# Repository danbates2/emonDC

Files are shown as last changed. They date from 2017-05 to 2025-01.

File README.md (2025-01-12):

# **emonDC**

emonDC is a project aiming to develop DC current and voltage measuring tools compatible with openenergymonitor.org project.<br>
The main board in development is emonDCduo, a dual-channel generator/battery monitor, WiFi enabled, aimed at solar/battery systems.

### Project status: Reviewing Project. Develoment Units not available.

#### https://shop.openenergymonitor.com/

<br/>

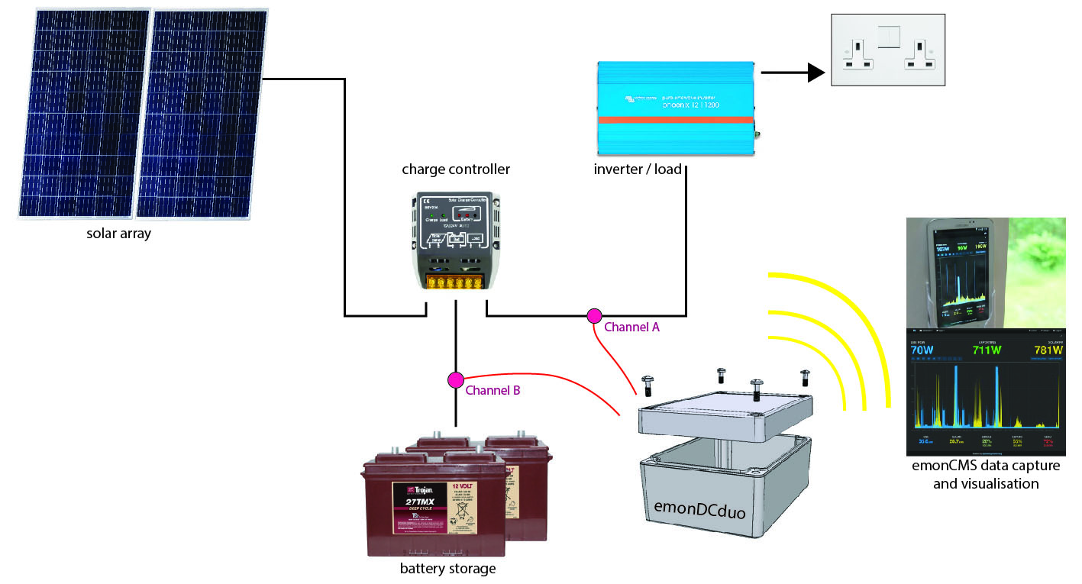
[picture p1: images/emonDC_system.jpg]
Example System Schematic


## Target Uses

- 12V, 24V and 48V Solar PV systems, up to 65V
- Battery monitoring.
- Remote DC datalogging.

**Be safe. Extra-low voltages can still mean high currents.**

[Find Documentation on some fundamental DC monitoring concepts in the 'doco' folder, which contains a reference pdf.](/doco/)

## Contents
<!-- toc -->
- [Target Uses](#Target-Uses)
- [Features](#Features)
- [Hardware Options](#Hardware-Options)
  * [The Shunt](#The-Shunt)
  * [Internal Shunt Cable Terminations](#terminations-for-onboard-shunts-up-to-50amps)
  * [External Shunt](#terminations-for-external-shunts)
  * [Power Supply](#power-supply-options)
  * [Enclosures](#Enclosures)
  * [Extra Modules](#module-options)
- [Firmware](#Firmware)
- [Customisations](#other-customisation)
- [Setup Guides](#setup-guides)
- [Support](#online-support)
- [Safety](#Safety)
- [DC Monitoring Approaches](#approach)
- [Project Aims](#project-aims)
- [License](#license)

<!-- tocstop -->

## Features

Latest spec:

- Two-channel high **only** DC current and voltage sensing, up to 64.4V or 75V, suitable for a wide range of low-voltage generator/battery systems.
- 50Amps onboard shunt rating or 1000A external shunt rating.
- Hall-effect current sensor footprint alternative for isolated current only measurement.
- Waterproof, clear-top plastic case.
- 128 x 32 OLED display option.
- WiFi Connectivity.
- Low-power mode (10mA draw).
- Accurate 12-bit ADC.
- Over-voltage and reverse voltage protected (fuses).

Also:
- It can function as independent unit self-powered using an onboard buck regulator module, powered from either measurement channel. Data can be stored locally to a MicroSD card, keeping time with on-board RTC and coin-cell.
- Radio transmission of data possible through RFM69Pi module.
- Voltage divisions for reference voltages easily modified by soldering for maximum resolution for given system.
- The I2C port can connect control boards for power management, in development.
- Skipping wireless transmission, a physical cable UART connection is possible, compatible with RS485 pending testing.
<br>

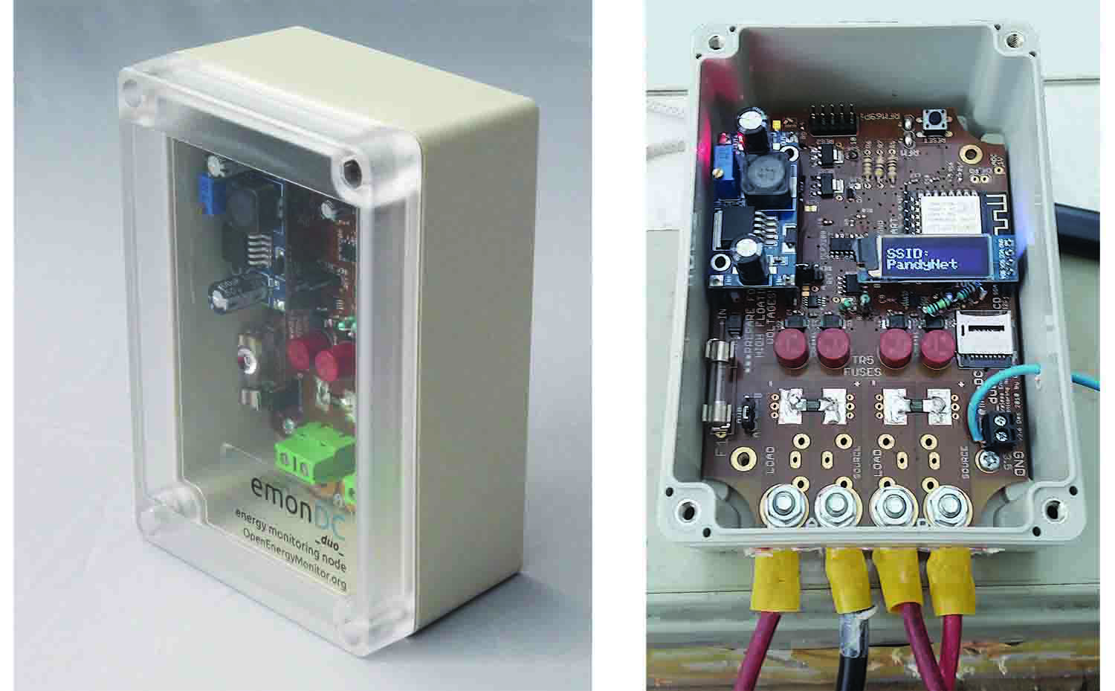
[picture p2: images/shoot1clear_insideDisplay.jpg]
 

<br>
<br>

## Hardware Options

emonDCduo as designed here has shunt, termination, power-supply and other module options.<br>
[See this demo video of the options](https://vimeo.com/319164161), listed below in detail.

#### The Shunt
Onboard @ 50Amps max  ||  External @ 1000Amps max.<br>
Onboard shunts should be selected to not dissipate more than 50% of their rated value continuously [shunt power calculator](https://github.com/danbates2/emonDC/tree/master/calculators).

#### Terminations for Onboard Shunts (up to 50Amps)
- For 10mm2 cable (50Amps approx). [10.16mm pitch Terminal Block](https://raw.githubusercontent.com/danbates2/emonDC/master/images/v3.6_terms_10.16mm.jpg), such as [this](https://uk.farnell.com/2668653).
- For 4mm2 cable  (25Amps approx). [7.62mm pitch Terminal Block](https://raw.githubusercontent.com/danbates2/emonDC/master/images/v3.6_terms_7.62mm.jpg), such as [this](https://uk.farnell.com/2579818).
- For 6mm2 cable (35Amps approx). [5mm Ring Terminals bolted on](https://raw.githubusercontent.com/danbates2/emonDC/master/images/v3.6_terms_ring.jpg). Ring terminal outer-diameter not exceeding 11.0mm.  
- [Directly soldered cable](https://raw.githubusercontent.com/danbates2/emonDC/master/images/v3.6_terms_bare.jpg), using the bolt mounts.

#### Terminations for External Shunts
- Any of the above, 7.62mm pitch Terminal Block recommended.
- [Example of external shunt (external link)](https://uk.farnell.com/1339341).

#### Power Supply Options
Using a buck regulator the board can be self-powered from either current sense channel.

-  [My own DC-DC buck regulator](https://raw.githubusercontent.com/danbates2/emonDC/master/images/buck_reg_green.jpg) featuring under-voltage lockout for battery protection, adjustable output voltage, rated at 3A for 10s or 1A continuous.
_note: using an onboard buck regulator is preceded by fuse F1._

- The [LM2596 buck modules on ebay](https://raw.githubusercontent.com/danbates2/emonDC/master/images/LM2596_dc-dc_buck_module.jpg), shown [here](/images/buck_reg_blue.jpg) fitted.
_note: using an onboard buck regulator is preceded by fuse F1._

- [5V input with 5.08mm pitch Terminal Block](https://raw.githubusercontent.com/danbates2/emonDC/master/images/v3.6_terms_v5input_block.jpg) for 5V direct input. I could not enable a USB connection for the safety reasons in floating-ground systems.

<br>

#### Enclosures

emonDCduo has been designed for waterproof plastic enclosures from Lincoln Binns.
<br>
Holes can be drilled easily, or prepared units can be bought from the OpenEnergyMonitor shop.
<br>
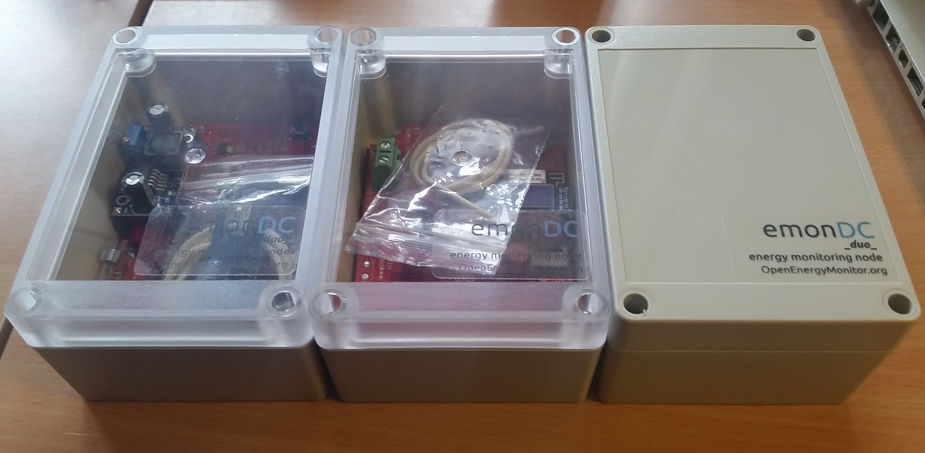
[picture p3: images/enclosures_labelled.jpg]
See image.


<br>

#### Module Options
**I2C modules:**
- **128x32 I2C OLED Display module** cycles through real-time and daily data, including network information if connected.
- **RTC based on PCF8523**, with coin cell backup, parts sold as kit.
- Any I2C control module can be fitted in parallel. Search for 'i2c io expander module board' for some options, PCF8574 and PCF8575 based modules have been tested and work fine.
<br>

**Other modules:**
- **RFM69Pi radio module** from OpenEnergyMonitor, typically 433MHz.
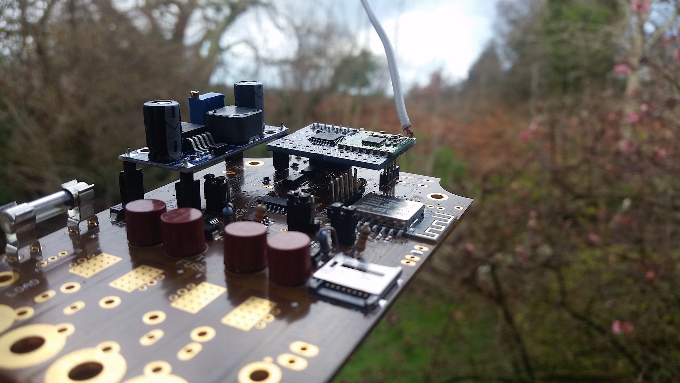
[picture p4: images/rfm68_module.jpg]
The board sets sail with a RFM69Pi module

The board sets sail with a RFM69Pi module
<br>

<br>

## Firmware

Find firmware here:<br>
https://github.com/danbates2/emonDC/tree/master/firmware<br>
It is based on emonESP, and detailed instructions on compiling and uploading the firmware can be found in it's documentation. <br>
https://github.com/openenergymonitor/EmonESP
<br>
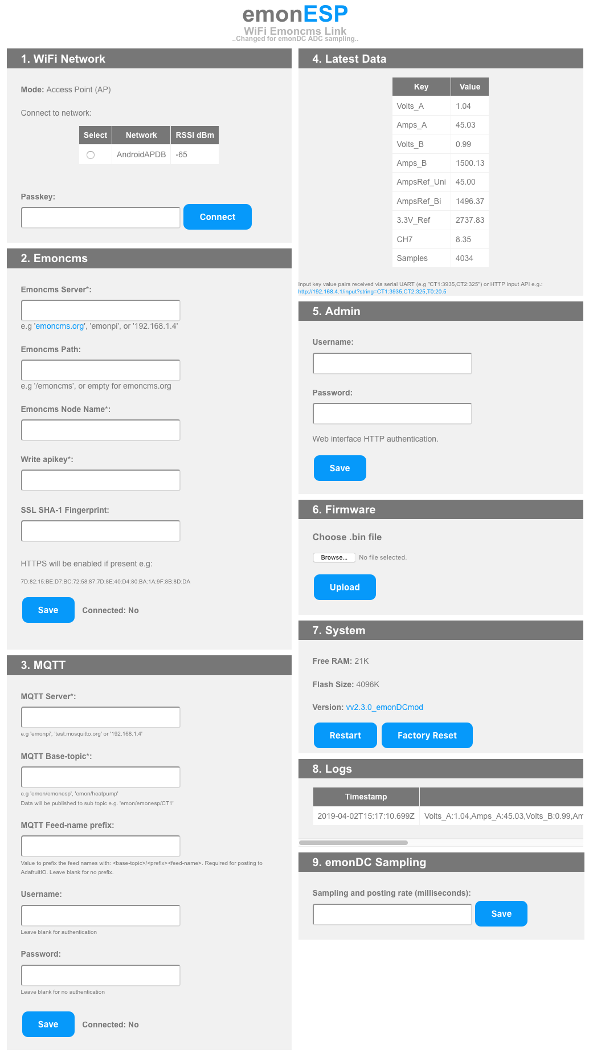
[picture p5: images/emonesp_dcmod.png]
Firmware web-interface screengrab


<br>

## Other Customisation

Below are a set of images outlining some other customisations.
<br>

- [GND connections, for the power-supply earth with a 4mm ring terminal on a mount. The terminal block for a gnd connection or shunt-lead shielding, if used.](https://raw.githubusercontent.com/danbates2/emonDC/master/images/v3.6_overlay_gnd.jpg)
- [5V input location.](https://raw.githubusercontent.com/danbates2/emonDC/master/images/v3.6_overlay_5v.jpg)
- [Power Select header, for bringing power into an on-board buck regulator, if used.](https://raw.githubusercontent.com/danbates2/emonDC/master/images/v3.6_overlay_pwr.jpg)
- [Reference voltage and line voltage divider resistors.](https://raw.githubusercontent.com/danbates2/emonDC/master/images/v3.6_overlay_resistors.jpg)
- [Shunt amplifier 'reference select' headers, for uni or bi-directional measurement.. Typically generator (uni-directional and battery (bi-directional).](https://raw.githubusercontent.com/danbates2/emonDC/master/images/v3.6_overlay_refsel.jpg)
- [RFM69Pi headers.](https://raw.githubusercontent.com/danbates2/emonDC/master/images/v3.6_overlay_rfm.jpg)
- [3D Printed Case.](https://raw.githubusercontent.com/danbates2/emonDC/master/images/3dprinted_case_1.jpg)
- [Lightning protection using Gas Discharge Tube (GDT) (external link).](https://uk.farnell.com/1843306)

## Setup Guides

*Plan your cabling and equipment to allow installation of this energy monitor.*<br>
*Have an understanding of [shunts](https://en.wikipedia.org/wiki/Current_sensing#Shunt_resistors), [high-side vs low-side shunt monitoring](http://www.worldofindie.co.uk/?p=216), and whether or not your electrical Ground needs earthing or can float.*

#### Example 1; 'standard' emonDCduo with enclosure, ring terminals and on-board power supply.

Tools needed: screw driver / drill, crimper / pliers, 8mm spanner or ring socket (ring socket easier). And of course, something to cut cable and strip the plastic insulation from the ends.

When looking at the PCB board top-side, the inputs are labelled 'source' and 'load'. The source is connected to the current origin (+ive side of shunt) and the load is connected to the destination (-ive side of shunt).

- Mount enclosure, then mount PCB with bolts ready.
- Connect current-carriers, cut cables and crimp on the ring terminals.
- Power up and log in via WiFi to enter credentials and other emonESP settings.

<details><summary>Detailed instructions (spoiler alert!) :</summary>
<p>

1. Purchase 'standard' board through Megni shop, select hardware options to complete purchase.
2. Take the enclosure and drill out access according to [this diagram]() (pre-drilled available from shop).
3. Select a location near the current carrying cables and mount the empty enclosure, screwing or bolting it to a surface.
4. You need two M5 bolts for each current channel. Put a serrated washer on each bolt, insert the bolts from the underside of the PCB, and then mount the PCB with the bolt threads showing, perhaps applying sideways pressure to the bolt to keep them from falling out.
5. Use the M3 screws provided to mount the PCB to the enclosure.
6. **Disconnect power from cables to be cut.** Make the cuts and strip 15mm from the ends.
7. With a crimping tool or pliers, crunch the ring terminals onto the copper cable ends, you should not be able to pull the cable out of the crimped end..
8. Note the 'source' and 'load' labelling on the board, bring the ring terminals onto the bolts and place the flat washer, then fit the nut.
9. Tighten all bolts holding onto the crimp to keep it from spinning, the serrated washer will eventually grip and greatly help to make it tight.
10. Connect the earth via the terminal or a by using a small ring under a mounting screw.

11. Install buck-regulator, power up and log in to to the device by WiFi, here you can enter emoncms credentials, and other settings as found in emonESP.

</p>
</details>

#### Example 2; 'minimal' PCB, with enclosure, 5V input block, and external shunts.
Soldering required for minimal functioning shown below.<br>
Then solder in two 5.08mm terminal blocks for the 5V and GND inputs.<br>
Then [7.62mm terminal blocks](https://raw.githubusercontent.com/danbates2/emonDC/master/images/v3.6_terms_7.62mm.jpg) (recommended) for connecting external shunts.
<br>
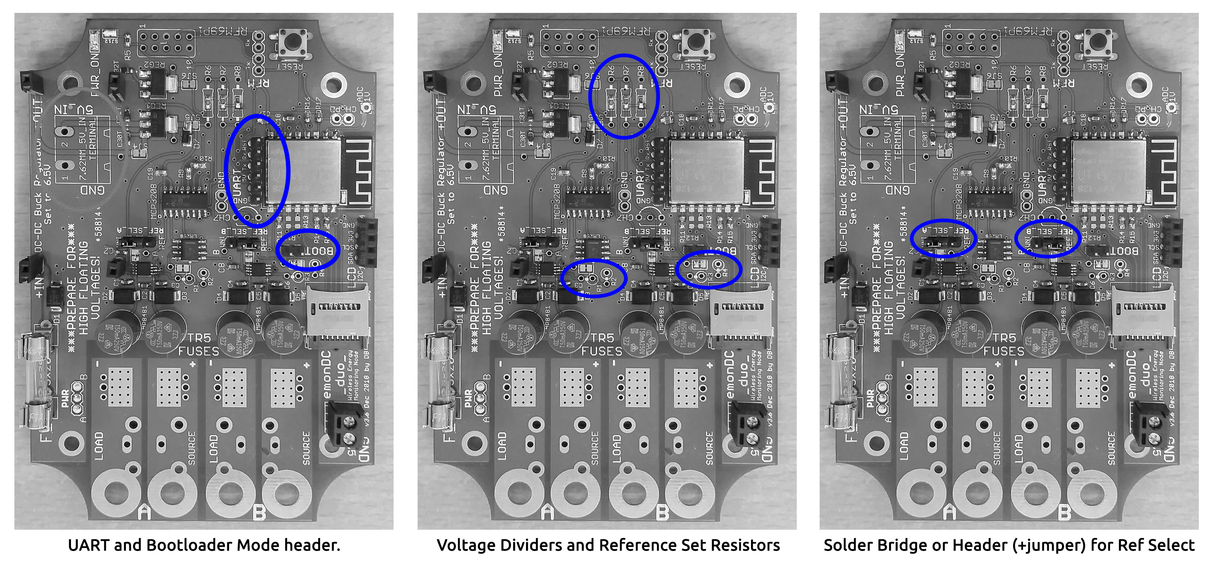
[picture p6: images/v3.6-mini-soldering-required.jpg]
Soldering Required


## Online Support

. Find answers, post questions, or msg me directly at https://community.openenergymonitor.org/  .  My username is @danbates

. Raise issues through this repo at the Issues tab.

<br>

## Measurement of direct current (DC).

This is a project description but also a collection of ideas and findings.
The diversity of approaches could be illustrated by these two websites:
- https://www.coolcomponents.co.uk/attopilot-voltage-and-current-sense-breakout-180a.html
- http://www.victronenergy.com/upload/documents/Datasheet-Battery-monitoring-EN.pdf

## Safety

**It's often good practice to disconnect the power before working on cables even in extra-low voltage systems**

**Be aware of working voltages!**

**Be aware of available Amperage, and the possibility of strong currents even in extra-low voltage systems.**

**Isolation.** The protection of users and connected devices from floating ground voltages in certain applications is very important. The approach at present is to make use of suitable physical isolation and warning labels. Bright warning labels stating ‘disconnect DC system before connecting UART’ or ‘ensure common ground between DC system and other devices to be connected’ or something similar, pending advice.
<br/>

Secondly, short circuit protection needs to exist at different levels of the hardware design to avoid inadvertent damage to the unit, by assembly faults on part of the manufacturer (PCB and assembly) or assembler, or the user upon installation. This has been achieved by adding fuses and buffering certain inputs with resistors. The layout of the components factors into the safety significantly!
<br/>

Thirdly, transient and reverse voltage protection. The TVS diodes specified seem to do a good job. I've taken a sparker from a cigarette lighter and shoved a few kV into the inputs while it was running. It worked just fine, after a reset.
<br/>

The unit is defined as a Protected Extra-Low Voltage (PELV) device, and should be, if all goes well, CE certified for safety.

## Approaches
Hall-effect DC monitoring ICs are simple and provide a degree of electrical isolation, however, they are inflexible and costly. This will certainly change in time as the technology develops.
<br/>

Shunt monitoring potentially provides greater flexibility, high accuracy and cost-effectiveness, and is the route selected for emonDCduo.

1. The range of requirements in DC monitoring applications require a flexible approach because of:<br/>
a. Unidirectional vs bidirectional measurement needs.<br/>
b. Amperage ranges and associated cable cross sectional area. Current carriers in DC systems can range from 4mm<sup>2</sup> to over 25mm<sup>2</sup>. The target measurement range has significant physical design implications.<br/>
c. Different cable dimensions require terminations suitable to their size and application (screw terminals, bolt ring terminals, soldered connections, etc.) there is no single solution.<br/>
d. Whole battery systems can be monitored with one shunt or individual cells of the system can require a multi-cell monitoring unit.<br/>
e. I also consider high humidity, marine and automotive applications, and have designed DCduo for a waterproof case.<br/>
f. A wide range of working voltages.

2. When I consider cable sizes and suitable cable terminations, the design challenge of making a suitable unit for a wide current range makes it difficult to see any one PCB realistically and cost-effectively meeting ALL requirements. Unlike in many AC requirements where a different CT and burden resistor can be selected, DC demands a more targeted approach due to the different physical dimensions of suitable terminations.
This possibly leads to the solution of designing several different boards according to the different requirements.
I'm designed emonDCduo to be an allrounder as much as possible, with the option of external shunts for amperages up to 1000A.

  The approach selected for first production has been dubbed emonDCduo, onboard shunts and pheonix connectors for external shunts ensure flexibility.

3. Given the nature of solar, wind and various DC applications there a requirement for a buck regulating supply, probably isolated. There needs to be a regulated and smooth output for powering the shunt monitor and other ICs.

5. Failsafe monitoring... Fuses between the shunt and monitor to protect from short circuit conditions. Do the fuses need monitoring?

6. High-side vs. low-side sensing… It'd be useful if this shunt monitor was capable of handling both applications, which means using a shunt monitor IC capable of high-side and low-side measurement. The device should ideally handle a wide common-mode voltage range, say up to 80V, and protection be in place for voltage over the common-mode voltage limit of the chip.

## Wider Project Aims

- Education on working with installing hardware, cabling, the use of tools and various practical aspects.
- Create as flexible as possible unit. Aiming primarily at domestic solar, wind and battery applications.
- Compare hall-effect type to shunt monitor type DC measuring approaches, particularly in relation to safety, accuracy and flexibility, as the tech develops.
- Integrate wireless Tx function using RFM69Pi.
- Integrate LAN cable connectivity.
- Investigate a calibration routine.
- Review case design periodically.
- Look at the energy efficiency of different manufacturing approaches.
- Make units!

**Questions…**
- What’s the relationship to different amperages, cables sizes and suitable cable terminations at the device?
- How high a current can the PCB copper layer handle?
- How does heat dissipate through the PCB and how does this effect the value being monitored? Is a temperature sensor required for factoring in temperature drift?

Several spinoff boards have derived of this project, in various stages of completion, the latest being the ACS770 or 772 series hall-effect current sensor breakout board. Also, an isolated FTDI adaptor, emonDCmini targeted at single channel DC monitoring with WiFi capabilities, and an emonDC shield for Arduino pattern.
<br><br>
What I'm calling emonBuck is also available, as a switching buck regulator with low-voltage lockout and adjustable output. 1Amp rated, 3A for 10 seconds.

## License
- Hardware licensed according to the TAPR Open Hardware Licence v1.0. Documentation free to use and change with accreditation to Daniel Bates @danbates2.
https://www.tapr.org/TAPR_Open_Hardware_License_v1.0.txt
- Software licensed licensed to GNU General Public License v3. Free to use and change with accreditation to OpenEnergyMonitor.org.
https://www.gnu.org/licenses/gpl.html

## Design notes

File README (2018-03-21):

emonDC
Project status: in production. expected release May 2018.

Measurement of direct current (DC).
This is a project description but also a collection of ideas and findings. All thoughts welcome.
The diversity of approaches could be illustrated by these two websites:
https://www.coolcomponents.co.uk/attopilot-voltage-and-current-sense-breakout-180a.html
http://www.victronenergy.com/upload/documents/Datasheet-Battery-monitoring-EN.pdf
My approach won’t be the only way but you’ll get an idea as you read on. Hopefully it makes sense. I welcome any and all feedback and hope for this to be as complete a project in theory before I begin schematic and PCB designs. Hey, I might even be close to making a decision by now… Also, this isn’t intended to claim ownership of the idea, if anyone wants to pick up the pieces and go for it they’re welcome.

emonDC Project
This unit will be a dual  shunt-monitoring device with wireless Tx capabilities. The device will be powered from the DC voltage source it is measuring, or from batteries. Because of potential outdoor applications the form will make possible the use of Waterproof I.P. rated boxes. A metal case matching emonTX style needs looking at also. The unit design will aim primarily at domestic DC applications, for example, solar photovoltaic and wind generation systems with either grid-tie inverters or battery systems.
Safety needs consideration in different ways. Firstly, short circuit protection needs to exist at different levels of the hardware design to avoid inadvertent damage to the unit, by mal-assembly on part of the manufacturer (PCB) or user (installation). This can be achieved with adding particular components, such as fuses and backup series resistors, in the event of a short. The layout of the components will factor in safety also.
Secondly, protection of connected devices and users from floating ground voltages in certain applications. This can be achieved with a bright yellow warning label stating ‘disconnect DC system before attaching USB/FTDI’ or ‘check for common ground between this unit and devices to be connected before making connection’ or something similar, pending advice.
Hall-effect DC monitoring ICs are simple and provide a degree of electrical isolation, however, they are inflexible and costly. Shunt monitoring provides much greater flexibility, accuracy and cost-effectiveness.

1. The range of requirements in DC monitoring applications require a flexible approach because of…
a. Unidirectional and bidirectional requirements.
b. Amperage Ranges and associated cable cross sectional areas (CSA). For example, household 100A cables are 25mm2 or 16mm2, whereas wire for headers and breadboard carrying up to about 5A are about 0.9mm2. The target measurement range has significant physical design implications. 
c. Different cable/wire CSAs require terminations suitable to their size and application (screw terminals, bolted bus bars, soldered connections, etc.) there is no single solution.
d. Whole battery systems can be monitored with one shunt or individual cells of the system can require a multi-cell monitoring unit.
e. There are also high humidity, marine and automotive applications.

2. If we consider cable sizes and the range of amperages in terms of a suitable termination, the issues make it difficult to see any one PCB realistically and cost-effectively meeting all requirements.
This possibly leads to the solution of designing several different systems according to the requirements. First suggestions might look like:
emonDC50 – Bidirectional DC monitor with integrated yet replaceable / bypassable shunt, accepting up to 6mm2 cable up to 50A, but with customizable sensitivity down for micro amps.
emonDC500 – Unidirectional shunt monitor with external shunt rated up to 500A.
emonDC500duo – Two unidirectional shunt monitors in parallel for measuring two external shunts rated up to 500A, for battery/generator applications.

3. Another option might be to have a two-part system where Tx functions are separated from shunt monitoring functions in two separate PCBs, connected via RJ11 or ribbon cable. This could lend itself to multi-source monitoring effectively. Several different model of the DC monitoring PCB could be developed for a range of applications. Also, the standalone Tx PCB may lend itself to other emon projects in the future.

4. Given the nature of solar, wind and various DC applications there a requirement for a protected, regulated supply. Protected from over voltage. Regulated, smoothed output for powering the shunt monitor, Arduino and RF chip.

5. Failsafe monitoring... Fuses between the shunt and monitor to protect from short circuit conditions.

6. High-side vs. low-side sensing… This shunt monitor needs to be capable of handling both applications, which means using a shunt monitor IC capable of high-side measurement. The device should ideally handle a large common-mode voltage, say up to 80V, and protection be in place for voltage over the common-mode voltage limit of the chip.

Project Aims
Follow on from previous research.
Create as flexible as possible unit. Aiming primarily at domestic solar and wind applications.
Compare hall-effect type to shunt monitor type DC measuring approaches, particularly in relation to safety, accuracy and flexibility.
Integrate wireless Tx function using RFM69CW.
Explore potential for AC monitoring applications.
To ascertain for certain the viability or necessity of a two part system. Such as Part A: Tx PCB and Part B: DC monitoring shield.
Investigate a calibration routine storing data in EEPROM.
Look at case design.
Look at the energy efficiency of different manufacturing approaches.
Make a unit!

Unit Features
Focusing on the proposed emonDC50…
Single PCB approach.
emonTx functions including RF and Arduino.
DC monitoring chip capable of bidirectional monitoring for 24V wind and solar systems.. common mode voltage capability of 40V ish..
Screw terminal or soldered connections accepting 6mm2.
Replaceable shunt or perhaps a jumper to disconnect the onboard shunt, then through holes for connecting a specified resistor.

Questions…
What’s the relationship to different amperages, cables sizes and suitable cable terminations at the device?
Would a particular amperage range require soldered connection? Do specific applications require soldered connections?
Could the PCB safely handle the required amps? What’s the current carrying capacity of header pins and PCB track?
Can PCB track be used as the shunt?
How does heat dissipate through the PCB and how does this effect the value being monitored? Is a temp sensor required for factoring in temperature drift?

Notes:
In wind and solar applications cable is often sized according to the length of the run from the generator to the batteries, in this instance the installer will have to adapt for the relevant termination.

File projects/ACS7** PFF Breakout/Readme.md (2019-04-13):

[https://community.openenergymonitor.org/t/acs770-hall-effect-sensors/8675](https://community.openenergymonitor.org/t/acs770-hall-effect-sensors/8675)

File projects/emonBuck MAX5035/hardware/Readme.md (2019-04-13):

[https://community.openenergymonitor.org/t/dcduo-board-update/9189/13](https://community.openenergymonitor.org/t/dcduo-board-update/9189/13)

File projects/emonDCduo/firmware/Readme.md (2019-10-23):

See emondc.cpp for user-defined variables.
<br>
Based on emonESP, modified for emonDC with: <br>
- Uses the MCP3208 12-bit adc.
- OLED Display support.
- RTC support.
- MicroSD Card support.
- <br>
[https://github.com/openenergymonitor/EmonESP](https://github.com/openenergymonitor/EmonESP)

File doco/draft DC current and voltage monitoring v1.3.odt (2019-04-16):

- - - DC Monitoring - - -

Direct Current (DC) is a current flow that is usually going in one direction. Batteries are the original, the most common and easiest to understand example of DC supply: mobile phones, laptops and automobile batteries produce DC. Batteries can accept charge or be discharged. For charging, current will flow in a particular direction, and for discharging, the current will flow in the opposite direction. 'Forward current' might be used to describe the current flow during typical operation of a device, and 'reverse current' might be used to describe the atypical state.

To compare, Alternating Current (AC), alternates between positive and negative voltage, or forwards and reverse current, a number of times per second. Just like how 'AC' can be used to means alternating voltage, DC can also be used to mean continuous positive or negative voltage, although it's usually prefixed with a V, as in +1.5VDC.

Direct Current (DC) measurement is also called DC sensing.

What’s covered here is measurement of direct current and voltage towards digital information. Analogue measurement methods exist and have been around since the beginnings of discovering electricity, but won’t be covered in detail here.

Contents

- - - DC Monitoring - - -

Current Sensing

Shunt Monitoring

Hall Effect Current Sensors

Current Sensing Summary

Voltage Sensing

Safety in Voltage Sensing

The Voltage Divider

Buffered Voltage Signals

Safety

Working Voltages

Available Current

Floating Ground

Galvanic Isolation and DC Voltage Sensing

Appendices

Current Sensing

To monitor DC, there are two main technology categories - shunt monitors and hall effect current sensors.

Shunt Monitoring

This method uses the current sense resistor, or shunt. These are typically low resistance, specially designed metal-alloy resistors, which maintain a fairly constant resistance value over a wide temperature range.

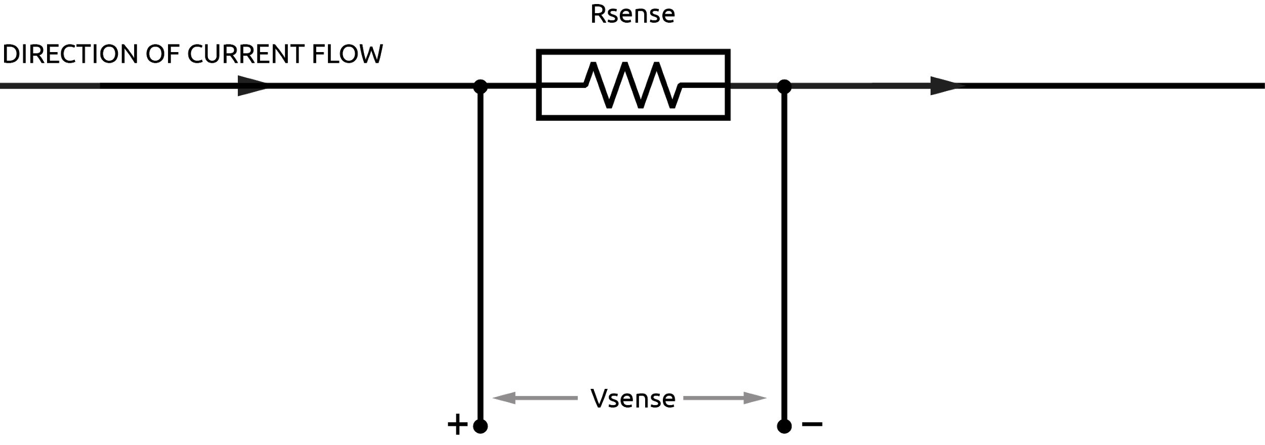
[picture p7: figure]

In this simple model, current flows through the shunt resistor and a small voltage is produced across it. The voltage drop is proportional to the current flow. Vsense is typically in the millivolt range. Many shunts are specified at a particular current range for a 50 or 100 mV maximum sense output.

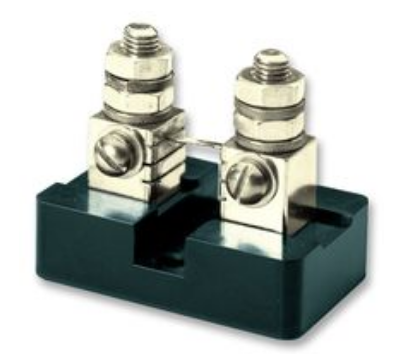
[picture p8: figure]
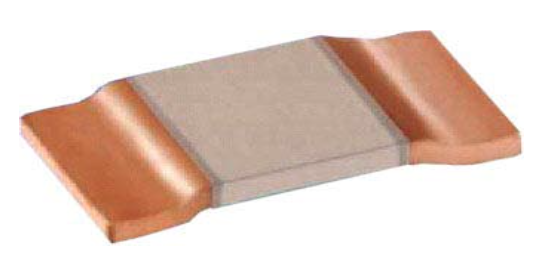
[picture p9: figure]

Image 1A Image 1B

Soldered PCB Mounted Shunt. Credit: Ohmite Panel Mounted Shunt. Credit: Murata Manufacturing

(around 50A max., around 20mm wide) (around 500A max., around 100mm wide)

The next step is to amplify the millivolt signal coming from the shunt resistor. To select an amplifier we must understand high-side and low-side current sensing.

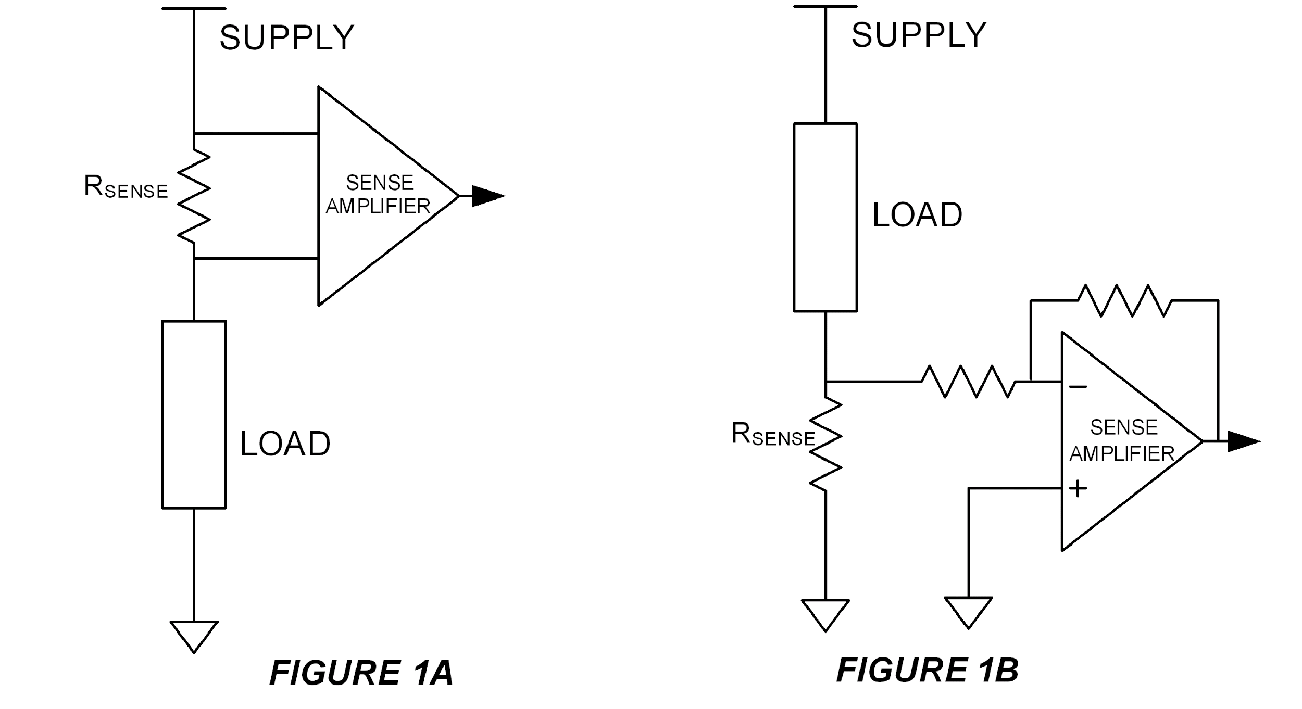
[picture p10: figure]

Credit : User ElectronS at https://electronics.stackexchange.com/

In figure 1A we have high-side sensing, and in 1B low-side sensing. Low-side has the advantage of cheap circuitry and simple implementation with standard op-amps. However the load circuit may be sensitive to the offset ground voltage cause by the small resistance of the sense resistor which has been located between the main circuit and ground, i.e. the load is not connected directly to ground.

High-side sensing allows the load circuit to be directly connected to ground, but requires a differential amplifier. This is an amplifier accepting signals at or above the amplifier's supply voltage. It rejects common-mode voltages, that is, voltages common to both +ive and -ive inputs of the amplifier, meaning all it reads is the difference between the inputs. When the common-mode input voltages are above the amp's supply voltage, this is called over-the-top sensing. High-side sensing has the important advantage of short-circuit detection. Look again at the diagram, and you can see that if a short-circuit fault appeared in a low-side configuration, it would not be detected, whereas in the high-side configuration it would.

The main advantages of shunt based sensing are versatility, easily selected current range, accuracy, and a long history of use.

Hall Effect Sensing

Hall effect sensing takes advantage of the magnetic field produced by the current flow in a conductor. A small magnetically sensitive sensor is used to divert a tiny proportion of electromagnetic energy “sideways” from the main current conductor, or transversely to the magnetic field. The Hall effect itself is the voltage being produced in the sensor, it was discovered by Edwin Hall in 1879, and is still as mysterious as magnetism itself.

There are two main categories of hall effect sensors, open-loop and closed-loop.

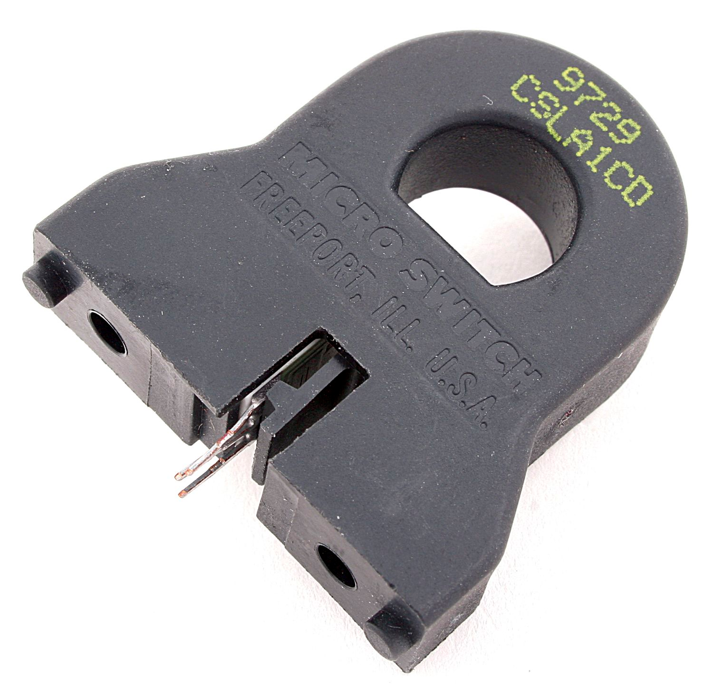
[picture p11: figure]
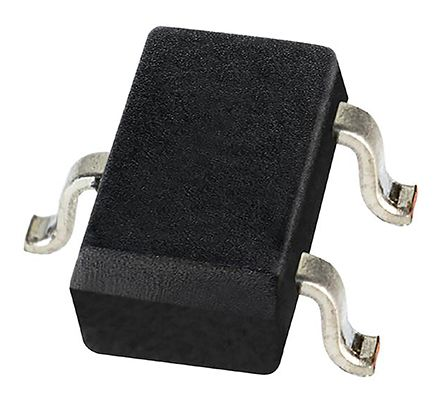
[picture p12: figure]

Image 2A: Open-loop sensor Image 2B: Closed-loop sensor

Hall effect sensors have the distinct advantage of in-built isolation from the current carrying conductor. In their open-loop form in particular, no break in the carrier cable is necessary for current measurement. This can be very useful for not having to create or change any cable terminations.

The closed-loop forms are almost always integrated circuits (ICs) as shown above, ensuring the main current path comes in close proximity to the Hall magnet, these ICs are mounted onto PBC, which has the cable termination. Heat dissipation is designed into most of these ICs, and some are rated as high as 200Amps. They are available as uni-directional and bi-directional devices.

The main disadvantage is the fixed current range of the device.

Other potential issues are accuracy, drift with temperature, sensitivity to magnetism and cost.

The isolation benefits can override the issues in many cases.

A trick with the open-loop form is to wind the cable through the aperture more than once, for example the reading from a 10A max cable can be doubled with an extra winding for a 25A max sensor, this simple trick makes larger open-loop devices more versatile, able to be used for lower-current cables.

The resistances of hall-effect sensors are typically very low, and are referred to as 'Rsense' just like shunts.

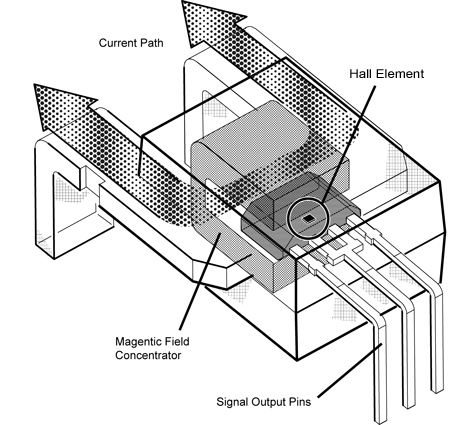
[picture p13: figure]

Figure 3 - High current Hall Effect current sensor Source: “https://www.allegromicro.com/en/Design-Center/Technical-Documents/Hall-Effect-Sensor-IC-Publications/Integrating-Hall-Effect-Magnetic-Sensing-Technology-Into-Modern-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”

Hall effect sensing has the general advantage of isolation, that is, isolation from the high-side positive voltages or floating voltage level of the conductor. In the safety section to follow this will be described in more detail.

Hall effect current sensing can have the advantage of simplicity, as the ICs can handle transients, isolation, amplification and error correction in one. The limitations are being overcome, so it’s worth keeping an eye out on this field if you’re interested in DC monitoring.

Current Sensing Summary

There are a wide range of sensors that are capable of both shunt resistor and hall-effect based sensing.

Shunt based sensing is versatile, is fairly simple to implement and has a long history of applications. A wide range of methods are shown in Linear Technology's Application Note AN105 (http://www.analog.com/media/en/technical-documentation/application-notes/an105fa.pdf).

Hall-effect type, especially open-loop, have potential for simple implementation of current only measurement and the associated cost-benefit. The high +ive and floating voltage isolation is also a great advantage.

Voltage Sensing

Safety in Voltage Sensing

With DC, the cables must be physically altered to gain access to the voltage level. The cable must be cut, tapped, crimped, bolted onto, soldered onto or screw-terminated to get the voltage reading. Safety is an important part of this process.

The guidance in Europe is that anything above a working voltage of 75VDC is potentially harmful. This means that all work practice around voltages above 75VDC done so as to never have bodily contact with these voltages in any way.

Note that for generators (solar panels, wind turbines etc.) the floating voltage may be above the working voltage. Proceed with great caution with floating (non-earthed) generators.

Voltages below 75VDC are very dangerous if great amounts of current are available. Even 12V systems can provide huge bursts of current, creating arcing, fusing, and tremendous heat. Current can be dangerous in a different way to voltage, but is still dangerous.

Voltage Divider

A simple voltage-level manipulation technique is the voltage divider, or potential divider.

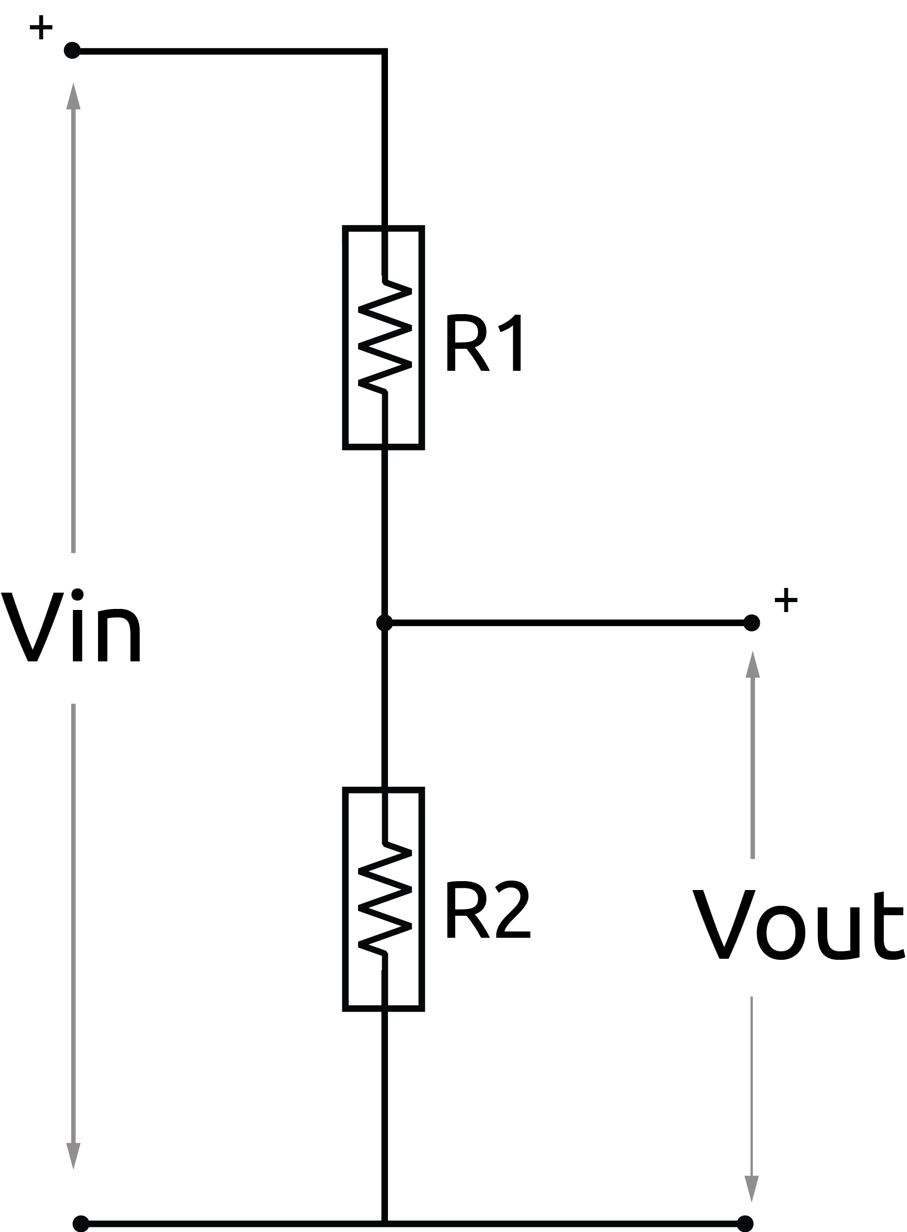
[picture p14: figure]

Here, the output is proportional to the input, and the ratio of (R1+R2) / R1. Fully expressed below as:

First, the resistors need be selected for the target input and output voltage range, in other words the target ratio.

Next, the resistance values must be high enough to minimise current and the associated heating effects, which could create either a temperature based inaccuracy or cause a failure of one or both resistors. The failure of a resistor can result in an open-circuit or short-circuit, in particular a short could be a significant issue.

Resistance values too high can introduce noise and high impedance to the next stage of the circuit and make accuracy difficult.

Learn more about a simple divider (external link). (http://www.learningaboutelectronics.com/Articles/How-to-divide-voltage-in-half-with-resistors.php)

The resulting situation from a high-resistance selection, for example a 10MOhm resistor at R1 and 100kOhm at R2, is the low source current available at Vout. If the resistor values have been selected such as to minimise power losses, then it’s likely that a high impedance output will be seen at Vout. This is important for analogue-to-digital converter (ADC) inputs.

The source impedance seen by a load across Vout the simple voltage divider is equal to the parallel resistor calculation:

Source: https://www.electronics-tutorials.ws/resistor/res_4.html

The 10Mohm || 100kOhm combination works out at as an impedance of 99kOhm seen by the load across Vout.

ADCs normally require low-impedance inputs, this is because of the sample-and-hold architecture (SHA) of many ADCs. SHA requires that: 1. a small capacitor is charged in a defined time period, hence needing current available, and 2, the charge held long enough for analog-to-digital conversion to take place.

Generally, a voltage sensor has high impedance in the kilo or mega Ohms, and may use a buffer and an analog-to-digital converter (ADC) before sending the information to an MCU.

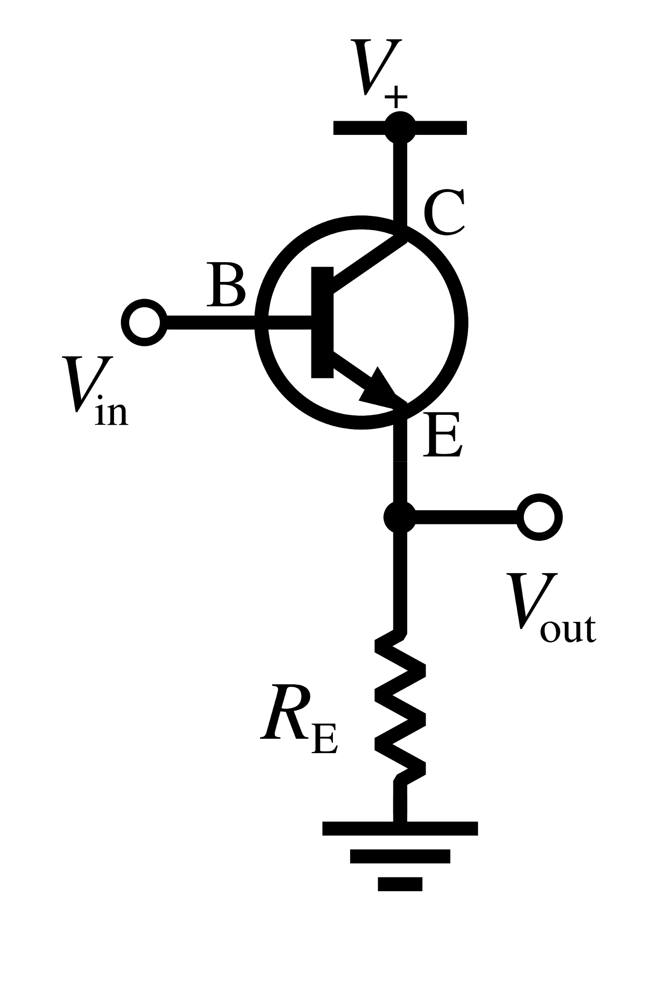
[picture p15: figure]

Buffered output/input:

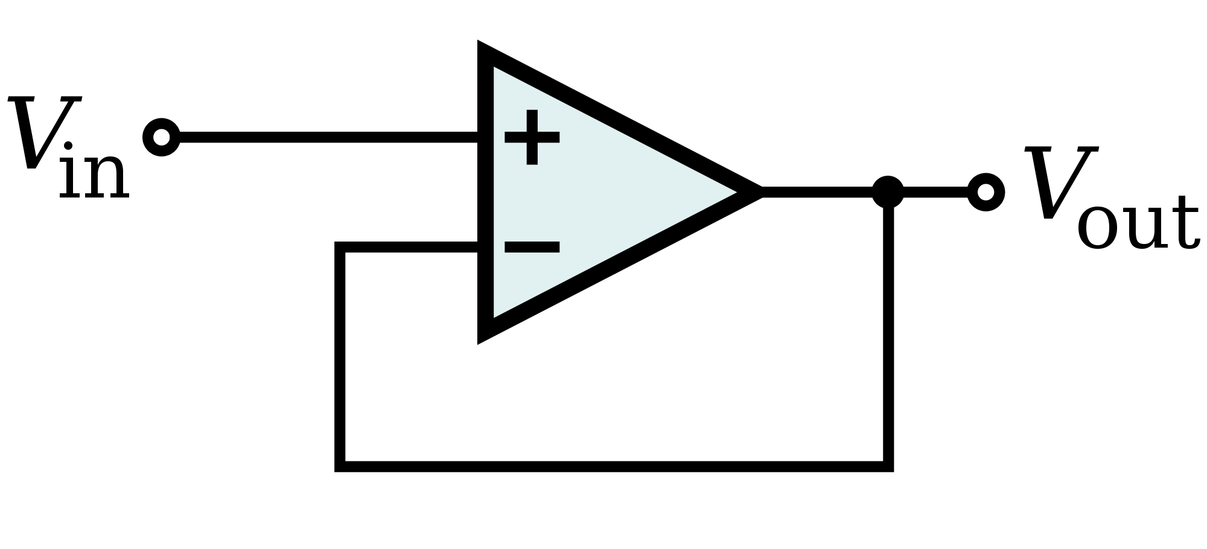
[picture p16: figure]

Figure 4A - Voltage follower using an op-amp.

Figure 4B - Transistor based buffer.

To make more current available a buffer, also known as a voltage follower, is used. A buffer will take a voltage signal and can output it at a particular ratio, say 1:1 (no voltage amplification) while making available on the output side greater current. This provides the current necessary for the ADC input.

To repeat, a buffer in this case is usually a 1:1 amplifier, which takes an input voltage and outputs the same output voltage, with the added power of the amplifier’s transistors, giving the output voltage greater available current / lower output impedance. Greater current available enables the ADC to sample more accurately and faster.

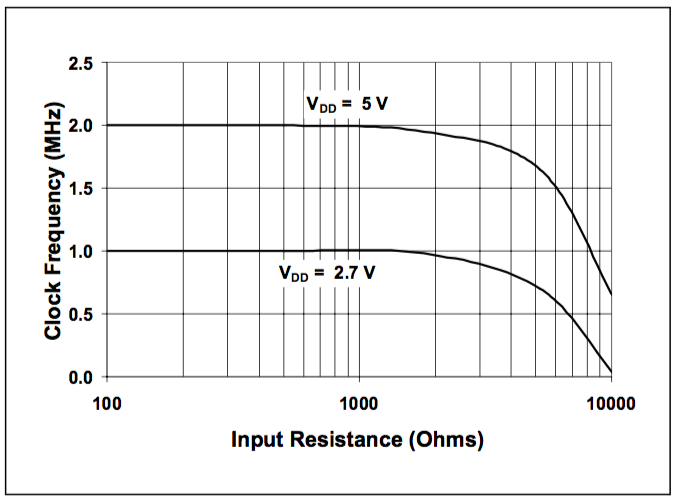
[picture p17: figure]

Figure 5 - Maximum Clock Frequency vs. Input Resistance of the MCP3208 (to maintain less than a 0.1 LSB deviation in Integral Nonlinearity from nominal conditions).

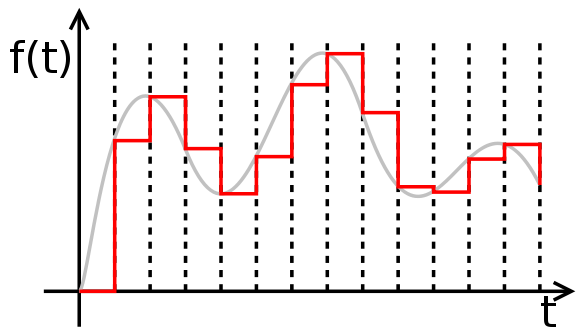
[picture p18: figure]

Figure 6 - Sample and hold for varying input: From en:User:Petr.adamek and previously saved as PD in PNG format. touched up a little and converted to SVG by en:User:Rbj - en:Zeroorderhold.signal.svg, Public Domain, https://commons.wikimedia.org/w/index.php?curid=870310

Direct Current and Safety

Safety with DC is more important to get right than with AC, this is because cables need physical changes to make DC monitoring possible, whereas with AC current and voltage transformers provide isolation.

Each of these safety points are important to understand when working with DC.

Working Voltage

Globally, the International Electrotechnical Commission (IEC) defines Extra-low voltage (ELV) for DC as <120VDC. In the EU the Low Voltage Directive defines it as <75VDC.

Extra-low voltage is low risk to the human body, it’s extremely unlikely to create an unstoppable electrocution, it can still be shocking and painful to come across a 75VDC potential.

The next level above, ‘Low voltage’, the IEC defines as 120VDC to 1500VDC. These voltages in the hundreds of VDC are very dangerous.

Most domestic solar operates in this range and all it’s hardware and associated working practices are meticulously designed to avoid danger.

DC Working Voltages are not normally measured by using a multimeter, but instead are inferred from the paperwork!

Available Current

Extra-low voltage can still mean high current.

High current could mean heat, sparks, arcs, welded contacts and even explosive events.

Batteries at low voltage can deliver huge current, and properly rated breakers are best used to make or break contact with such a battery bank.

What’s different about DC arcing in particular is it’s propensity to weld contacts together. A circuit breaker with an AC rating of 100Amps can have a DC rating much lower.

Tip: Manufacturers often supply the DC rating of AC breakers upon request.

Floating Ground

Sometimes referred to as floating supply or floating ground, these are another danger of any DC generation system and must be properly understood to protect people and equipment from injury and damage!

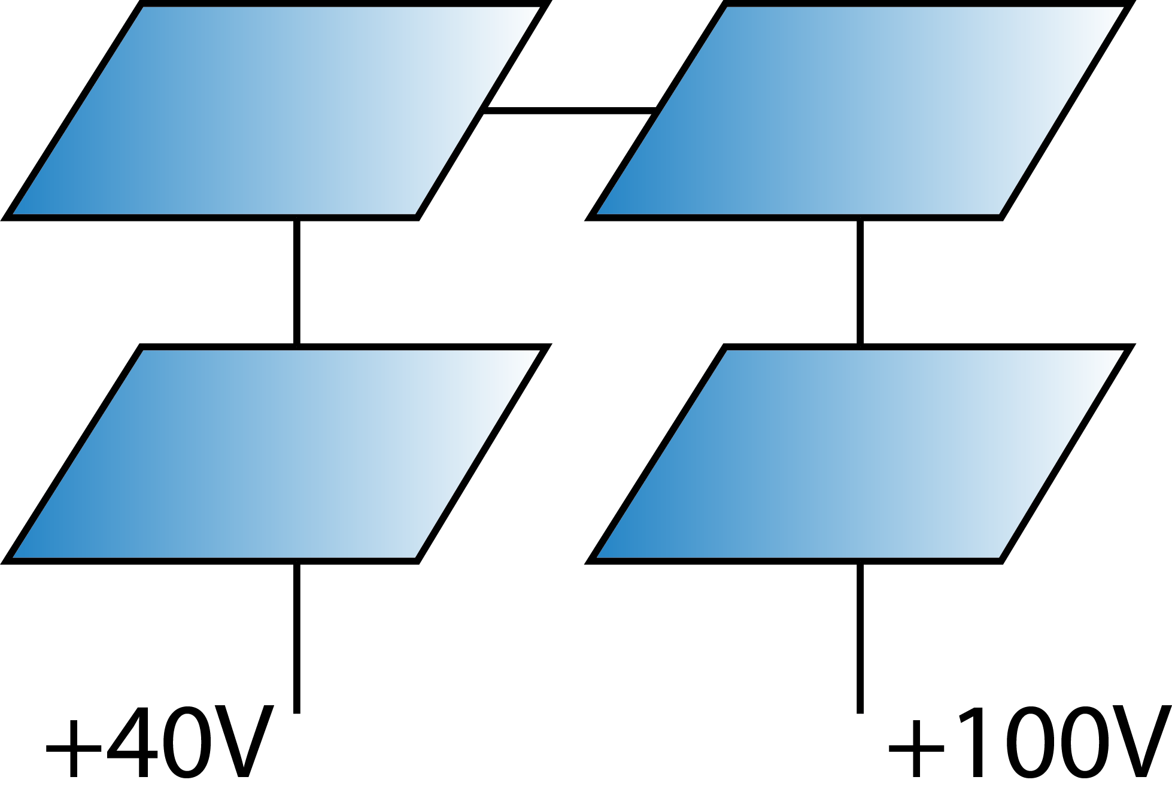
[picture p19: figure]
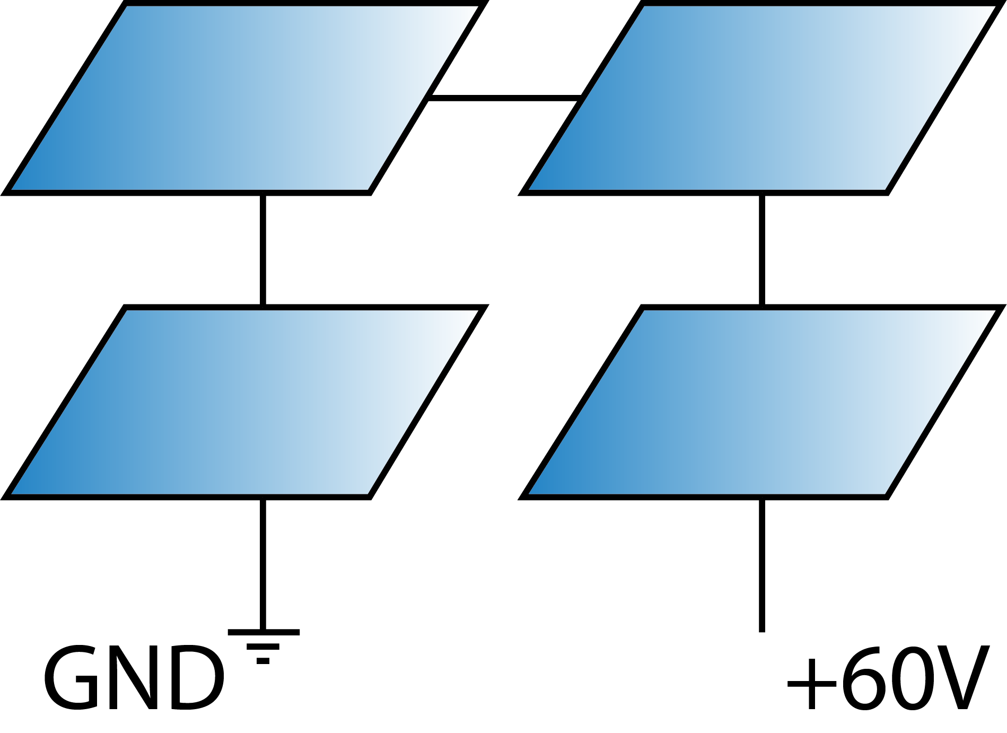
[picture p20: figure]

Figure 8.1 Figure 8.2

In figure 8.1 we have a system grounded to earth, the positive rail is up because the sun is shining.

In figure 8.2 the system is floating, perhaps by design, or perhaps an earthing fault, ground has floated to +40VDC above actual earth. Consequently, the high-side rail is now +100VDC, increasingly dangerous!

What's particularly dangerous about this situation is the charge buildup in the generator (PV panels) and metal chassis’ surrounding the PV and equipment, meaning the available current is potentially the generator charge + batteries (if any) + chassis charge buildup (possibly). So although +40VDC isn't a great deal, the available current is. If an earthed device was connected to a floating system like this, a burst of current would probably destroy the device(s) instantly and potentially start fires.

Definition: ISOLATION is the electrical (and often physical) separation of one part of a circuit from another.

Typically, solar PV systems operating in the hundreds or thousands of volts range are isolated from the rest of the system at the point of the inverter or charge controller. It is acceptable in extra-low voltage situations for them to be not isolated. For a DC generation system not isolated from the rest of the system, where the negative rail of the PV system is connected to the battery negative for example, a copper stake should ideally be driven into the ground and connected to a single point of the system, typically near the battery negative if there is one. It has also become common to semi-float solar PV and battery systems, where the earth rod is connected via a bi-directional transient voltage suppressor diode.

Galvanic Isolation and DC Voltage Sensing

Following on from floating ground:

Definition: GALVANIC ISOLATION is isolation of the Ground of one system from the Ground of another.

An easy-to-understand application of galvanic isolation is the transformer.

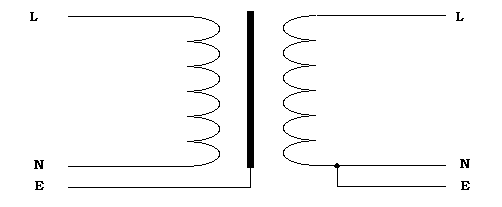
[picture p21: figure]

http://www.smartgauge.co.uk/galv_tran.html

The neutral and live wires of the left side are coupled electromagnetically to the right side, the Neutral lines of each side can be independently earthed. This is of course typical of AC systems.

If we’re connecting physically to the left side for a voltage reading, but want to send data to the right side, to maintain galvanic isolation the neutral lines or earths of each side must not connect.

In DC systems, it’s very similar. Using solar PV as an example, lets say we have a floating, non-earthed PV system. To get a reading of the voltage between the positive and negative current carriers, we need a physical connection to both positive and negative cables. We want to send this information to our earthed energy monitoring system, without connecting the Ground lines of each side: This introduces the problem of isolation between the two ground potentials, or galvanic isolation.

For even more clarity, let’s create an instance where the negative cables of our solar PV system could be at a higher voltage than the ground of the earthed data-logging system, if we imagine taking a cable from each side, and touching them together, we might get a nasty surprise, despite them both being called ‘ground’ or ‘negative’. This applies to safety of devices in particular, if we had an earthed laptop being connected via serial to a floating ground solar PV monitor, the result would probably be a broken laptop, as a burst of current would flow through the laptop between the PV ‘floating ground’ and true earth of the other side.

It is dangerous to the user to not have proper consideration of galvanic isolation in floating solar systems (or any floating generation system). Precautions such as double isolation or deliberate earthing of a metal enclosures containing whatever devices being installed needs consideration. Solar PV inverters often have an earthed metal casing.

In terms of system design, what this means is the creation of two systems with two separate grounds (possibly in one enclosure), on one side is the isolated floating monitor taking our voltage measurements, and on the other side is the earthed data logging or internet connected system including any raspberry Pis, laptops etc. being earth protected.

A simple example of isolated data transfer is in radio frequency. Information can be sent from one side to the other using 433MHz radio or WiFi for example. The air between the transmitter and receiver gives many GigaOhms of isolation.

Wire-wire isolated data transfer can also be optical analog isolation ICs, optical digital isolation ICs (opto-isolators or optocouplers), or transformer (coil-coil) type devices, to name a few.

The final problem to consider, is power supply. For example, a voltage monitor on the floating side needs power, the power needs to come from the floating system itself, via a regulating power-supply, batteries or separate isolated power-supply powered from the earthed side.

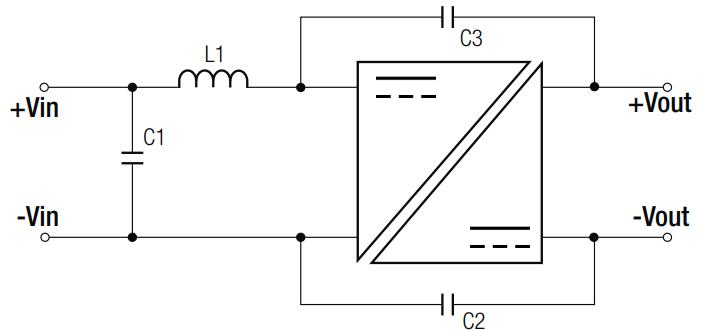
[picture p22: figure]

https://recom-power.com/en/products/dc-dc-converters/rec-c-dc-dc-converters.html

Appendices

The Common-Ground of Voltage Sensors

Ground is also called Common.

It’s a useful term, and here’s a situation where it’s relevant in regards to voltage sensing.

As we’ve seen above, voltage sensing in DC systems comes with a requirement that the sensor and system to be measured must share a common ground. This is going to be the case, as we need the physical connection, but it’s worth being aware of for another reason:

Consider that a typical multimeter’s volt-meter may have an input impedance of 10 Mega Ohm. A floating system may have a varying resistance to ground in the order of Giga Ohms, according to air / humidity conditions.

This means that an earthed voltage sensing device cannot accurately measure the voltage of a floating system because:

A. The resistance to earth of the floating system is varying; and
B. The relative resistance-to-ground would create a tiny voltage drop across the voltage sensor, unfeasibly small to amplify accurately.

The diagram below shows why measuring the voltage of either the positive or negative rail of a floating DC system would result in a reading of near zero. Effectively this means we cannot truly know the voltage of the floating side, without actually being connected directly to it.

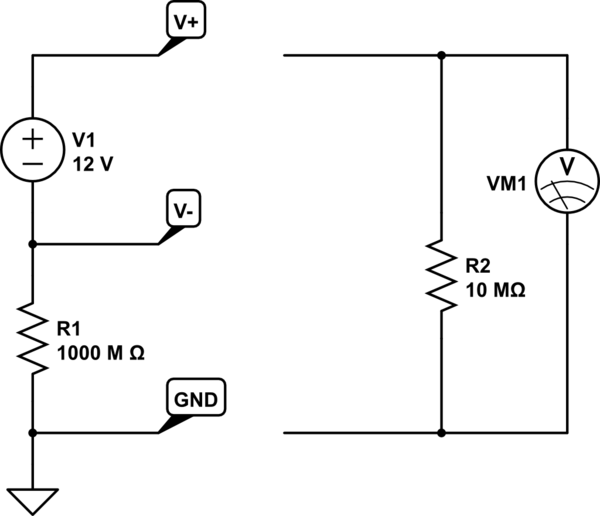
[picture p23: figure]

Figure 7 - Credit: Brian Drummond @ https://electronics.stackexchange.com/

Cathodic Protection. Galvanic Corrosion. Electrochemical Corrosion.

These are related terms, each a separate topic in itself. To summarise, an anode (positive charge) is more likely to corrode than a cathode (negative charge). Meaning, in the context of a -48VDC telecommunications systems and their +ive grounding, that the negatively charged cabling is protected from corrosion while a copper rod, active as the anode, corrodes instead. The process in particular requires a transport medium (e.g. moisture) and enough power to drive what’s called the impressed current.

It’s also possible to galvanically protect a copper DC system by attaching a zinc or magnesium bar to the positive rail, which would then be preferentially electrochemically corroded.

Earthing of DC systems can be either at the negative or positive pole. Telecommunication systems DC systems are at -48VDC (negative!) are always positive grounded. This is because of the corrosion potential of copper at these voltages. The corrosion potential is a function of the square of the voltage. Copper will corrode to a black oxide if charged positively for long enough, and will be difficult to clean up and reuse.

Cables, breakers:

Unlike AC measurement, DC voltage measurement often requires that cables are physically installed/cut/altered to accommodate the sensor. If we come back to our first diagram:

Rsense must exist in the main current path. The cable must be mounted either side of the shunt:

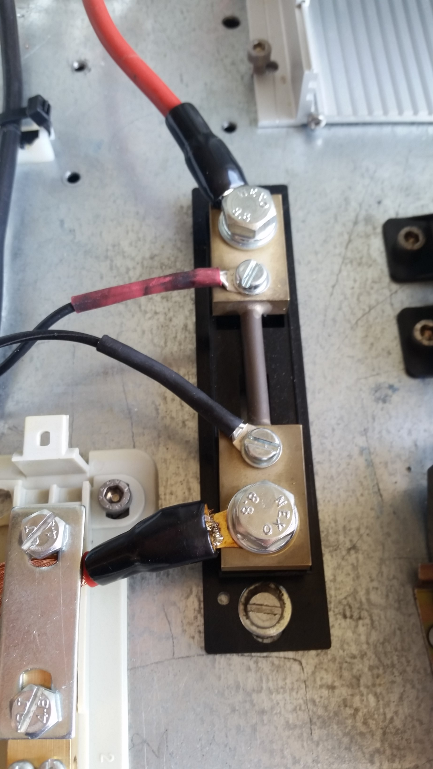
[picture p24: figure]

Photograph of a 100 Amp manganin shunt showing the larger diameter current carrier and the small sense leads bolted on. The shunt is bolted onto the metal backing and is isolated from the backing due to the black plastic mounting.

Circuits breakers for DC have to be rated for DC, not AC. Arcing in DC has a stronger binding effect, and breakers require stronger action to engage and disengage cleanly.

Manufacturers of AC circuit breakers will often give the DC rating equivalent for their product upon request.

Heat

The shunt resistance (Ohms) and heat dissipation rating (Watts) must be selected according to the expected current during normal operation (Amps). The shunts value can't be selected solely on it's Peak Current rating. P=I²R calculation are very useful! The peak power rating of the shunt is chosen carefully, keeping within 66% of it’s rating at normal operating current, as good practice.

A ready made calculator can be found at this spreadsheet. (https://docs.google.com/spreadsheets/d/1AWvydOCWHVhTkWPqWinTKVM8Qdhd0ycmwWtvUQ2X24o/edit?usp=sharing)

Optoisolation

Here’s an example extracted from a MorningStar solar charge controller manual, the RS-232 9-pin port requires power to operate the opto-isolators inside. It’s an example of optically-isolated digital information transfer.

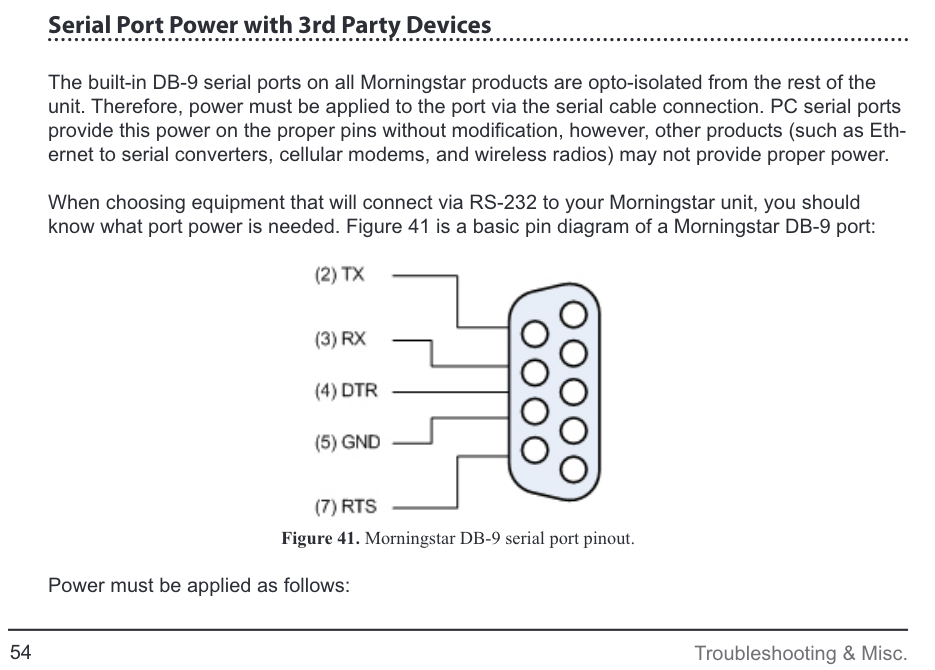
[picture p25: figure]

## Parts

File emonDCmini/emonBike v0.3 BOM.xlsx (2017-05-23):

Part | list exported from /Users/admin | /Dropbox/PROJECT FILES/emon/Emo | nDC/emonDCbike/emonBik | e v0.3.sch at 05/04/201 | 7 14:41
Qty | Value | Device | Package | Parts | Description
1 | 100K >70V | R-EU_R0603 | R0603 | R2
2 | 100nF | C-EUC0603 | C0603 | C21, C22
4 | 10k | R-EU_R0603 | R0603 | R6, R7, R18, R19
2 | 10uF 16V | C-EUC0603 | C0603 | C1, C5
1 | 10uF >70V | C-EUC0603 | C0603 | C2
2 | 1uF 16V | C-EUC0603 | C0603 | C3, C4
1 | 5.6k | R-EU_R0603 | R0603 | R17
1 | 5.9K | R-EU_R0603 | R0603 | R3
1 | EBW_SERIES_10.5MM | EBW_SERIES_10.5MM | EBW_SERIES_10.5MM | EBW_SERIES_10.5
1 | ESP8266_ESP-12 | ESP8266_ESP-12 | ESP8266-ESP12 | ESP-12
1 | FTDI-ESP | MA06-1 | MA06-1 | FTDI1
1 | LMP8481-H | LMP8481-H | S-PDSO-G08 | LMP8481
1 | LP3990MF-3.3/NOPBMF05AL | LP3990MF-3.3/NOPBMF05AL | MF05AL | LP3990 | 3.3V
1 | MAX5023TASA-T21-0111D_SBE-14-L | MAX5023TASA-T21-0111D_SBE-14-L | 21-0111D_SBE-14-L | MAX5053 | 5V
1 | MCP3202-BI/SN | MCP3202-BI/SN | SOIC127P600X175-8N | MCP3202
1 | MOLEX_MICRO_SD_1040310811 | MOLEX_MICRO_SD_1040310811 | MOLEX_MICROSD_EXPOSED | U$2

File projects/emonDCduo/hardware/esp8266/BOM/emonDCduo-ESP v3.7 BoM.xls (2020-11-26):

Handling |  |  |  | 4.2
 |  |  |  | per unit | inc. VAT | +markup | markup:
Enclosure, opaque | inc delivery from Lincoln Binns | 5 units | £35.00 | £7.00 | £7.00 | £10.50 | 1.5
Enclosure, clear top. | inc delivery from Lincoln Binns | 5 units | £42.40 | £8.48 | £8.48 | £12.72
Part | Value | Device | Package | Unit Price ex VAT
SMC |  |  |  | x50
PCB | PCB | PCB | PCB | 3.5
C1 | 0.1uF 100V | C-EUC0603 | C0805 | 0.05
C2 | 0.1uF 100V | C-EUC0603 | C0805 | 0.05
C3 | 0.1uF 100V | C-EUC0603 | C0805 | 0.05
C4 | 0.1uF 100V | C-EUC0603 | C0805 | 0.05
C5 | 0.1uF 100V | C-EUC0603 | C0805 | 0.05
C6 | 0.1uF 100V | C-EUC0603 | C0805 | 0.05
C7 | 0.1uF 100V | C-EUC0603 | C0805 | 0.05
C8 | 0.1uF 100V | C-EUC0603 | C0805 | 0.05
C17 | 0.1uF 100V | C-EUC0603 | C0805 | 0.05
C18 | 0.1uF 100V | C-EUC0603 | C0805 | 0.05
C19 | 0.1uF 100V | C-EUC0603 | C0805 | 0.05
C30T | 10uF 16V TANTALUM | CPOL-EUC0603POL | C0603POL | 0.2
C31T | 10uF 16V TANTALUM | CPOL-EUC0603POL | C0603POL | 0.2
C32T | 10uF 16V TANTALUM | CPOL-EUC0603POL | C0603POL | 0.2
C22 | 47uF 16V Can | MCVVT016M470DA1L (https://uk.farnell.com/multicomp/mcvvt016m470da1l/cap-47-f-16v-smd/dp/2611363%00) |  | 0.09
C23 | 47uF 16V Can | MCVVT016M470DA1L (https://uk.farnell.com/multicomp/mcvvt016m470da1l/cap-47-f-16v-smd/dp/2611363%00) |  | 0.09
C24 | 47uF 16V Can | MCVVT016M470DA1L (https://uk.farnell.com/multicomp/mcvvt016m470da1l/cap-47-f-16v-smd/dp/2611363%00) |  | 0.09
D1 | P6SMB75A | DIODE-DO214AA | DO214AA | 0.137
D2 | P6SMB75A | DIODE-DO214AA | DO214AA | 0.137
D3 | P6SMB75A | DIODE-DO214AA | DO214AA | 0.137
D4 | P6SMB75A | DIODE-DO214AA | DO214AA | 0.137
D5 | P6SMB75A | DIODE-DO214AA | DO214AA | 0.137
D7 | SMF5.0A | SMF5.0A | SOD123F | 0.23
LED1. PWR_ON | YELLOW 20mA | MCL-S250YC | CHIP_1206 | 0.1
LM258 | LM258 | LM258 | SOIC8_150MIL | 0.226
MCP3208 | MCP3208-BI/SL | MCP3208-BI/SL | SOIC16 | 2.26
MICRO_SD | 47219-2001_MICROSD | 47219-2001_MICROSD | MICROSD | 0.698
R5 | 174R | R-EU_R0603 | R0603 | 0.05
R6 | 10k | R-EU_R0603 | R0603 | 0.05
R7 | 3.3K | R-EU_R0603 | R0603 | 0.05
R8 | 174R | R-EU_R0603 | R0603 | 0.05
R9 | 1K | R-EU_R0603 | R0603 | 0.05
R10 | 2K | R-EU_R0603 | R0603 | 0.05
R11 | 10K | R-EU_R0603 | R0603 | 0.05
R14 | 1k | R-EU_R0603 | R0603 | 0.05
R15 | 2k | R-EU_R0603 | R0603 | 0.05
R16 | 10K | R-EU_R0603 | R0603 | 0.05
R17 | 10K | R-EU_R0603 | R0603 | 0.05
REG1 | REG1117-5.0V 800ma | REG1117 | SOT223 | 1.17
REG2 | REG1117-3.3V 800ma | REG1117 | SOT223 | 1.16
SHUNTMON-A | LMP8481 | LMP8481-H | VSSOP8 3x3mm P0.5mm | 1.62
SHUNTMON-B | LMP8481 | LMP8481-H | VSSOP8 3x3mm P0.5mm | 1.62
ESP-12F |  |  |  | 2.74 | For 6
ESP-12S |  |  |  | 1.88 | For 50 |  | markup:
 |  |  | full | £17.38 | £20.85 | £41.71 | 2
 |  |  | mini | £13.02 | £15.62 | £31.24 | 2
 |  |  |  |  | inc. VAT | +markup
Through Hole:
Part | Package | Description | Number of Contacts / MPN | Unit Cost @ x50
 |  | 2.54mm header cost / pin | £0.03
BOOT | 2.54mm HEADER | Male Header 2 Pin | 2 | 0.07
GPIO_1 | 2.54mm HEADER | Male Header 5x2 | 10 | 0.33
REF_SEL_A | 2.54mm HEADER | Male Header 3 Pin | 3 | 0.10
REF_SEL_B | 2.54mm HEADER | Male Header 3 Pin | 3 | 0.10
UART | 2.54mm HEADER | Male Header 6 Pin | 6 | 0.20
I2C Header | 2.54mm HEADER | Female Header 4 Pin |  | 0.0752
F1 | 445/030_SERIES_LITTELFUSE | 04450001N |  | 0.086
F1 | 445/030_SERIES_LITTELFUSE | 04450001N |  | 0.086
GND TERM | 5.08mm Wire-to-Board Term Block | KRM 02 |  | 0.191
5V Term | 5.08mm Wire-to-Board Term Block | KRM 02 |  | 0.191
R1 | 1Mohm Resistor | 1% 100Vmin |  | 0.1
R2 | 50kOhm Resistor | 1% 100Vmin |  | 0.05
R1 | 1Mohm Resistor | 1% 100Vmin |  | 0.1
R4 | 50kOhm Resistor | 1% 100Vmin |  | 0.05
RESET_BUTTON | FSM4JH | SWITCH 6x6 |  | 0.059
F2 | TR5 | FUSE |  | 0.577
F3 | TR5 | FUSE |  | 0.577
F4 | TR5 | FUSE |  | 0.577
F5 | TR5 | FUSE |  | 0.577 | inc. VAT | +markup | markup:
 |  |  |  | £4.10 | £4.91 | £12.29 | 2.5
Cable Terminations |  | Price Per Unit | Quantity | Sub-total | inc. VAT | +markup
10mm2 Cable Term. 81A | 10.16mm CTBP77VP/2 | 2.19 | 2 | £4.38 | £5.26 | £13.14 | 2.5
4mm2 Cable Term. 46A. | 7.62mm MC000052 | 0.748 | 2 | £1.50 | £1.80 | £4.49 | 2.5
6mm2 Cable Term. 59A | 5mm Bolted Rings |  | edit below | £0.40 | £0.40 | £1.00 | 2.5
 | - Ring Term (43108 Screwfix) | 0.0549 | 4 | £0.220
 | - Bolt | 0.0209 | 4 | £0.084
 | - Nut | 0.00659 | 4 | £0.026
 | - Washers | 0.0129 | 4 | £0.052
 | - Serrated Washers | 0.0049 | 4 | £0.020
Shunts | Value | Value | Quantity | Unit Cost ex VAT | inc. VAT | +markup | markup:
Welwyn ULR2-R001FT2 (https://uk.farnell.com/tt-electronics-welwyn/ulr2-r001ft2/current-sense-res-0r001-1-2-w/dp/1292489%00) | 1mOhm | 2W | 2 | £0.42 | £1.00 | £1.99 | 2
Welwyn ULR1-R002FT2 (https://uk.farnell.com/welwyn/ulr1-r002ft2/current-sense-res-0r002-1-1-w/dp/1292476%00) | 2mOhm | 1W | 2 | £0.40 | £0.96 | £1.91
Ohmite EBWB-NR0010FE (https://uk.farnell.com/ohmite/ebwb-nr0010fe/current-sense-res-1000-ohm-1-6/dp/2420528?st=ohmite%20ebw%00) | 1mOhm | 6W | 2 | £1.16 | £2.78 | £5.57
Ohmite EBWA-NR0020FE (https://uk.farnell.com/ohmite/ebwa-nr0020fe/current-sense-res-2000-ohm-1-4/dp/2420517?st=ohmite%20ebw%00) | 2mOhm | 4W | 2 | £1.79 | £4.30 | £8.59
Ohmite EBWB-MR0002FE (https://uk.farnell.com/ohmite/ebwb-mr0002fe/current-sense-res-200-ohm-1-7/dp/2420524?st=ohmite%20ebw%00) | 0.2mOhm | 7W | 2 | £2.44 | £5.86 | £11.71
Welwyn LRMAP5930B-R0005FT (https://uk.farnell.com/tt-electronics-welwyn/lrmap5930b-r0005ft/current-sense-res-0r0005-1-8-w/dp/2848246) | 0.5mOhm | 8W | 2 | £0.93 | £2.23 | £4.46
RTC Parts
Device | Value | Description | MPN
RTC |  | SOIC-8 | PCF8523 | 0.953
Crystal | 32.768kHz | 8x3.5mm | ABS25-32.768KHZ-T | 0.244
Coin-cell Holder |  | CR1220 | S8411-45R | 0.658
C33 | 4.7uF | C0805 |  | 0.1
R22 | 1k | R0603 |  | 0.1
C20 | 0.1uF 100V | C0805 |  | 0.1
C21 | 0.1uF 100V | C0805 |  | 0.1
Q1 Mosfet | P-channel | SOT23 | BSS84-7-F (https://uk.farnell.com/diodes-inc/bss84-7-f/mosfet-p-ch-50v-0-13a-sot23-3/dp/1843716%00) | 0.17 | inc. VAT | +markup | markup:
 |  |  |  | £2.43 | £2.91 | £7.28 | 2.5
ACS770 Breakout Parts
Device | Value | Description | MPN | single pieces
PCB Only | PCB Only | PCB Only | PCB Only | 1
ACS770 |  |  | ACS770LCB-050B-PFF-T | 4.54
R1 | 1MOhm 3.5kV 1% | HVR37 10x4mm | HVR3700001004FR500 | 0.25
Screw Terminal | 3.5mm x 3 | 3.5mm Pitch | CTBP3051/3 | 0.439
Header | 2.54mm HEADER | 3 contacts |  | 0.1
Header | 2.54mm HEADER | 3 contacts |  | 0.1
Header | 2.54mm HEADER | 3 contacts |  | 0.1
C1 | 0.1uF |  |  | 0.214
C2 | 0.1uF |  |  | 0.214 | inc. VAT | +markup | markup:
 |  |  |  | £6.96 | £8.35 | £20.87 | 2.5
Buck Reg Parts
Device | Value | Description | MPN | x50
PCB Only | PCB Only | PCB Only | PCB Only | 1
C1 | 100uF 80V |  | EEV-FK1K101Q-CASE-H13 | 0.497
C2 | 470uF 16V |  | EEE-FK1C471P-CASE-F | 0.252
C3 | 0.1uF 100V |  |  | 0.1
C4 | 0.1uF 100V |  |  | 0.1
C5 | 0.1uF 100V |  |  | 0.1
C6 | 0.1uF 100V |  |  | 0.1
C7 | 0.1uF 100V |  |  | 0.1
D1 | MBRS1100T3G | Schottkey Diode | MBRS1100T3G | 0.137
L1 | 150uH | Inductor | SRR1208-151YL | 0.48
MAX5035 | MAX5035 | Switching Regulator IC SOIC-8 | MAX5035DASA/MAX5035EASA | 2.07
R1 | 700K | R0603 |  | 0.1
R2 | 200k | Potentiometer | T93YB204KT20 (https://uk.farnell.com/vishay/t93yb204kt20/trimmer-pot-200k-23turn-thd/dp/1141423%00) | 0.969
R3 | 200k | Potentiometer | T93YB204KT20 (https://uk.farnell.com/vishay/t93yb204kt20/trimmer-pot-200k-23turn-thd/dp/1141423%00) | 0.969
R4 | 10k | R0603 |  | 0.1 | inc. VAT | +markup | markup:
 |  |  |  | £7.07 | £8.49 | £12.73 | 1.5
 |  |  |  |  |  | £21.22 | 2.5
SHIPPING
Format | Class | Cost inc. VAT | Handling | Total
Large Letter | 1st | 1.01 | 3 | £4.01
Small Package | 1st | 3.45 | 3 | £6.45
Small Package to USA | Standard | 6 | 3 | £9.00
 |  |  |  |  |  | £82.29
 |  |  | Standard, Fully Assembled | £41.71
 |  |  | PCB Only Minimal | £31.24
 |  |  | 0.5 mOhm, 60 Amps, 100 Amps Max. | £4.46
 |  |  | 1.0 mOhm, 35 Amps, 50 Amps Max | £1.99
 |  |  | 2.0 mOhm, 20 Amps, 25 Amps Max. | £1.91
 |  |  | Ring Terms | £1.00
 |  |  | 10.16mm Mount | £13.14
 |  |  | Buck reg kit | £12.73
 |  |  | Buck reg assembled | £21.22
 |  |  | 5.08mm term blocks, each | £0.48
 |  |  | Enclosure opaque | £10.50
 |  |  | Enclosure clear | £12.72
 |  |  | RTC Parts | £8.00

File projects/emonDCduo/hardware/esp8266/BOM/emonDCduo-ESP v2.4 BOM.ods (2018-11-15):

Symbol | Value / MPN | Case | MPN | Unit Price
C1 | 0.1uF 100V | C0603
C10 | 100uF 80V | CAPAE1350X1400N | EEVFK1K101Q
C11T | 10uF TANT 10V | C0603
C16 | 0.1uF 100V | C0603
C18T | 10uF TANT 10V | C0603
C19 | 0.1uF 100V | C0603
C1T | 10uF TANT 10V | C0603
C2 | 0.1uF 100V | C0603
C21 | 0.1uF 100V | C0603
C22 | 0.1uF 100V | C0603
C23 | 0.1uF 100V | C0603
C24 | 0.1uF 100V | C0603
C25 | 0.1uF 100V | C0603
C3 | 470uF 16V | CAPAE830X1050N | EEE-FK1C471P
C4 | 0.1uF 100V | C0603
C48 | 0.1uF 100V | C0603
C5 | 0.1uF 100V | C0603
C6 | 0.1uF 100V | C0603
C7T | 10uF TANT 10V | C0603
C8 | 0.1uF 100V | C0603
CR1220 | CR1220SMD | CR1220SMD | Harwin S8411-45R
D1 | MBRS1100T3G | SMB | MBRS1100T3G
D2 | P6SMB75A | DO214AA | P6SMB75A | 0.137
D3 | P6SMB75A | DO214AA | P6SMB75A | 0.137
D4 | P6SMB75A | DO214AA | P6SMB75A | 0.137
D5 | P6SMB75A | DO214AA | P6SMB75A | 0.137
D6 | P6SMB75A | DO214AA | P6SMB75A | 0.137
ESP-12 | ESP8266_ESP-12 | ESP8266-ESP12 | ESP-12F | 3
FUSE1 | 04450001N | LITTELFUSE 5x20 | 04450001N | 0.058
FUSE1 | 04450001N | LITTELFUSE 5x20 | 04450001N | 0.058
L1 | SRR1208-151YL | SSR1208 | SRR1208-151YL
LED1 | MCL-S250YC | CHIP-LED-1206 | MCL-S250YC | 0.1
MCP3208 | MCP3208-BI/SL | SOIC16 | MCP3208-BI/SL
MICRO_SD | 47219-2001 | 47219-2001_MICROSD | 47219-2001
PCF8523 | PCF8523 | SOIC8 | PCF8523
R1 | 1M 100V | R0603 | MCHVR03FTEX1004 | 0.01
R10 | 32k | 0204/10
R11 | 10k | 0204/10
R12 | 10k | R0603 |  | 0.01
R13 | 10k | R0603 |  | 0.01
R14 | 1M 100V | R0603 |  | 0.01
R15 | 56K | R0603 |  | 0.01
R16 | 2R 0.125W 0.1% | R0805 | RT0805BRD072RL | 0.03
R17 | 1k | R0603 |  | 0.01
R18 | 2k | R0603 |  | 0.01
R19 | 10k | R0603 |  | 0.01
R2 | 56k | R0603 |  | 0.01
R20 | 68k | R0603 |  | 0.01
R21 | 13k | R0603 |  | 0.01
R22 | 2R 0.125W 0.1% | R0805 | RT0805BRD072RL | 0.03
R23 | 2R 0.125W 0.1% | R0805 | RT0805BRD072RL | 0.03
R24 | 2R 0.125W 0.1% | R0805 | RT0805BRD072RL | 0.03
R26 | 174R | R0603 |  | 0.01
R27 | 10k | R0603 |  | 0.01
R28 | 10k | R0603 |  | 0.01
R3 | 10k | R0603 |  | 0.01
R4 | 1k | R0603 |  | 0.01
R5 | 1M | R0603 |  | 0.05
R6 | 10k | R0603 |  | 0.01
R7 | 10k | R0603 |  | 0.01
R8 | 2k | R0603 |  | 0.01
R9 | 1k | R0603 |  | 0.01
REG0 | MAX5035 | 21-0111D_SBE-14 | MAX5035EASA+
REG1 | REG1117-5.0V | SOT223 | REG1117-5.0 | 2
REG2 | REG1117-3.3V | SOT223 | REG1117-3.3 | 2
SHUNTMON-A | LMP8481 | VSSOP (8) | LMP8481MME-H/NOPB | 2.34
SHUNTMON-B | LMP8481 | VSSOP (8) | LMP8481MME-H/NOPB | 2.34
U1 | LM258DGKR | SOIC8 | LM258DGKR | 0.25
X3 | GMKDS 3/ 2-7.62 | Phoenix Contact | GMKDS 3/ 2-7.62 | 1.1
X4 | GMKDS 3/ 2-7.62 | Phoenix Contact | GMKDS 3/ 2-7.62 | 1.1
Y1 | 32Khz | CRYSTAL_8X3.8 | ABS25-32.768KHZ-T

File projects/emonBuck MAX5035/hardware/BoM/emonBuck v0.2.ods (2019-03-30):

Part | Value | Device | Package | Description | MF | MPN | OC_FARNELL | OC_NEWARK | PACKAGE | SPICEPREFIX | SUPPLIER | TOLERANCE | VALUE | VOLTAGERATING
C1 | 100uF 80V | EEV-FK1K101Q-CASE-H13 | CAPAE1350X1400N | Aluminum Electrolytic Capacitors,Surface Mount Type |  | EEVFK1K101Q | 9696113 | 96K9484 |  |  | PANASONIC | ±20 % | 100UF | 80V
C2 | 470uF 16V | EEE-FK1C471P-CASE-F | CAPAE830X1050N | Aluminum Electrolytic Capacitors,Surface Mount Type |  | EEE-FK1C471P | 9695710 | 96K9385 | CASE-F |  | PANASONIC | ±20 % | 470UF | 16V
C3 | 0.1uF 100V | C-EUC0603 | C0603 | CAPACITOR, European symbol |  |  |  |  |  | C
C4 | 0.1uF 100V | C-EUC0603 | C0603 | CAPACITOR, European symbol |  |  |  |  |  | C
C5 | 0.1uF 100V | C-EUC0603 | C0603 | CAPACITOR, European symbol |  |  |  |  |  | C
C6 | 0.1uF 100V | C-EUC0603 | C0603 | CAPACITOR, European symbol |  |  |  |  |  | C
C7 | 0.1uF 100V | C-EUC0603 | C0603 | CAPACITOR, European symbol |  |  |  |  |  | C
D1 | MBRS1100T3G | MBRS1100T3G | SMB_1 | MBRS1100T3G |  | MBRS1100T3G
L1 | SRR1208 | SRR1208 | SSR1208 | POWER INDUCTOR |  | SRR1208-151YL
MAX5035 | MAX5035 | MAX5035 | 21-0111D_SBE-14 | SWITCHING REGULATOR 5.0V 1.0A |  | MAX5035EASA+
R1 | 700K | R-EU_R0603 | R0603 | RESISTOR, European symbol
R4 | 10k | R-EU_R0603 | R0603 | RESISTOR, European symbol
Through components kept below for reference
R2 | 200k | TRIM_EU-B64W | B64W | POTENTIOMETER
R3 | 200k | TRIM_EU-B64W | B64W | POTENTIOMETER

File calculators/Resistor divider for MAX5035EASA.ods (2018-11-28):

REGULATING SET POINT = |  | 1.22 | VOLTS | value from minimum possible for MAX5035EASA, derived from MAX5035 datasheet.
 | VOUT = | 6.5 | VOLTS
 |  | R3 = | 43.28 | kOhm | or next greater
 |  | R4 = | 10 | kOhm
 |  | R3 = | 100
 |  | R4 = | 20000
 |  | Vout = | 1.23

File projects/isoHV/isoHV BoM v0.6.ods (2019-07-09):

Part | Value | Device | Package | Description
not necessary, 3.3V from Feather. | 7805TV | 7805TV | TO220V | Positive VOLTAGE REGULATOR
ACS7** | ±25A | ACS770 | CB-PFF | Hall Effect-Based Linear Current Sensor
C1 | 100pF | CPOL-EUB45181A | B45181A | CAPACITOR, European symbol
C2 | 100nF | CPOL-EUB45181A | B45181A | CAPACITOR, European symbol
C3 | 100nF | CPOL-EUB45181A | B45181A | CAPACITOR, European symbol
C4 | 100nF | CPOL-EUB45181A | B45181A | CAPACITOR, European symbol
C5 | 100nF | CPOL-EUB45181A | B45181A | CAPACITOR, European symbol
C6 | 470uF | CAP_EL_3.5MMGRID_10MMDIA | CELEC_3.5MM_10MM | Electrolytic Capacitors
C7 | 100nF | CPOL-EUB45181A | B45181A | CAPACITOR, European symbol
C8 | 10uF | C-EU025-050X050 | C025-050X050 | Electrolytic Capacitors
C9 | 10uF | C-EU025-050X050 | C025-050X050 | Electrolytic Capacitors
IC1 | OPAMP | TL972IP | DIL08 | Dual Precision, Low Cost, High Speed Op Amp
L1 | 11R472C | 11R472C | 0204V | INDUCTOR, European symbol
L2 | 11R472C | 11R472C | 0204V | INDUCTOR, European symbol
LED | Yellow, 20mA | 5mm LED | 0204V | RESISTOR, European symbol
R1 | 1Mohm | R-EU_0411/15 | 0411/15 | RESISTOR, European symbol
R2 | 1Mohm | R-EU_0411/15 | 0411/15 | RESISTOR, European symbol
R3 | 4.7kOhm | R-EU_0411/15 | 0411/15 | RESISTOR, European symbol
R4 | 10k | R-EU_0204/7 | 0204/7 | RESISTOR, European symbol
R5 | 10k | R-EU_0204/7 | 0204/7 | RESISTOR, European symbol
R6 | 10k | R-EU_0204/7 | 0204/7 | RESISTOR, European symbol
R7 | 10k | R-EU_0204/7 | 0204/7 | RESISTOR, European symbol
R8 | 100R | R-EU_0204/2V | 0204V | RESISTOR, European symbol
U$7 | NXF1 | NXF1S0505MC-R7 | NXF1
U1 | ACPL-C87x | ACPL-C870-000E | SOIC127P1150X330-8N | Precision Miniature Isolation Amplifiers

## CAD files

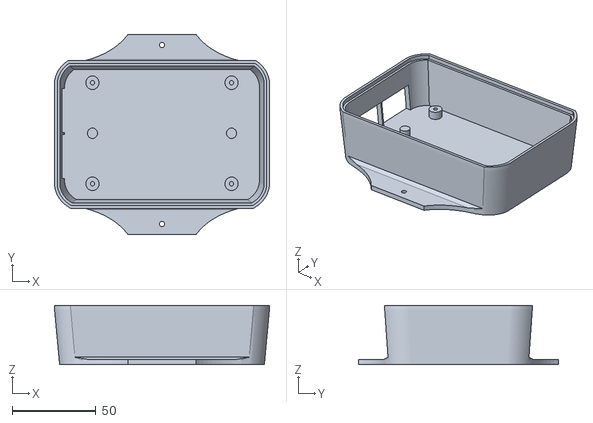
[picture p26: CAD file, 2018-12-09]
projects/emonDCduo/hardware/esp8266/3dprint case/emondcduo_case1f.stl
128.3 x 119.3 x 35.5

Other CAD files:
projects/emonDCduo/hardware/esp8266/3dprint case/emondcduo_case1f.skp
projects/isoHV/hardware/2 module sketch.skp
projects/isoHV/isoHV datasheets/raspberry_pi_3.skp

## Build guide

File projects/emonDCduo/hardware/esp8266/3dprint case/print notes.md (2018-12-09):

#### print notes

Print v1d on a Makerbot Replicator2 with white PLA. temperature at 230degC and speed set quite fast. 10%infill, two layer shell.
Version 1d was too small, either from calibration of printer problem or shrinkage of the PLA.
Version 1f should be the correct size, but may need scaling up or down a percent or two either way depending on your setup. I also gave more vertical space for the cable connections.

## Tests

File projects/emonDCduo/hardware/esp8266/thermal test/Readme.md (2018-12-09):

Ambient Temperature, 8.5degC. 8th Dec, 2018.

Camera model: Flir T200

The emissivity setting for the images was at 0.85 for the FR4 PCB material. Therefore, the temperature colour-scale to the right of the image relates to the temperature of the FR4, approximately.

- Approximately 120amps RMS AC from welding machine.

- The limit of the thermal camera was 150degC, this was reached.

- The shunt was desoldered from the board after about 1 minute, therefore it reach a the melting point of 100% Tin/Ni+ solder.

- Very little heat energy was conducted outside of the copper rectangle of the mounting and shunt area. However, I have modified the trace downstream to be thinner, minimizing heating of the fuses and shunt monitor.

- Most of the heat was conducted through the cable connection. The highest temperature was at the shunt and the immediately surrounding copper and solder mask.

- Imaging the rear of the board, less than expected heat came through the vias, and more than expected was transmitted directly from under the center of the shunt, straight through the PCB. Note: check via design.

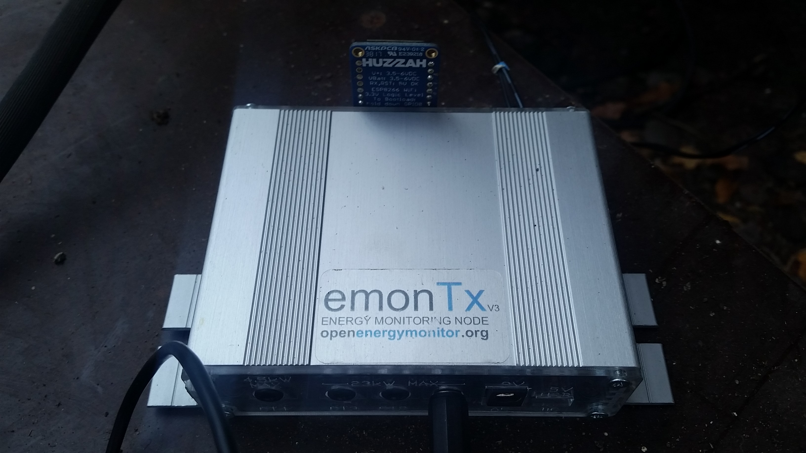
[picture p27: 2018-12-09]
projects/emonDCduo/hardware/esp8266/thermal test/pics/2018-11-26 09.45.16.jpg

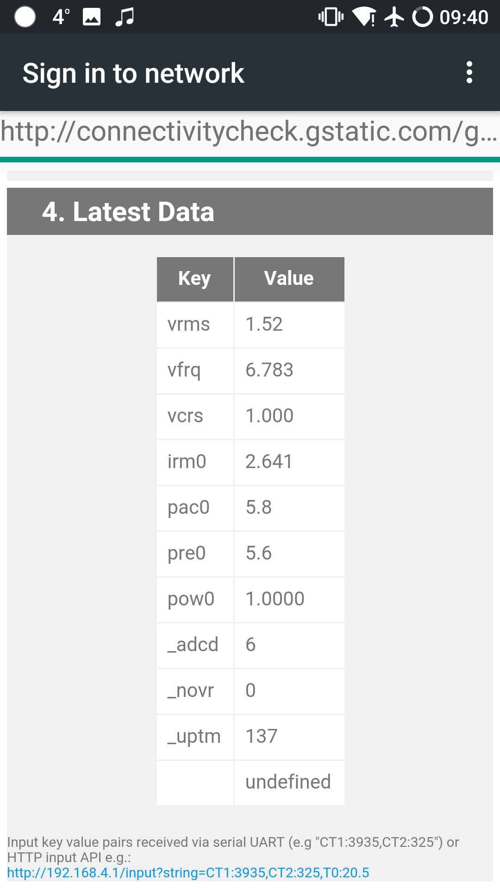
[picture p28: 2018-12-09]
projects/emonDCduo/hardware/esp8266/thermal test/pics/2018-11-26 09.40.18.png

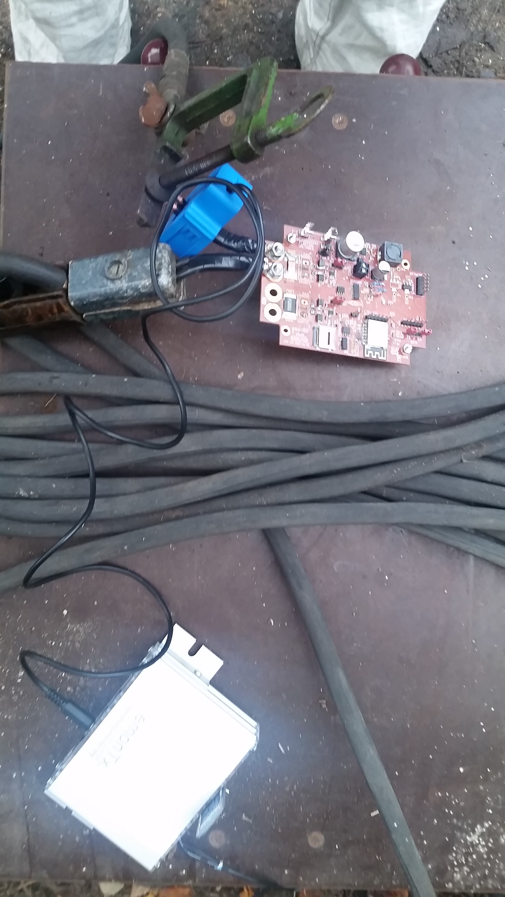
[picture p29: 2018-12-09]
projects/emonDCduo/hardware/esp8266/thermal test/pics/2018-11-26 09.45.09.jpg

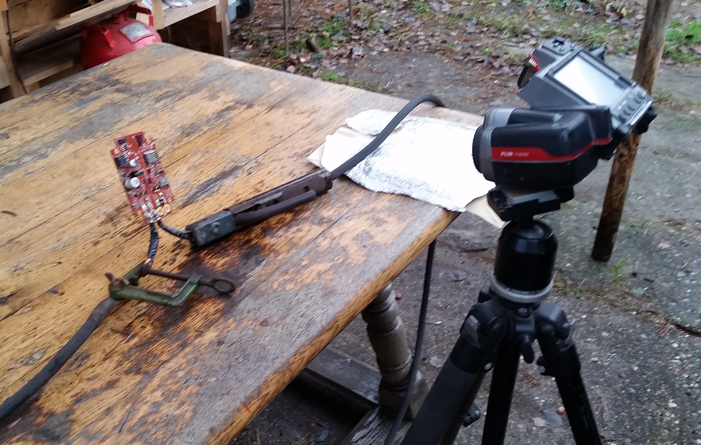
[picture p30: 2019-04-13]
projects/emonDCduo/hardware/esp8266/thermal test/pics/2018-12-08 10.13.28.jpg

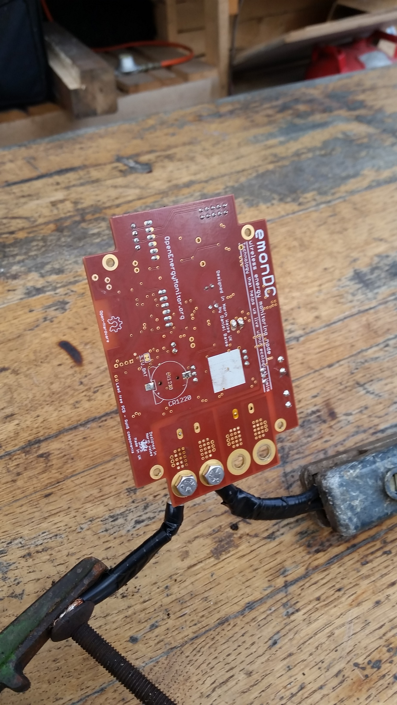
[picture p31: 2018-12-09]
projects/emonDCduo/hardware/esp8266/thermal test/pics/2018-12-08 10.54.57.jpg

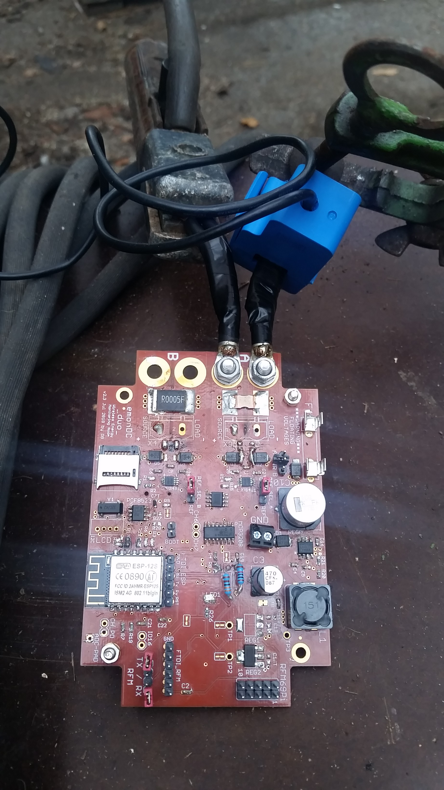
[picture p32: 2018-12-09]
projects/emonDCduo/hardware/esp8266/thermal test/pics/2018-11-26 09.45.02.jpg

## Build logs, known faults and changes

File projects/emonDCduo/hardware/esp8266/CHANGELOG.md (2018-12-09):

##emonDCduo changelog
This changelog has been written retrospectively and will miss out detail.

v0.1 old versions were basically changes to the emonTX with a two shunt-monitors introduced. A dedicated power supply for DC-DC buck conversion was designed in with help from Ken Boak for the electrical theory side of things.

v0.4 contained in the _previous version archive attempts to integrate an atmel chip, rfm, and esp8266 module, and microSD card.

v1.1 does away with the atmel chip for cost reasons, and incorporates the 8-channel 12 bit ADC MCP3208. Also the integrated RFM69 is replaced with a 10 pin header for connecting an RMFpi.

v1.2 by this version there’s a worked out RTC chip based on Bob Lemaire IoTaWatt design. Also changed is the power supply, involving three regs.

v1.3 minor changes for production. The resistor divider is changed for the reference voltage for the bi-directional monitoring. The resistors are solderable through-hole type now, to enable the end-user to easily change the reference voltage. This philosophy could apply to the voltage dividers for the channel A and B voltage monitoring.

v1.4 ‘designed by Megni’ changed to ‘designed by Daniel Bates’. The shunts and PCB traces have more isolation and 4.5mm drill hole via have been introduced for soldering directly 4mm cable to the board, for higher current applications.

v2.0 Fuse and transient protection added. Board reorganised. Connectors reorganised.

v3.0 All inputs fused. DC-DC Buck removed, in favour of module, dubbed emonBuck. Mounting options diversified. RTC moved under-side.

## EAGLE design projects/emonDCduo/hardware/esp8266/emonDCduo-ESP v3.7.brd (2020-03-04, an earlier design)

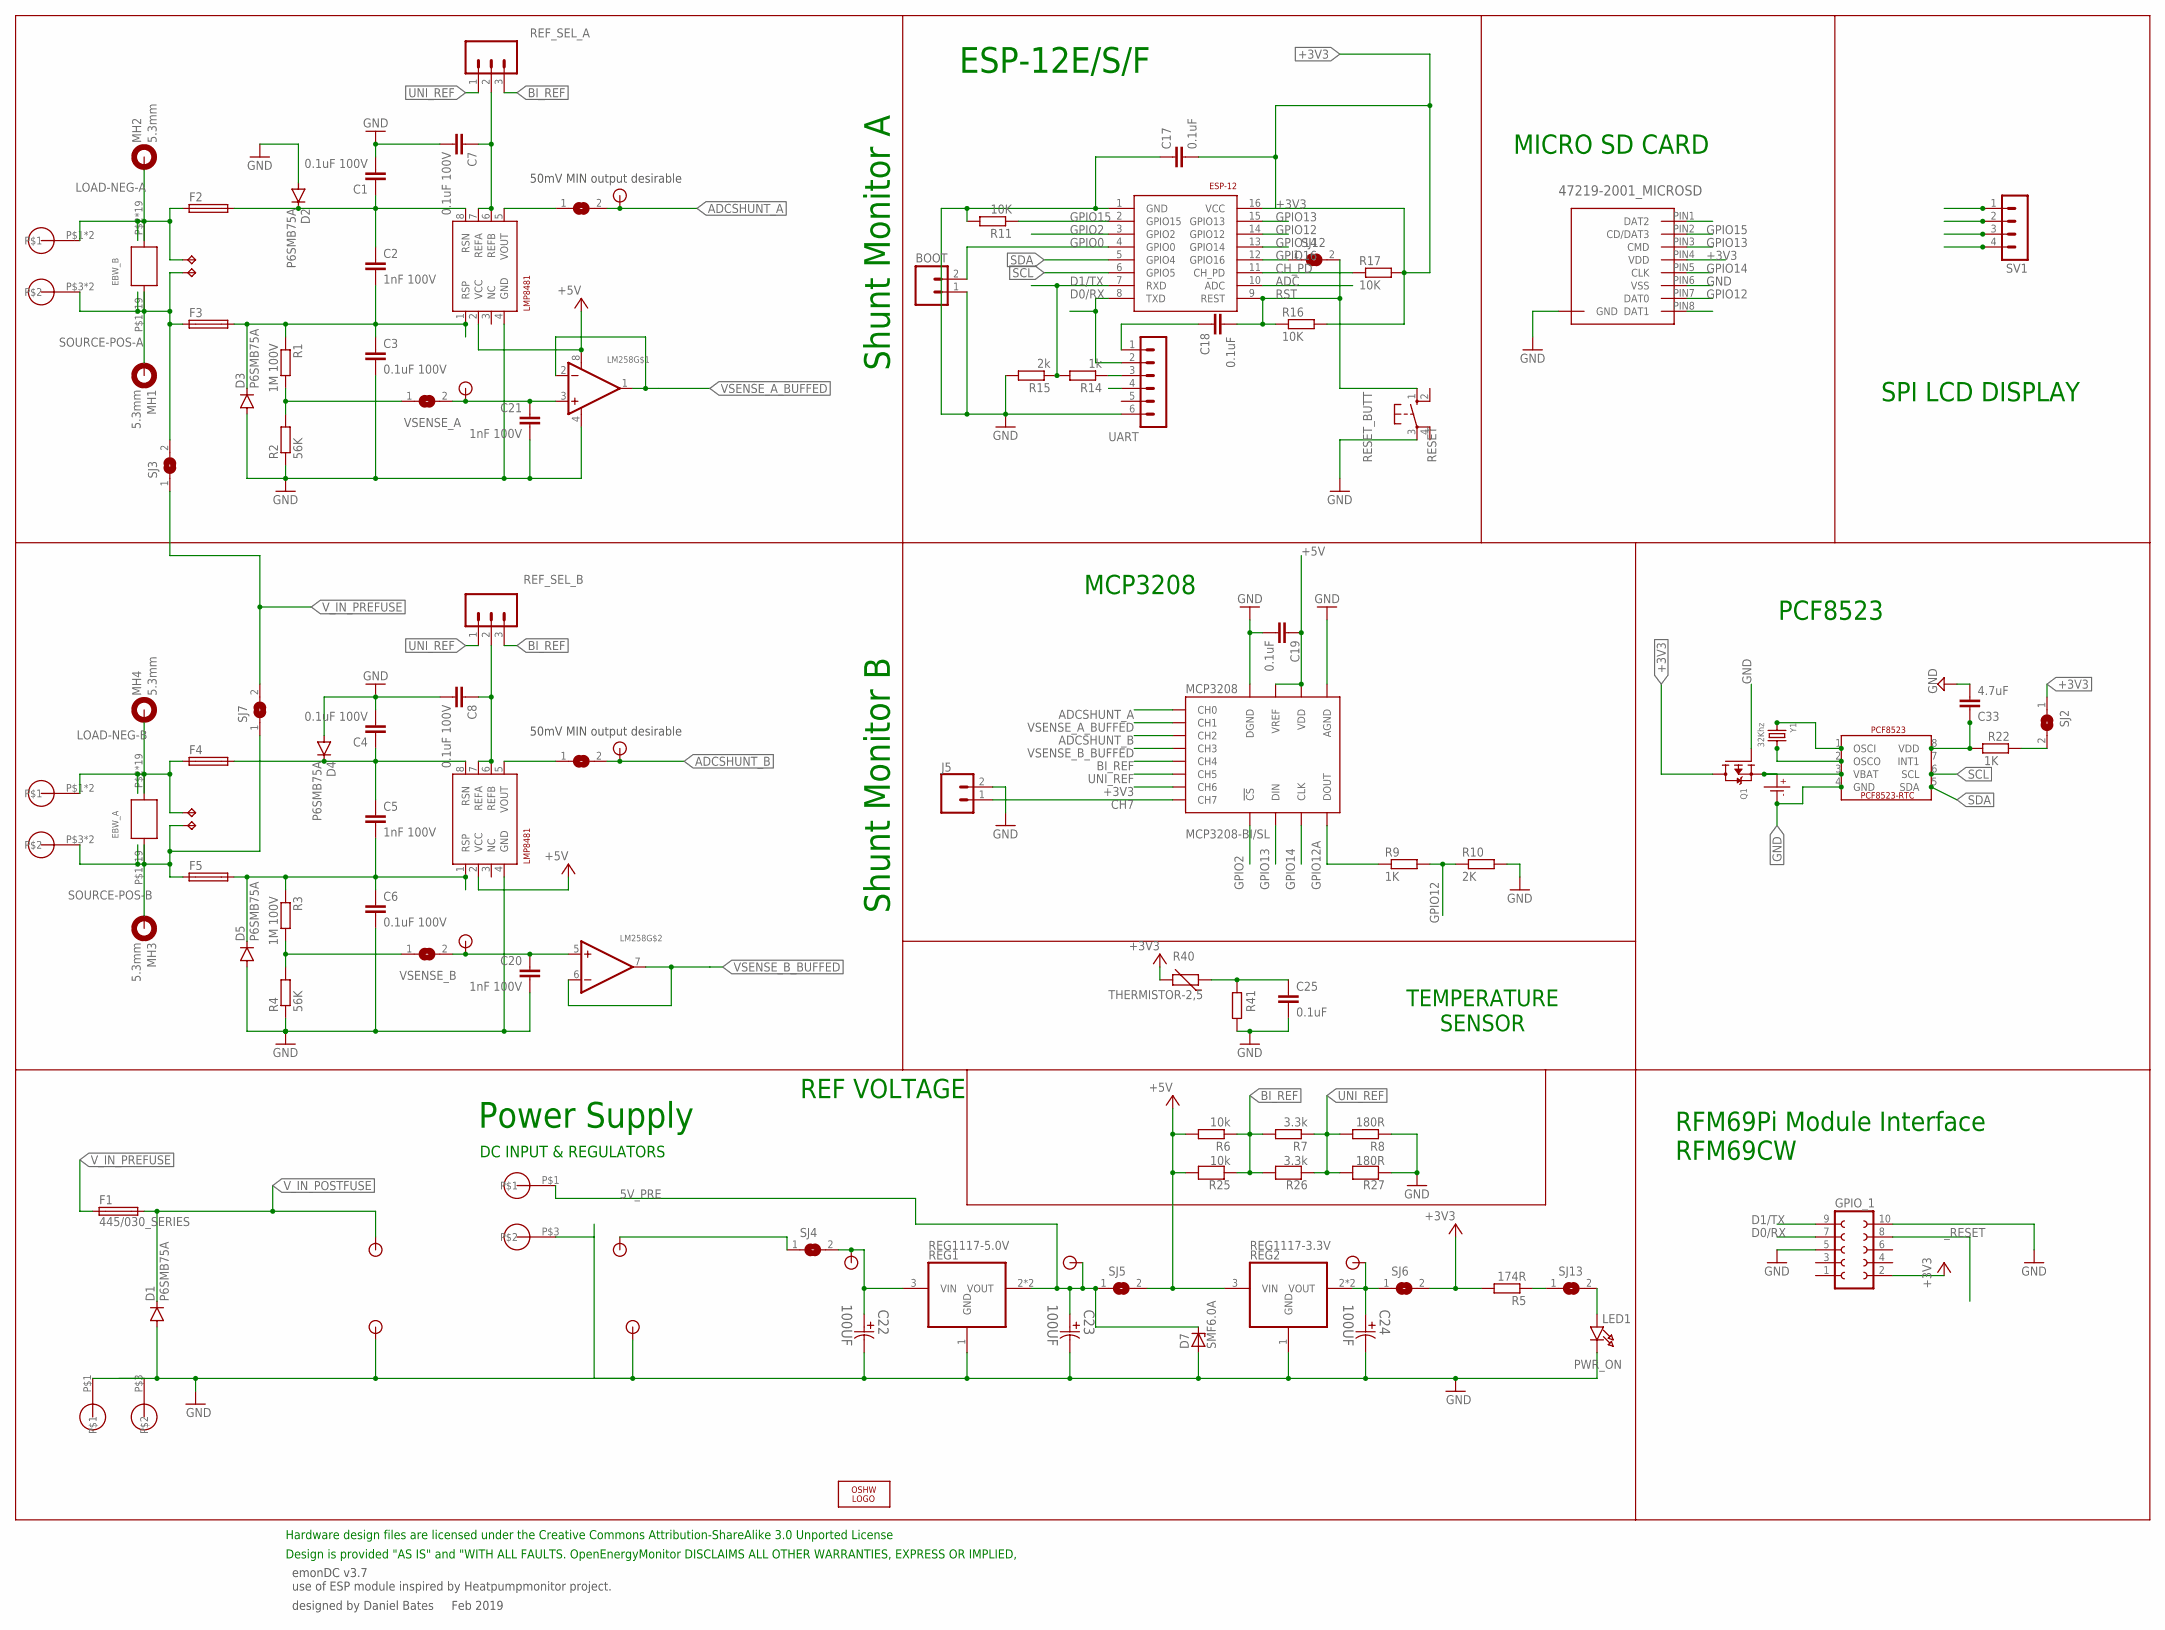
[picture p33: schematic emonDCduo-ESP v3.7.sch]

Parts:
BOOT: M02PTH; 1X02
C1, C3, C4, C6, C7, C8: 0.1uF 100V; C0805; MPN C1608X7S2A104K080AB
C2, C5, C20, C21: 1nF 100V; C0805; MPN C1608X7S2A104K080AB
C17, C18, C19, C25: 0.1uF; C0805
C22, C23, C24: 100UF; CAPAE530X610N
C33: 4.7uF; C0805
CR1220: CR1220SMD; MPN Harwin S8411-45R
D1: P6SMB75A; DO214AA
D2, D3, D4, D5: P6SMB75A; SMB
D7: SMF6.0A; SOD123F
EBW_A: EBW_SERIES_15.2MM
EBW_B: EBW_SERIES_15.2MM
ESP-12: ESP8266_ESP-12; ESP8266-ESP12
F1: 445/030_SERIES; 445/030_SERIES_LITTELFUSE
F2, F3, F4, F5: TR5
GPIO_1: FE05-2_RFM69PI_OUTLINERFM69PI; FE05-2_RFM69PI_OULTINE
J5: CONN_02; 1X02
LED1: PWR_ON; CHIPLED_1206
LM258: LM358; SOIC8_150MIL
LOGO1: OSHW_LOGO_6MILX0200-NT; OSHW_6X200_NOTEXT
MCP3208: MCP3208-BI/SL; SOIC16
MH1, MH2, MH3, MH4: 5.3mm; 5,3//11-PAD
MICRO_SD: 47219-2001_MICROSD
MOUNT_10.16_A, MOUNT_10.16_B: MOLEX_39970-003; 2/10,16
PCF8523: PCF8523_RTC; SOIC_8
Q1: MOSFET-P; SOT23-R
R1, R3: 1M 100V; 0207/2V; MPN MCMF006FF1004A50
R2, R4: 56K; 0207/2V; MPN MCMF006FF7502A50
R5: 174R; R0603
R6: 10k; 0207/10
R7: 3.3k; 0207/10
R8: 180R; 0207/10
R9: 1K; R0603; MPN MCWR06X5901FTL
R10: 2K; R0603; MPN MCWR06X5901FTL
R11, R16, R17: 10K; R0603
R14: 1k; R0603
R15: 2k; R0603
R22: 1K; R0603
R25: 10k; 0603
R26: 3.3k; 0603
R27: 180R; 0603
R40: THERMISTOR-2,5; RS-2,5
R41: R-EU_0207/2V; 0207/2V
REF_SEL_A: 455-1750-1-ND; 1X03; MPN 2212S-02SG-85
REF_SEL_B: 455-1750-1-ND; 1X03; MPN 2212S-02SG-85
REG1: REG1117-5.0V; SOT223; MPN REG1117-5.0
REG2: REG1117-3.3V; SOT223; MPN REG1117-3.3
RESET: RESET_BUTT; B3F-10XX; MPN FSM4JH
SHUNTMON-A: LMP8481; S-PDSO-G08; MPN LMP8481MME-S/NOPB
SHUNTMON-B: LMP8481; S-PDSO-G08; MPN LMP8481MME-H/NOPB
SJ2, SJ4, SJ5, SJ6, SJ8, SJ9, SJ10, SJ11, SJ12, SJ13: SOLDERJUMPERCLOSED; SOLDERJUMPER_CLOSEDWIRE
SJ3, SJ7: SJ
SV1: MA04-1; MPN 2212S-04SG-85
TP8, TP9, TP10, TP11: TPPAD1-13Y; P1-13Y
U$1, U$4, U$5, U$6, U$7, U$8, U$9: TP0.8MM; TP0.8
U$2, U$3, U$10, U$11: 2212S-02SG-85; TP0.8_X2
U$12, U$13: 5MMBLOCK; 2/5.08
UART: UART; MA06-1
Y1: 32Khz; CRYSTAL_8X3.8

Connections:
3.3V_PRE: C24.1, REG2.2 (VOUT), REG2.4 (VOUT), SJ6.1, U$8.P$1
5V_PRE: C23.1, D7.C, REG1.2 (VOUT), REG1.4 (VOUT), SJ5.1, U$7.P$1, U$12.P$1
6.5V: C22.1, REG1.3 (VIN), SJ4.2, U$9.P$1
+3V3: C17.2, ESP-12.16 (VCC), GPIO_1.2, MCP3208.7 (CH6), MICRO_SD.PIN4 (VDD), Q1.3 (D), R5.2, R16.2, R17.2, R40.2, SJ2.1, SJ6.2, SV1.3
+5V: C19.1, LM258.8 (V+), MCP3208.15 (VREF), MCP3208.16 (VDD), R6.2, R25.2, REG2.3 (VIN), SHUNTMON-A.2 (VCC), SHUNTMON-B.2 (VCC), SJ5.2, UART.4
ADC: C25.1, ESP-12.10 (ADC), R40.1, R41.2
ADCSHUNT_A: MCP3208.1 (CH0), SJ11.2, U$6.P$1
ADCSHUNT_B: MCP3208.3 (CH2), SJ10.2, U$5.P$1
BI_REF: MCP3208.5 (CH4), R6.1, R7.2, R25.1, R26.2, REF_SEL_A.3, REF_SEL_B.3
CH7: J5.1, MCP3208.8 (CH7)
CH_PD: ESP-12.11 (CH_PD), R17.1
D0/RX: ESP-12.8 (TXD), GPIO_1.7, UART.2
D1/TX: ESP-12.7 (RXD), GPIO_1.9, R14.2, R15.1
GND: BOOT.1, C1.2, C3.2, C4.2, C6.2, C7.2, C8.2, C17.1, C19.2, C20.2, C21.2, C22.2, C23.2, C24.2, C25.2, C33.2, CR1220.P- (P$-), D1.A, D2.A, D3.A, D4.A, D5.A, D7.A, ESP-12.1 (GND), GPIO_1.5, GPIO_1.10, J5.2, LED1.C, LM258.4 (V-), MCP3208.9 (DGND), MCP3208.14 (AGND), MICRO_SD.P$1 (GND), MICRO_SD.P$2 (GND), MICRO_SD.P$3 (GND), MICRO_SD.P$4 (GND), MICRO_SD.PIN6 (VSS), PCF8523.4 (GND), Q1.1 (G), R2.1, R4.1, R8.1, R10.2, R11.2, R15.2, R27.1, R41.1, REG1.1 (GND), REG2.1 (GND), RESET.3, SHUNTMON-A.4 (GND), SHUNTMON-B.4 (GND), SV1.4, U$3.P$1, U$3.P$2, U$11.P$1, U$11.P$2, U$12.P$3, U$13.P$1, U$13.P$3, UART.6
GPIO0: BOOT.2, ESP-12.4 (GPIO0)
GPIO2: ESP-12.3 (GPIO2), MCP3208.10 (!CS)
GPIO12: ESP-12.14 (GPIO12), MICRO_SD.PIN7 (DAT0), R9.2, R10.1
GPIO12A: MCP3208.12 (DOUT), R9.1
GPIO13: ESP-12.15 (GPIO13), MCP3208.11 (DIN), MICRO_SD.PIN3 (CMD)
GPIO14: ESP-12.13 (GPIO14), MCP3208.13 (CLK), MICRO_SD.PIN5 (CLK)
GPIO15: ESP-12.2 (GPIO15), MICRO_SD.PIN2 (CD/DAT3), R11.1
GPIO16: ESP-12.12 (GPIO16), SJ12.1
LOAD-NEG-A: EBW_B.P$2, EBW_B.P$18, EBW_B.P$19, EBW_B.P$20, EBW_B.P$21, EBW_B.P$22, EBW_B.P$23, EBW_B.P$24, EBW_B.P$25, EBW_B.P$26, EBW_B.P$27, EBW_B.P$28, EBW_B.P$29, EBW_B.P$30, EBW_B.P$31, EBW_B.P$32, EBW_B.P$36, EBW_B.P$37, EBW_B.P$38, F2.1, MH2.B5,5, MOUNT_10.16_A.P$1, MOUNT_10.16_A.P$2, TP11.TP
LOAD-NEG-A_T: C1.1, C2.1, D2.C, F2.2, SHUNTMON-A.8 (RSN)
LOAD-NEG-B: EBW_A.P$2, EBW_A.P$18, EBW_A.P$19, EBW_A.P$20, EBW_A.P$21, EBW_A.P$22, EBW_A.P$23, EBW_A.P$24, EBW_A.P$25, EBW_A.P$26, EBW_A.P$27, EBW_A.P$28, EBW_A.P$29, EBW_A.P$30, EBW_A.P$31, EBW_A.P$32, EBW_A.P$36, EBW_A.P$37, EBW_A.P$38, F4.1, MH4.B5,5, MOUNT_10.16_B.P$1, MOUNT_10.16_B.P$2, TP9.TP
LOAD-NEG-B_T: C4.1, C5.1, D4.C, F4.2, SHUNTMON-B.8 (RSN)
unnamed: C18.1, UART.1
unnamed: R5.1, SJ13.1
unnamed: LED1.A, SJ13.2
unnamed: SHUNTMON-B.5 (VOUT), SJ10.1
unnamed: SHUNTMON-A.5 (VOUT), SJ11.1
unnamed: R14.1, UART.3
unnamed: PCF8523.2 (OSCO), Y1.P$4 (2)
unnamed: PCF8523.1 (OSCI), Y1.P$1 (1)
REF_A_INPUT: C7.1, REF_SEL_A.2, SHUNTMON-A.6 (REFB), SHUNTMON-A.7 (REFA)
REF_B_INPUT: C8.1, REF_SEL_B.2, SHUNTMON-B.6 (REFB), SHUNTMON-B.7 (REFA)
RST: C18.2, ESP-12.9 (REST), R16.1, RESET.1 (S), SJ12.2
SCL: ESP-12.6 (GPIO5), PCF8523.6 (SCL), SV1.2
SDA: ESP-12.5 (GPIO4), PCF8523.5 (SDA), SV1.1
SOURCE-POS-A: EBW_B.P$1, EBW_B.P$3, EBW_B.P$4, EBW_B.P$5, EBW_B.P$6, EBW_B.P$7, EBW_B.P$8, EBW_B.P$9, EBW_B.P$10, EBW_B.P$11, EBW_B.P$12, EBW_B.P$13, EBW_B.P$14, EBW_B.P$15, EBW_B.P$16, EBW_B.P$17, EBW_B.P$33, EBW_B.P$34, EBW_B.P$35, F3.1, MH1.B5,5, MOUNT_10.16_A.P$3, MOUNT_10.16_A.P$4, SJ3.2, TP10.TP
SOURCE-POS-A_T: C2.2, C3.1, D3.C, F3.2, R1.1, SHUNTMON-A.1 (RSP)
SOURCE-POS-B: EBW_A.P$1, EBW_A.P$3, EBW_A.P$4, EBW_A.P$5, EBW_A.P$6, EBW_A.P$7, EBW_A.P$8, EBW_A.P$9, EBW_A.P$10, EBW_A.P$11, EBW_A.P$12, EBW_A.P$13, EBW_A.P$14, EBW_A.P$15, EBW_A.P$16, EBW_A.P$17, EBW_A.P$33, EBW_A.P$34, EBW_A.P$35, F5.1, MH3.B5,5, MOUNT_10.16_B.P$3, MOUNT_10.16_B.P$4, SJ7.1, TP8.TP
SOURCE-POS-B_T: C5.2, C6.1, D5.C, F5.2, R3.1, SHUNTMON-B.1 (RSP)
UNI_REF: MCP3208.6 (CH5), R7.1, R8.2, R26.1, R27.2, REF_SEL_A.1, REF_SEL_B.1
VBAT: CR1220.P+ (P$+), PCF8523.3 (VBAT), Q1.2 (S)
VDD_PCF: C33.1, PCF8523.8 (VDD), R22.1
VDD_RTC_POSTJUMPER: R22.2, SJ2.2
VOUT_POST_SWITCHING: SJ4.1, U$10.P$1, U$10.P$2
VSENSE_A: R1.2, R2.2, SJ8.1
VSENSE_A_BUFFED: LM258.1 (OUT), LM258.2 (-IN), MCP3208.2 (CH1)
VSENSE_A_TP: C21.1, LM258.3 (+IN), SJ8.2, U$1.P$1
VSENSE_B: R3.2, R4.2, SJ9.1
VSENSE_B_BUFFED: LM258.6 (-IN), LM258.7 (OUT), MCP3208.4 (CH3)
VSENSE_B_TP: C20.1, LM258.5 (+IN), SJ9.2, U$4.P$1
V_IN_POSTFUSE: D1.C, F1.P$3 (2), F1.P$4 (2), U$2.P$1, U$2.P$2
V_IN_PREFUSE: F1.P$1 (1), F1.P$2 (1), SJ3.1, SJ7.2
_RESET: GPIO_1.8

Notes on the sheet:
emonDC v3.7 use of ESP module inspired by Heatpumpmonitor project.
designed by Daniel Bates Feb 2019
Power Supply
Design is provided "AS IS" and "WITH ALL FAULTS. OpenEnergyMonitor DISCLAIMS ALL OTHER WARRANTIES, EXPRESS OR IMPLIED,
Hardware design files are licensed under the Creative Commons Attribution-ShareAlike 3.0 Unported License
DC INPUT & REGULATORS
Shunt Monitor B
Shunt Monitor A
ESP-12E/S/F
MICRO SD CARD
RFM69Pi Module Interface RFM69CW
MCP3208
PCF8523
SPI LCD DISPLAY
TEMPERATURE SENSOR
50mV MIN output desirable
REF VOLTAGE

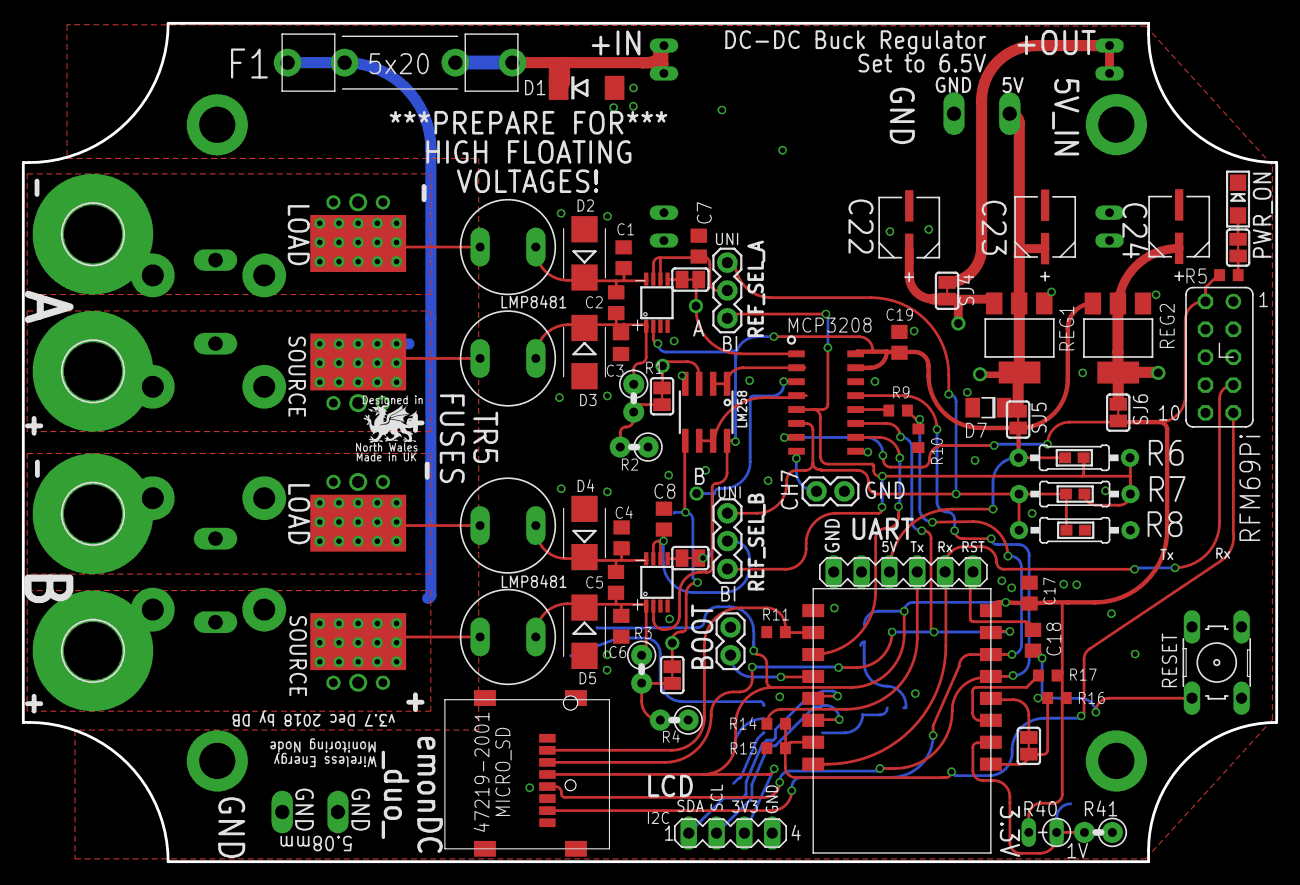
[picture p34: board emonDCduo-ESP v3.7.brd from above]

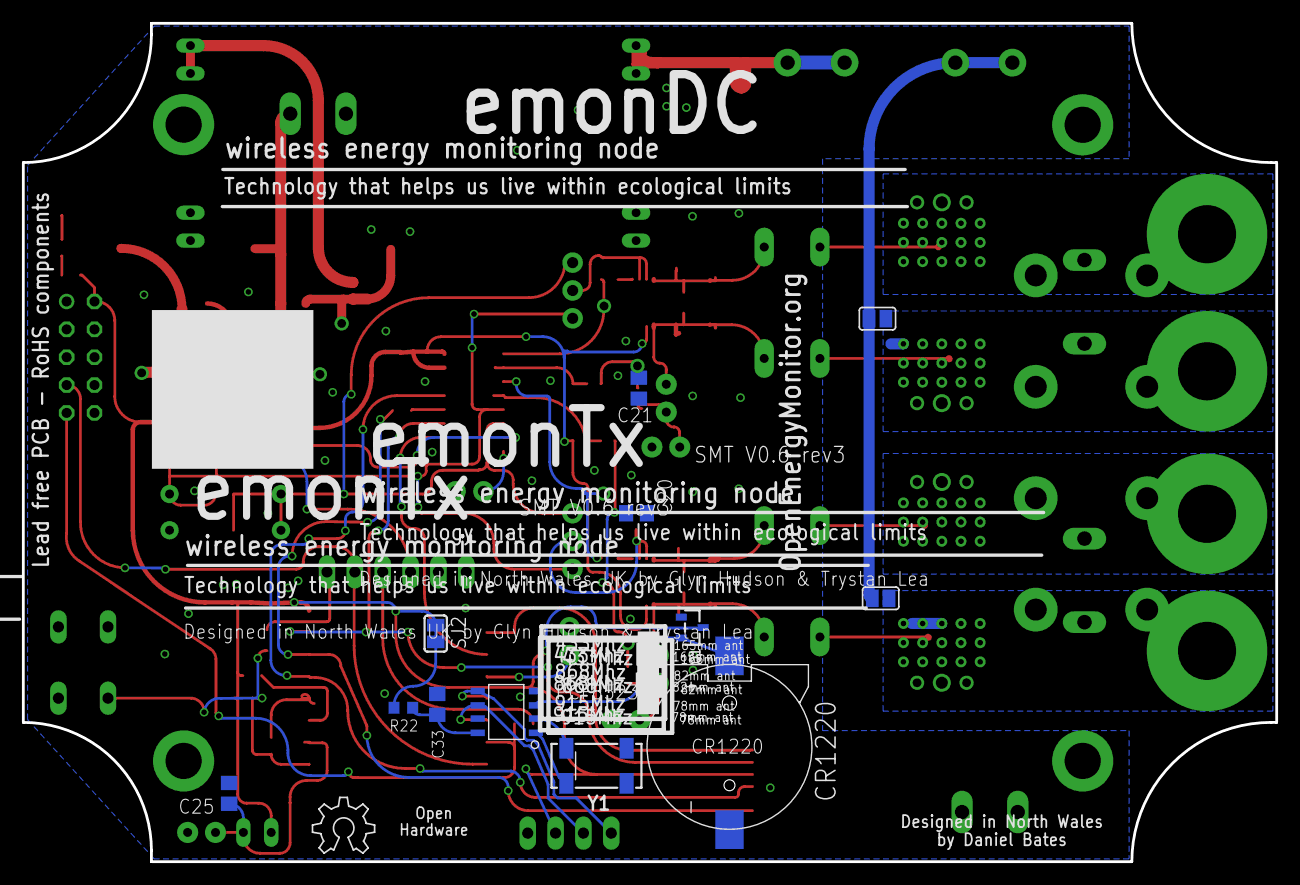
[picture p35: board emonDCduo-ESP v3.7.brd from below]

Board: 2 copper layers, 114.3 x 76.5 mm, 109 parts (14 on the bottom side), 56 nets.

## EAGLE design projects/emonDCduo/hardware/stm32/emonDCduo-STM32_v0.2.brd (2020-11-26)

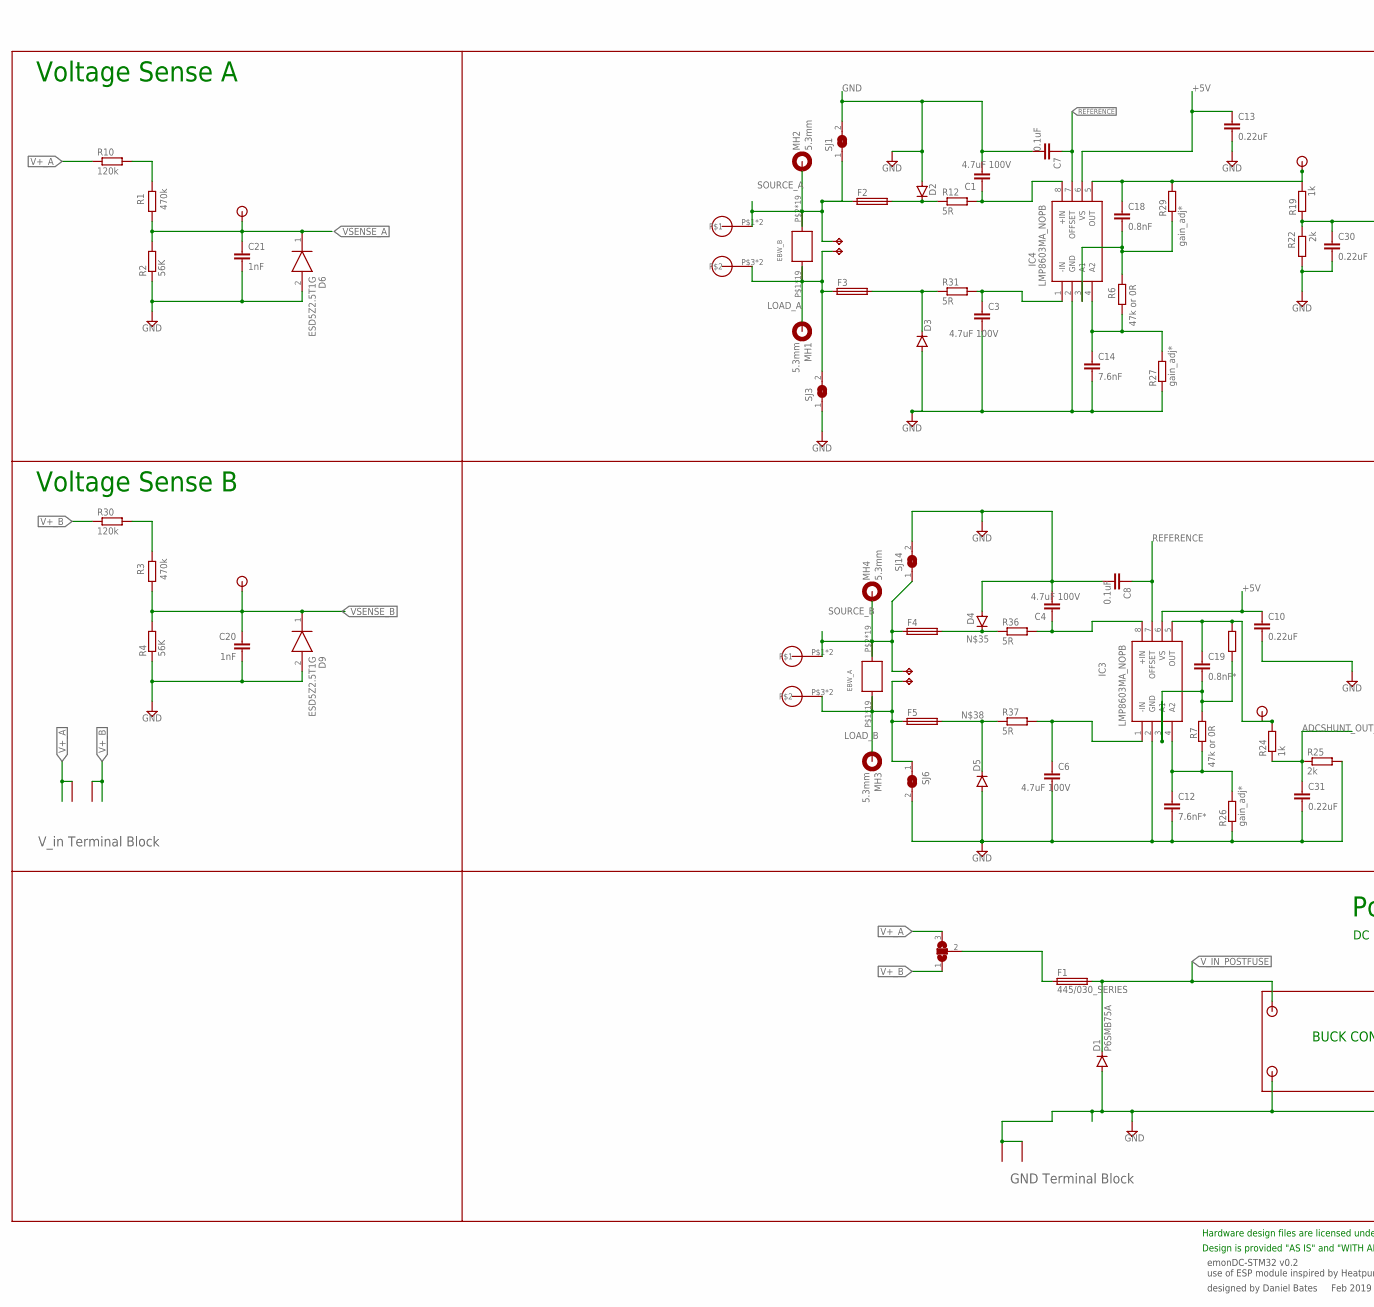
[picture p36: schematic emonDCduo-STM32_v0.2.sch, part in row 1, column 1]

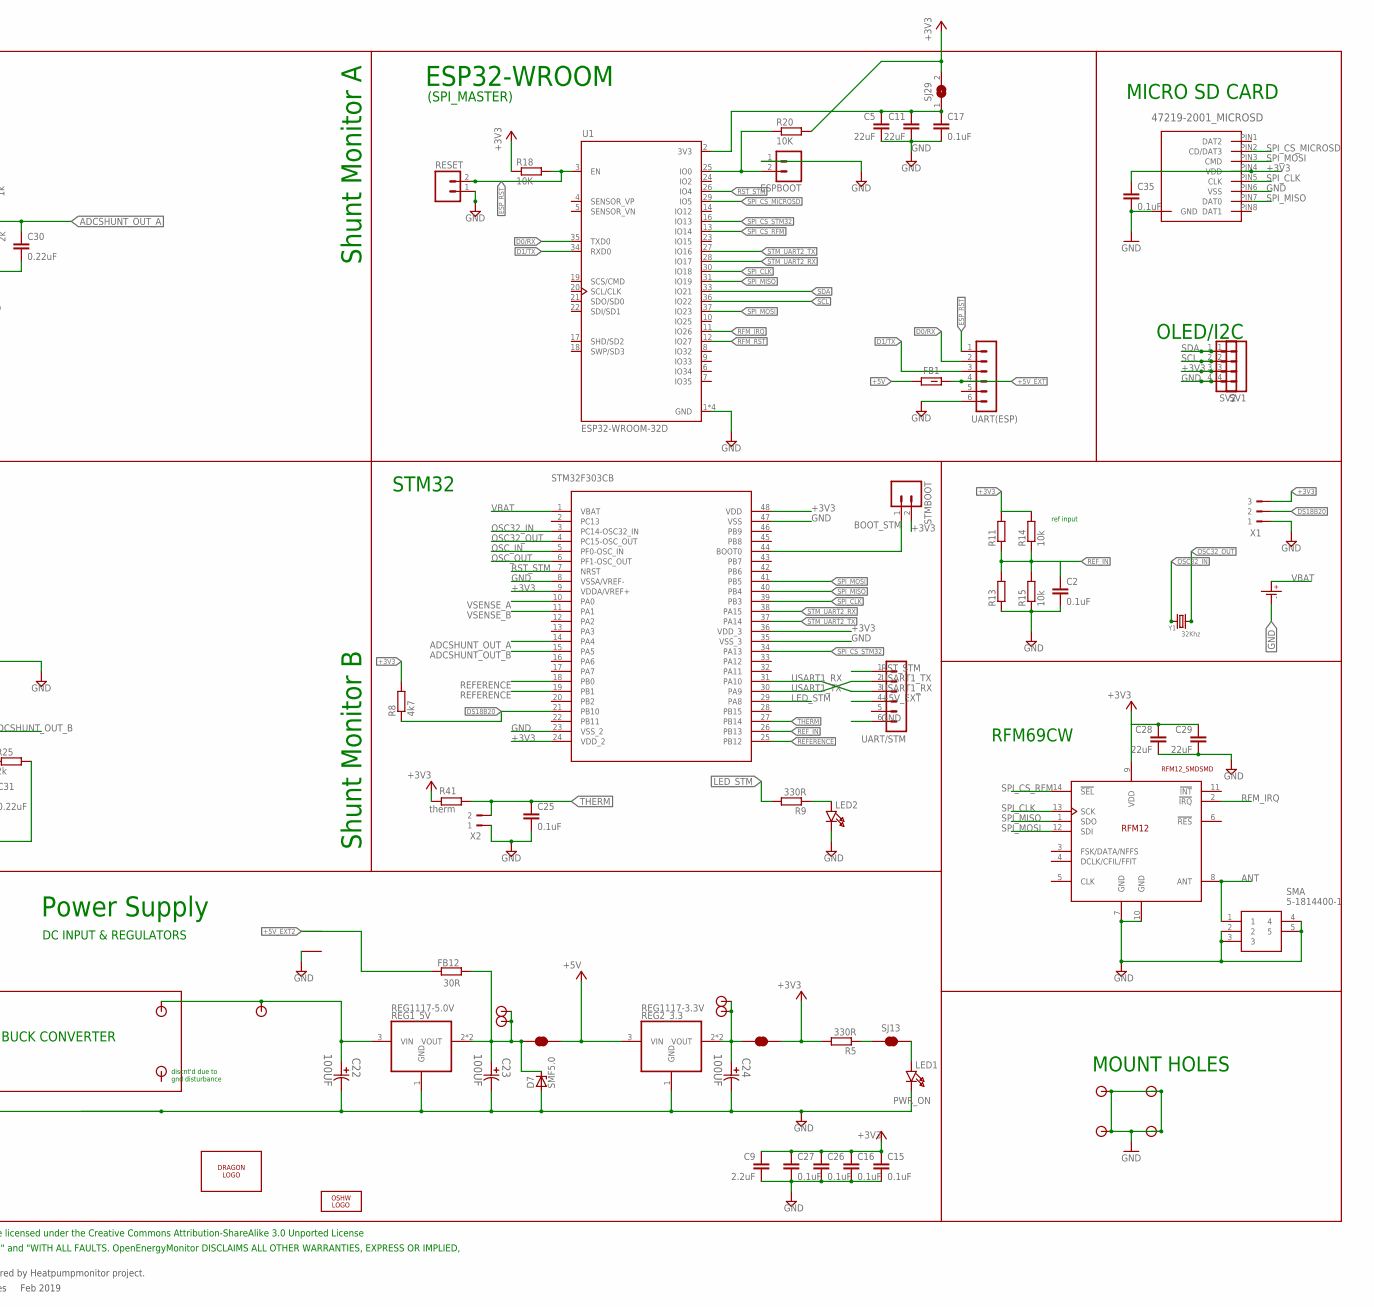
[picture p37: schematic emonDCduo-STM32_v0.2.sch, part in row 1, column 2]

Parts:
3V3, 5V: JUMPER-SMT_2_NC_TRACE_NO-SILK; SMT-JUMPER_2_NC_TRACE_NO-SILK
C1, C3, C4, C6: 4.7uF 100V; C1206; MPN C1608X7S2A104K080AB
C2, C15, C16, C17, C25, C26, C27, C35: 0.1uF; C0603
C5, C11, C28, C29: 22uF; C0805
C7, C8: 0.1uF; C0603; MPN C1608X7S2A104K080AB
C9: 2.2uF; C0805
C10, C13, C30, C31: 0.22uF; C0603; MPN C1608X7S2A104K080AB
C12: 7.6nF*; C0603
C14: 7.6nF; C0603; MPN C1608X7S2A104K080AB
C18: 0.8nF; C0603; MPN C1608X7S2A104K080AB
C19: 0.8nF*; C0603; MPN C1608X7S2A104K080AB
C20, C21: 1nF; C0603; MPN C1608X7S2A104K080AB
C22, C23, C24: 100UF; CAPAE530X610N
CR1220: CR1220SMD; MPN Harwin S8411-45R
D1: P6SMB75A; DO214AA
D2, D3, D4, D5: P6SMB75A; SMB
D6, D9: ESD5Z2.5T1G; SODFL1608X70N
D7: SMF5.0; SOD123F
EBW_A: EBW_SERIES_15.2MM
EBW_B: EBW_SERIES_15.2MM
ESPBOOT: M02PTH; 1X02
F1: 445/030_SERIES; 445/030_SERIES_LITTELFUSE
F2, F3, F4, F5: TR5
FB1: FBCHIP-0603(1608-METRIC); BEADC1608X95N
FB12: 30R; R0603
IC3, IC4: LMP8603MA_NOPB; SOIC127P600X175-8N
LED1, LED2: PWR_ON; CHIPLED_1206
LOGO1: OSHW_LOGO_6MILX0200-NT; OSHW_6X200_NOTEXT
MH1, MH2, MH3, MH4: 5.3mm; 5,3//11-PAD
MICRO_SD: 47219-2001_MICROSD
MOUNT_10.16_A, MOUNT_10.16_B: MOLEX_39970-003; 2/10,16
R1, R3: 470k; 0207/2V; MPN MCMF006FF1004A50
R2, R4: 56K; R0603; MPN MCMF006FF7502A50
R5, R9: 330R; R0603
R6, R7: 47k or 0R; R0603
R8: 4k7; R0603
R10, R30: 120k; R0603; MPN MCMF006FF1004A50
R11, R13: R-EU_0207/2V; 0207/2V
R12, R31, R36, R37: 5R; R0603; MPN MCMF006FF1004A50
R14, R15: 10k; R0603
R18, R20: 10K; R0603
R19, R24: 1k; R0603; MPN MCMF006FF1004A50
R22, R25: 2k; R0603; MPN MCMF006FF1004A50
R26, R27, R28, R29: gain_adj*; R0603; MPN MCMF006FF1004A50
R41: therm; R0603
REG1_5V: REG1117-5.0V; SOT223; MPN REG1117-5.0
REG2_3.3: REG1117-3.3V; SOT223; MPN REG1117-3.3
RESET: M02PTH; 1X02
SJ1, SJ3, SJ6, SJ14, SJ29: SJ
SJ13: JUMPER-SMT_2_NC_TRACE_NO-SILK; SMT-JUMPER_2_NC_TRACE_NO-SILK
SJ15: SJ2W; SJ_2
SMA: 5-1814400-1; 518144001
STM32F303CB: STM32F303CB_STM32F302_303C2; STM32F303CB_LQFP48-7X7MM; MANUFACTURER_PART_NUMBER STM32F303CB
STMBOOT: M02PTH; 1X02
SV1, SV2: MA04-1; MPN 2212S-04SG-85
TP8, TP9, TP10, TP11: TPPAD1-13Y; P1-13Y
U1: ESP32-WROOM-32D; MODULE_ESP32-WROOM-32D
U$1, U$4, U$5, U$6, U$7, U$8, U$9, U$18, U$19: TP0.8MM; TP0.8
U$2, U$3, U$10, U$11: 2212S-02SG-85; TP0.8_X2
U$14: RFM12_SMDSMD; RFM12
U$15, U$16, U$17: 7.62MM_TERMINAL_BLOCK; 7.62MM
U$22, U$23, U$24, U$25: TP3.5MM; TP3.5
U$26: DRAGON; DRAGON_LOGO
UART(ESP): UART/ESP; MA06-1
UART/STM: UART/STM; MA06-1
X1: 180-3
X2: 180-2
Y1: 32Khz; CRYSTAL_8X3.8

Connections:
3.3V_: 3V3.1, C24.1, REG2_3.3.2 (VOUT), REG2_3.3.4 (VOUT), U$8.P$1, U$19.P$1
5V_: 5V.1, C23.1, D7.C, FB12.1, REG1_5V.2 (VOUT), REG1_5V.4 (VOUT), U$7.P$1, U$18.P$1
6.5V: C22.1, REG1_5V.3 (VIN), U$9.P$1, U$10.P$1, U$10.P$2
+3V3: 3V3.2, C9.1, C15.1, C16.1, C26.1, C27.1, C28.1, C29.1, C35.1, MICRO_SD.PIN4 (VDD), R5.2, R8.2, R11.2, R14.2, R18.1, R20.2, R41.2, SJ29.2, STM32F303CB.9 (VDDA/VREF+), STM32F303CB.24 (VDD_2), STM32F303CB.36 (VDD_3), STM32F303CB.48 (VDD), STMBOOT.2, SV1.3, SV2.3, U$14.9 (VDD), X1.3
+3V3_ESP: C5.1, C11.1, C17.1, SJ29.1, U1.2 (3V3)
+5V: 5V.2, C10.1, C13.1, FB1.1, IC3.6 (VS), IC4.6 (VS), REG2_3.3.3 (VIN)
+5V_EXT: FB1.2, UART(ESP).4, UART/STM.4
+5V_EXT2: FB12.2, U$17.P$1
ADCSHUNT_OUT_A: C30.1, R19.1, R22.1, STM32F303CB.14 (PA4)
ADCSHUNT_OUT_A_: C18.1, IC4.5 (OUT), R19.2, R29.2, U$6.P$1
ADCSHUNT_OUT_B: C31.1, R24.1, R25.1, STM32F303CB.15 (PA5)
ADCSHUNT_OUT_B_: C19.1, IC3.5 (OUT), R24.2, R28.2, U$5.P$1
ANT: SMA.1, U$14.8 (ANT)
BOOT_STM: STM32F303CB.44 (BOOT0), STMBOOT.1
D0/RX: U1.35 (TXD0), UART(ESP).2
D1/TX: U1.34 (RXD0), UART(ESP).3
DS18B20: R8.1, STM32F303CB.21 (PB10), X1.2
ESP_RST: R18.2, RESET.2, U1.3 (EN), UART(ESP).1
GND: C1.2, C2.2, C3.2, C4.2, C5.2, C6.2, C7.2, C8.2, C9.2, C10.2, C11.2, C12.2, C13.2, C14.2, C15.2, C16.2, C17.2, C20.2, C21.2, C22.2, C23.2, C24.2, C25.2, C26.2, C27.2, C28.2, C29.2, C30.2, C31.2, C35.2, CR1220.P- (P$-), D1.A, D2.A, D3.A, D4.A, D5.A, D6.2 (A), D7.A, D9.2 (A), ESPBOOT.1, IC3.2 (GND), IC4.2 (GND), LED1.C, LED2.C, MICRO_SD.P$1 (GND), MICRO_SD.P$2 (GND), MICRO_SD.P$3 (GND), MICRO_SD.P$4 (GND), MICRO_SD.PIN6 (VSS), R2.1, R4.1, R13.1, R15.1, R22.2, R25.2, R26.1, R27.1, REG1_5V.1 (GND), REG2_3.3.1 (GND), RESET.1, SJ1.2, SJ3.1, SJ6.2, SJ14.2, SMA.2, SMA.3, SMA.4, SMA.5, STM32F303CB.8 (VSSA/VREF-), STM32F303CB.23 (VSS_2), STM32F303CB.35 (VSS_3), STM32F303CB.47 (VSS), SV1.4, SV2.4, U1.1 (GND), U1.15 (GND), U1.38 (GND), U1.39 (GND), U$3.P$1, U$3.P$2, U$14.7 (GND), U$14.10 (GND), U$16.P$1, U$16.P$2, U$17.P$2, U$22.P$1, U$23.P$1, U$24.P$1, U$25.P$1, UART(ESP).6, UART/STM.6, X1.1, X2.1
LED_STM: R9.2, STM32F303CB.29 (PA8)
LOAD_A: EBW_B.P$1, EBW_B.P$3, EBW_B.P$4, EBW_B.P$5, EBW_B.P$6, EBW_B.P$7, EBW_B.P$8, EBW_B.P$9, EBW_B.P$10, EBW_B.P$11, EBW_B.P$12, EBW_B.P$13, EBW_B.P$14, EBW_B.P$15, EBW_B.P$16, EBW_B.P$17, EBW_B.P$33, EBW_B.P$34, EBW_B.P$35, F3.1, MH1.B5,5, MOUNT_10.16_A.P$3, MOUNT_10.16_A.P$4, SJ3.2, TP10.TP
LOAD_B: EBW_A.P$1, EBW_A.P$3, EBW_A.P$4, EBW_A.P$5, EBW_A.P$6, EBW_A.P$7, EBW_A.P$8, EBW_A.P$9, EBW_A.P$10, EBW_A.P$11, EBW_A.P$12, EBW_A.P$13, EBW_A.P$14, EBW_A.P$15, EBW_A.P$16, EBW_A.P$17, EBW_A.P$33, EBW_A.P$34, EBW_A.P$35, F5.1, MH3.B5,5, MOUNT_10.16_B.P$3, MOUNT_10.16_B.P$4, SJ6.1, TP8.TP
LOAD_B_T: C6.1, IC3.1 (-IN), R37.2
LOAD_T_A: C3.1, IC4.1 (-IN), R31.2
unnamed: C14.1, IC4.4 (A2), R6.2, R27.2
unnamed: C18.2, IC4.3 (A1), R6.1, R29.1
unnamed: R5.1, SJ13.1
unnamed: LED1.A, SJ13.2
unnamed: F1.P$1 (1), F1.P$2 (1), SJ15.2
unnamed: R3.1, R30.2
unnamed: R1.1, R10.2
unnamed: C19.2, IC3.3 (A1), R7.1, R28.1
unnamed: C12.1, IC3.4 (A2), R7.2, R26.2
unnamed: ESPBOOT.2, R20.1, U1.25 (IO0)
unnamed: LED2.A, R9.1
unnamed: D2.C, F2.2, R12.1
unnamed: D3.C, F3.2, R31.1
unnamed: D4.C, F4.2, R36.1
unnamed: D5.C, F5.2, R37.1
OSC32_IN: STM32F303CB.3 (PC14-OSC32_IN), Y1.P$1 (1)
OSC32_OUT: STM32F303CB.4 (PC15-OSC_OUT), Y1.P$4 (2)
OSC_IN: STM32F303CB.5 (PF0-OSC_IN)
OSC_OUT: STM32F303CB.6 (PF1-OSC_OUT)
REFERENCE: C7.1, C8.1, IC3.7 (OFFSET), IC4.7 (OFFSET), STM32F303CB.18 (PB0), STM32F303CB.19 (PB1), STM32F303CB.25 (PB12)
REF_IN: C2.1, R11.1, R13.2, R14.1, R15.2, STM32F303CB.26 (PB13)
RFM_IRQ: U1.11 (IO26), U$14.2 (!IRQ)
RFM_RST: U1.12 (IO27)
RST_STM: STM32F303CB.7 (NRST), U1.26 (IO4), UART/STM.1
SCL: SV1.2, SV2.2, U1.36 (IO22)
SDA: SV1.1, SV2.1, U1.33 (IO21)
SOURCE_A: EBW_B.P$2, EBW_B.P$18, EBW_B.P$19, EBW_B.P$20, EBW_B.P$21, EBW_B.P$22, EBW_B.P$23, EBW_B.P$24, EBW_B.P$25, EBW_B.P$26, EBW_B.P$27, EBW_B.P$28, EBW_B.P$29, EBW_B.P$30, EBW_B.P$31, EBW_B.P$32, EBW_B.P$36, EBW_B.P$37, EBW_B.P$38, F2.1, MH2.B5,5, MOUNT_10.16_A.P$1, MOUNT_10.16_A.P$2, SJ1.1, TP11.TP
SOURCE_B: EBW_A.P$2, EBW_A.P$18, EBW_A.P$19, EBW_A.P$20, EBW_A.P$21, EBW_A.P$22, EBW_A.P$23, EBW_A.P$24, EBW_A.P$25, EBW_A.P$26, EBW_A.P$27, EBW_A.P$28, EBW_A.P$29, EBW_A.P$30, EBW_A.P$31, EBW_A.P$32, EBW_A.P$36, EBW_A.P$37, EBW_A.P$38, F4.1, MH4.B5,5, MOUNT_10.16_B.P$1, MOUNT_10.16_B.P$2, SJ14.1, TP9.TP
SOURCE_B_T: C4.1, IC3.8 (+IN), R36.2
SOURCE_T_A: C1.1, IC4.8 (+IN), R12.2
SPI_CLK: MICRO_SD.PIN5 (CLK), STM32F303CB.39 (PB3), U1.30 (IO18), U$14.13 (SCK)
SPI_CS_MICROSD: MICRO_SD.PIN2 (CD/DAT3), U1.29 (IO5)
SPI_CS_RFM: U1.13 (IO14), U$14.14 (!SEL)
SPI_CS_STM32: STM32F303CB.34 (PA13), U1.16 (IO13)
SPI_MISO: MICRO_SD.PIN7 (DAT0), STM32F303CB.40 (PB4), U1.31 (IO19), U$14.1 (SDO)
SPI_MOSI: MICRO_SD.PIN3 (CMD), STM32F303CB.41 (PB5), U1.37 (IO23), U$14.12 (SDI)
STM_UART2_RX: STM32F303CB.38 (PA15), U1.28 (IO17)
STM_UART2_TX: STM32F303CB.37 (PA14), U1.27 (IO16)
THERM: C25.1, R41.1, STM32F303CB.27 (PB14), X2.2
USART1_RX: STM32F303CB.31 (PA10), UART/STM.3
USART1_TX: STM32F303CB.30 (PA9), UART/STM.2
V+_A: R10.1, SJ15.3, U$15.P$2
V+_B: R30.1, SJ15.1, U$15.P$1
VBAT: CR1220.P+ (P$+), STM32F303CB.1 (VBAT)
VSENSE_A: C21.1, D6.1 (K), R1.2, R2.2, STM32F303CB.10 (PA0), U$1.P$1
VSENSE_B: C20.1, D9.1 (K), R3.2, R4.2, STM32F303CB.11 (PA1), U$4.P$1
V_IN_POSTFUSE: D1.C, F1.P$3 (2), F1.P$4 (2), U$2.P$1, U$2.P$2

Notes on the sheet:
emonDC-STM32 v0.2 use of ESP module inspired by Heatpumpmonitor project.
designed by Daniel Bates Feb 2019
Power Supply
Design is provided "AS IS" and "WITH ALL FAULTS. OpenEnergyMonitor DISCLAIMS ALL OTHER WARRANTIES, EXPRESS OR IMPLIED,
Hardware design files are licensed under the Creative Commons Attribution-ShareAlike 3.0 Unported License
DC INPUT & REGULATORS
Shunt Monitor B
Shunt Monitor A
ESP32-WROOM
MICRO SD CARD
STM32
MOUNT HOLES
OLED/I2C
RFM69CW
Voltage Sense A
Voltage Sense B
V_in Terminal Block
GND Terminal Block
(SPI_MASTER)
BUCK CONVERTER
discnt'd due to gnd disturbance
ref input

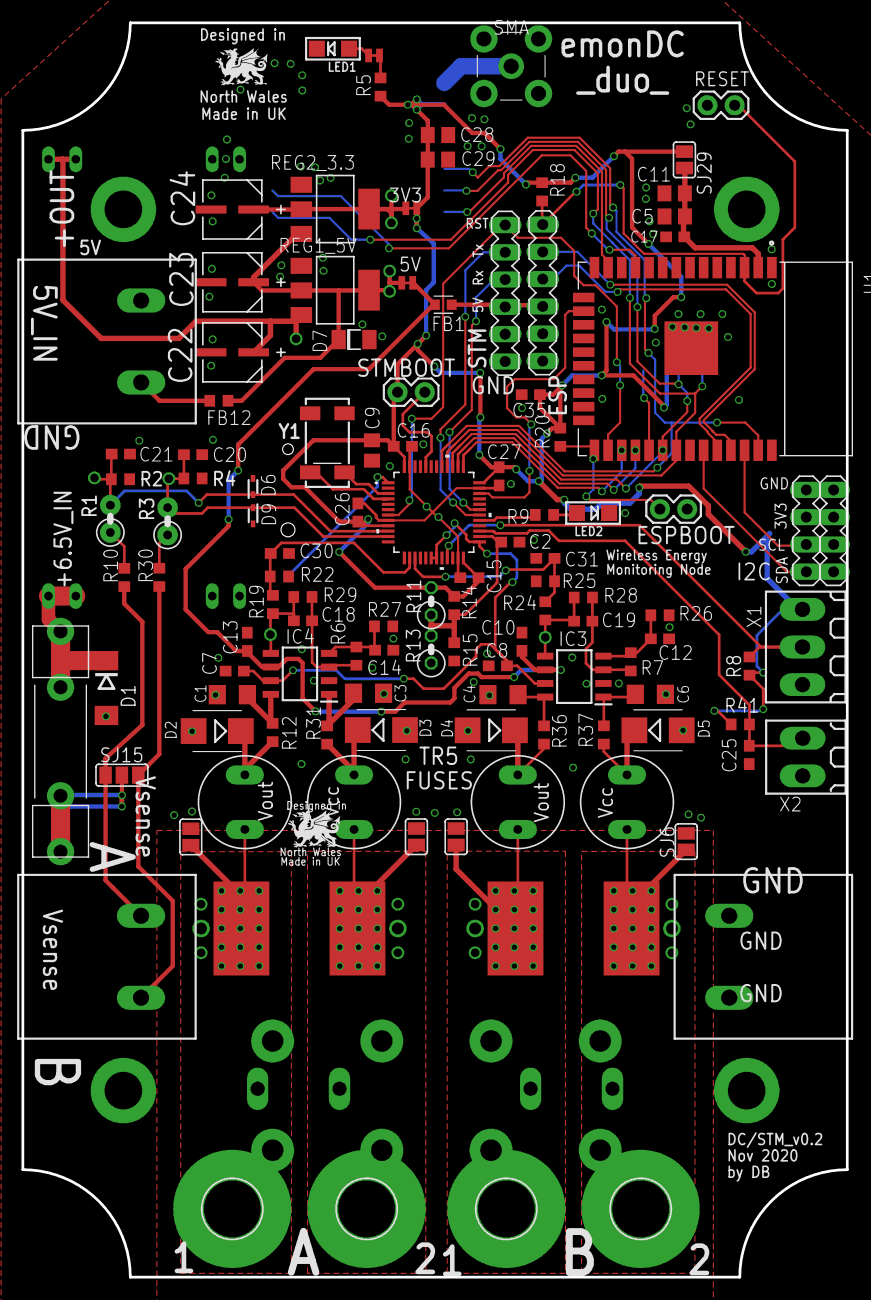
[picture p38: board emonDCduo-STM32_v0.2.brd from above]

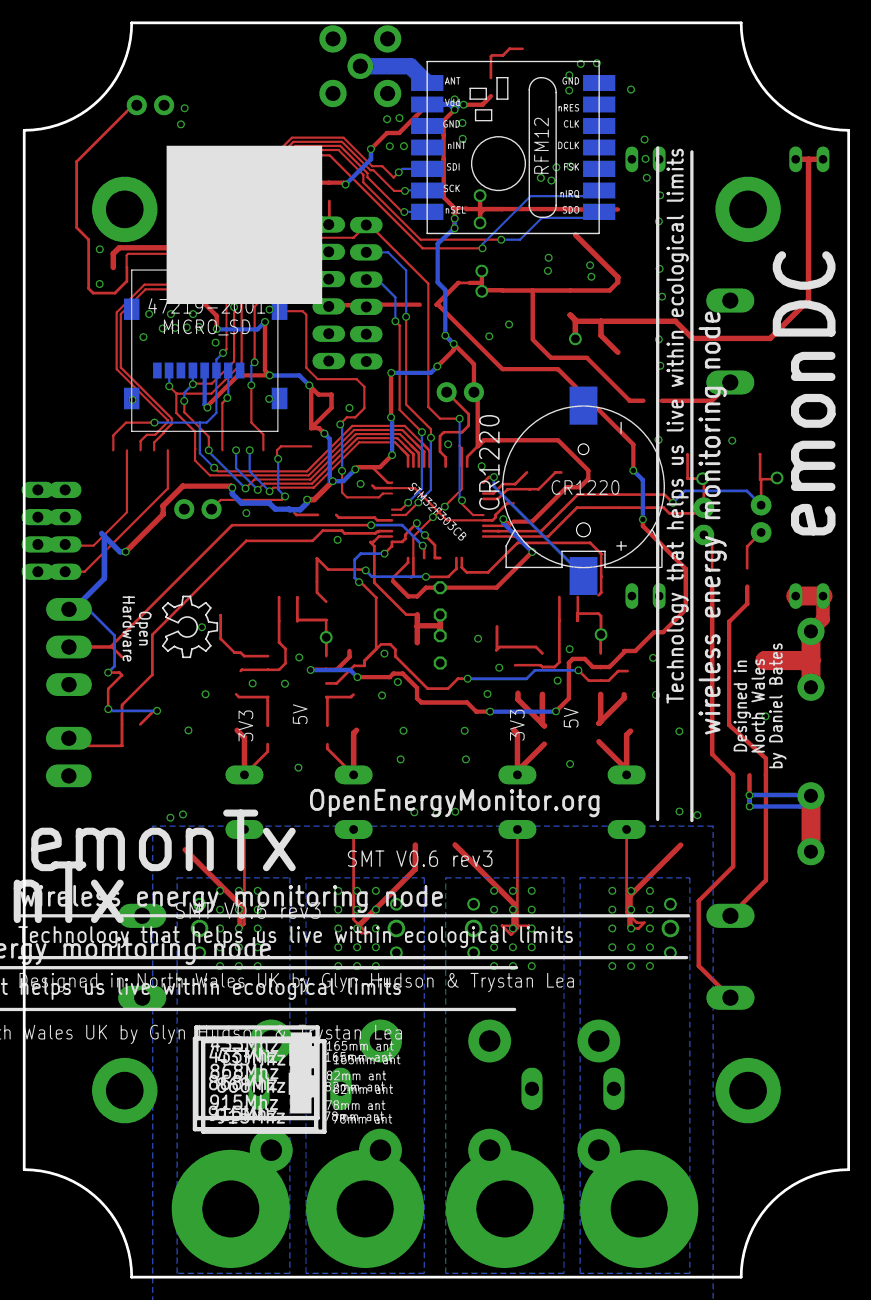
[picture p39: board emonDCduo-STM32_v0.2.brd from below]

Board: 2 copper layers, 76.7 x 116.7 mm, 142 parts (4 on the bottom side), 68 nets.

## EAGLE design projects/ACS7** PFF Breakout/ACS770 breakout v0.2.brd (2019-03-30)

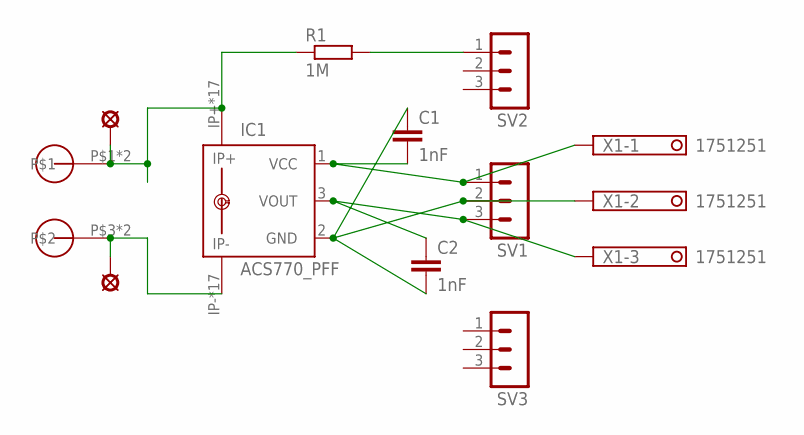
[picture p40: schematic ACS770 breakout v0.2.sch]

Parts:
C1, C2: 1nF; C025-025X050
IC1: ACS770_PFF; CB-PFF
LSP1, LSP2: LSP13
R1: 1M; 0411/15
SV1, SV2, SV3: MA03-1
U$5: MOLEX_39970-003; 2/10,16
X1: 1751251

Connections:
GND: C1.1, C2.2, IC1.2 (GND), SV1.2, X1.2
unnamed: C1.2, IC1.1 (VCC), SV1.1, X1.1
unnamed: R1.2, SV2.1
unnamed: C2.1, IC1.3 (VOUT), SV1.3, X1.3
unnamed: IC1.IP-, IC1.IP-@2 (IP-), IC1.IP-@3 (IP-), IC1.IP-@4 (IP-), IC1.IP-@5 (IP-), IC1.IP-@6 (IP-), IC1.IP-@7 (IP-), IC1.IP-@8 (IP-), IC1.IP-@9 (IP-), IC1.IP-@10 (IP-), IC1.IP-@11 (IP-), IC1.IP-@12 (IP-), IC1.IP-@13 (IP-), IC1.IP-@14 (IP-), IC1.IP-@15 (IP-), IC1.IP-@16 (IP-), IC1.IP-@17 (IP-), LSP2.MP, U$5.P$3, U$5.P$4
unnamed: IC1.IP+, IC1.IP+@2 (IP+), IC1.IP+@3 (IP+), IC1.IP+@4 (IP+), IC1.IP+@5 (IP+), IC1.IP+@6 (IP+), IC1.IP+@7 (IP+), IC1.IP+@8 (IP+), IC1.IP+@9 (IP+), IC1.IP+@10 (IP+), IC1.IP+@11 (IP+), IC1.IP+@12 (IP+), IC1.IP+@13 (IP+), IC1.IP+@14 (IP+), IC1.IP+@15 (IP+), IC1.IP+@16 (IP+), IC1.IP+@17 (IP+), LSP1.MP, R1.1, U$5.P$1, U$5.P$2

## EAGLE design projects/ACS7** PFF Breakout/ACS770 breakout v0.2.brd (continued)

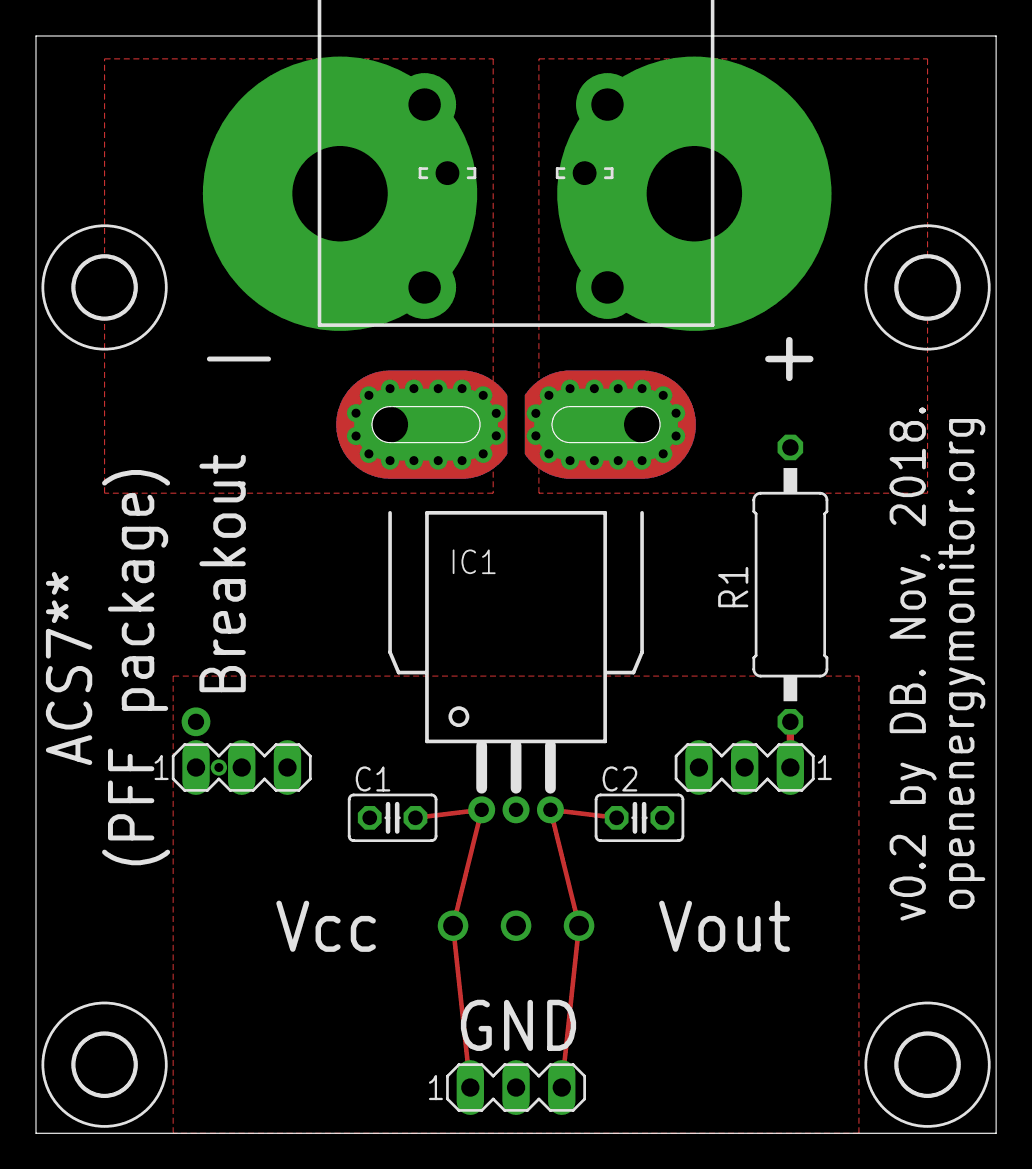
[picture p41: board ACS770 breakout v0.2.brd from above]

Board: 2 copper layers, 53.3 x 61.0 mm, 15 parts (1 on the bottom side), 6 nets.

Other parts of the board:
U$1, U$2, U$3, U$4: 3,3

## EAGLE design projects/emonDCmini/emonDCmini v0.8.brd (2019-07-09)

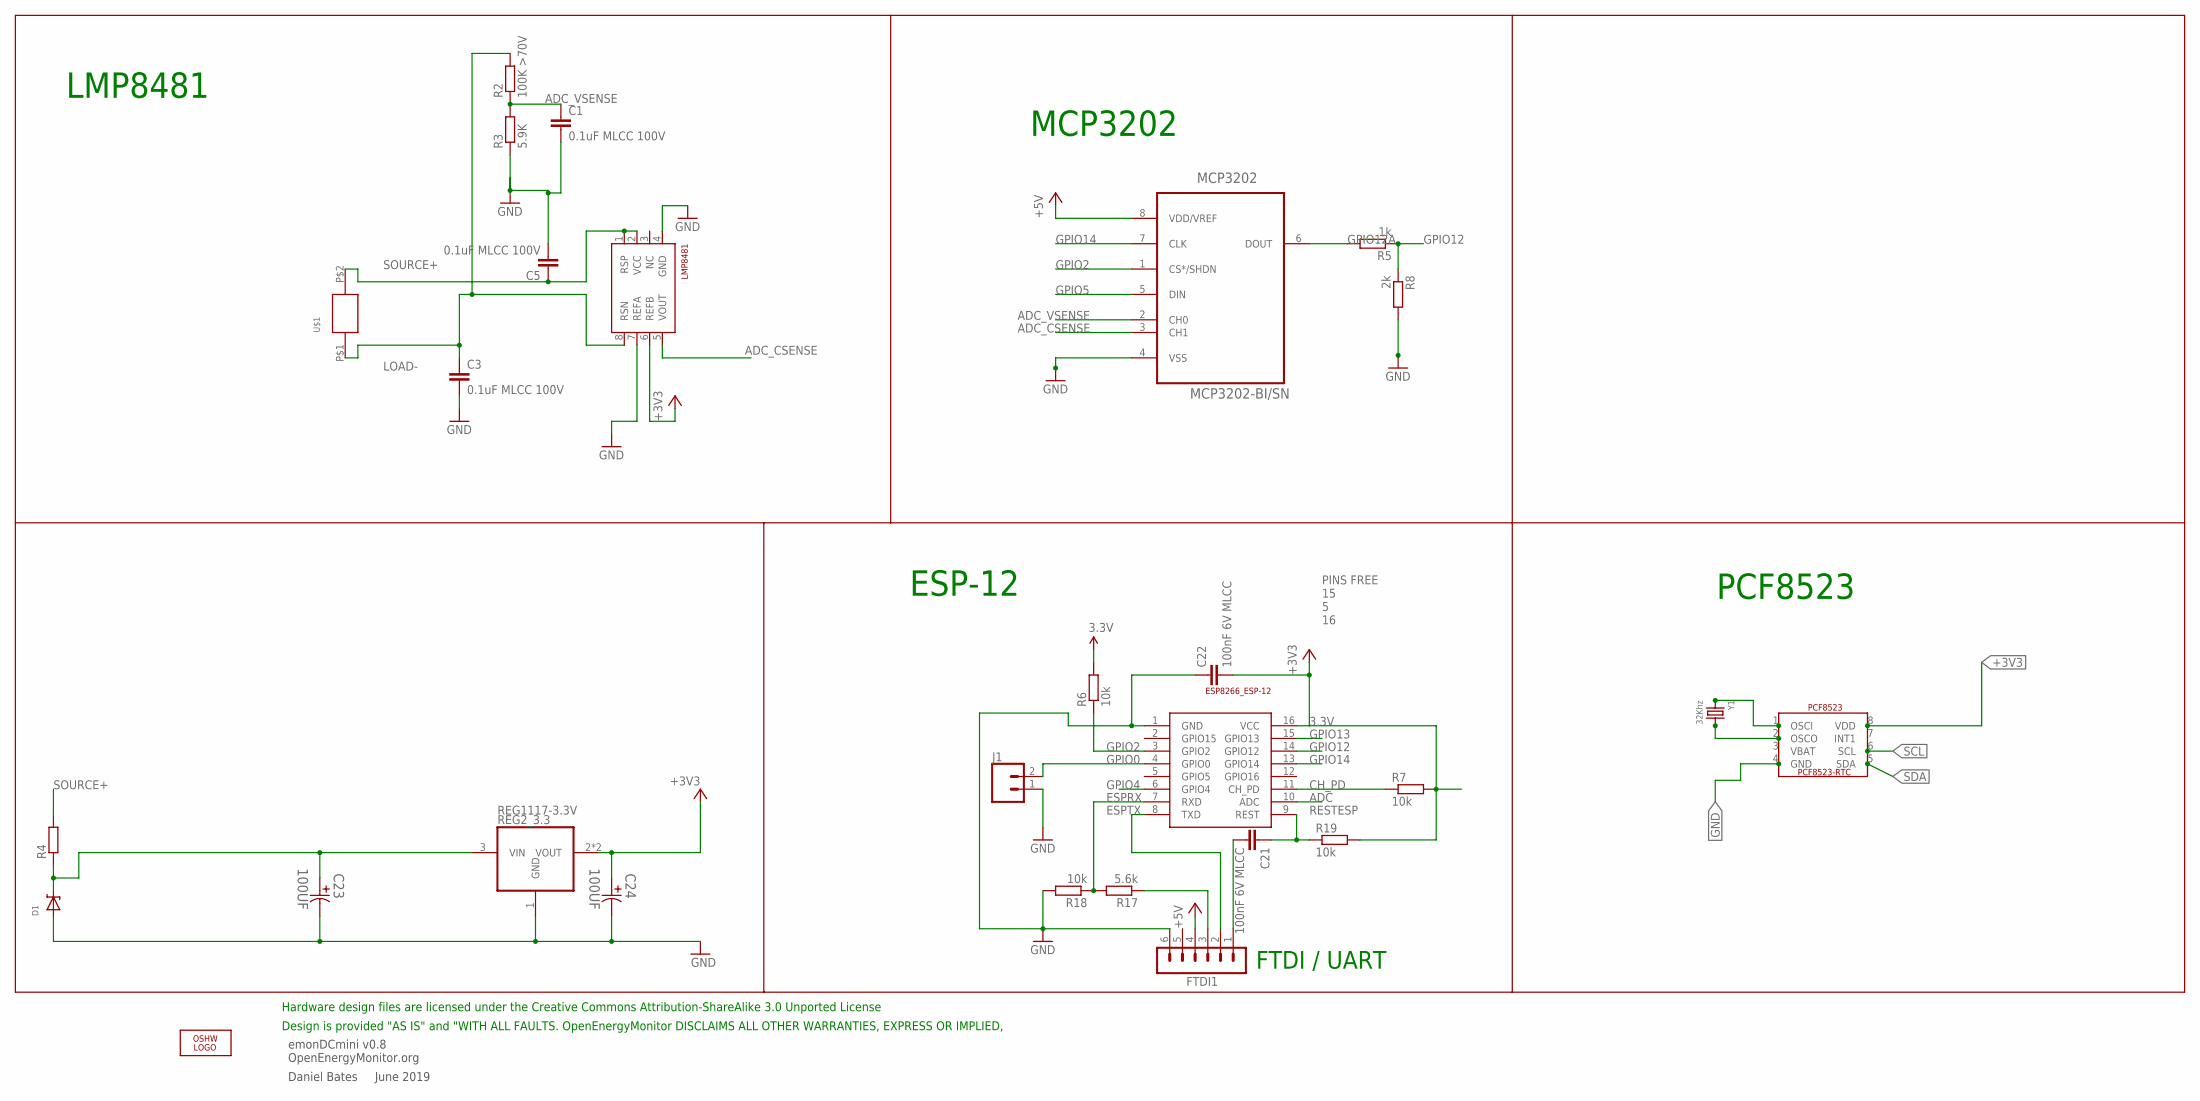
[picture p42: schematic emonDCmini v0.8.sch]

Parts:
C1, C3, C5: 0.1uF MLCC 100V; C0805
C21, C22: 100nF 6V MLCC; C0805
C23, C24: 100UF; CAPAE530X610N
D1: DIODE-ZENER; SMADIODE
ESP-12: ESP8266_ESP-12; ESP8266-ESP12
FTDI1: FTDI-ESP; MA06-1
J1: CONN_02; 1X02
LMP8481: LMP8481-H; S-PDSO-G08
LOGO1: OSHW_LOGO_6MILX0200-NT; OSHW_6X200_NOTEXT
MCP3202: MCP3202-BI/SN; SOIC127P600X175-8N
PCF8523: PCF8523_RTC; SOIC_8
R2: 100K >70V; R0603; MPN MCWR06X1003FTL
R3: 5.9K; R0603; MPN MCWR06X5901FTL
R4: R-EU_R2512; R2512
R5: 1k; R0603
R6, R7, R18, R19: 10k; R0603
R8: 2k; R0603
R17: 5.6k; R0603
REG2_3.3: REG1117-3.3V; SOT223; MPN REG1117-3.3
U$1: EBW_SERIES_10.5MM
Y1: 32Khz; CRYSTAL_8X3.8

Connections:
3.3V: C22.2, ESP-12.16 (VCC), LMP8481.6 (REFB), R6.2, R7.2, R19.2
6.5V: C23.1, D1.C, R4.1, REG2_3.3.3 (VIN)
+3V3: C24.1, PCF8523.8 (VDD), REG2_3.3.2 (VOUT), REG2_3.3.4 (VOUT)
+5V: FTDI1.4, MCP3202.8 (VDD/VREF)
ADC: ESP-12.10 (ADC)
ADC_CSENSE: LMP8481.5 (VOUT), MCP3202.3 (CH1)
ADC_VSENSE: C1.1, MCP3202.2 (CH0), R2.1, R3.2
CH_PD: ESP-12.11 (CH_PD), R7.1
ESPRX: ESP-12.7 (RXD), R17.2, R18.1
ESPTX: ESP-12.8 (TXD), FTDI1.2
GND: C1.2, C3.2, C5.2, C22.1, C23.2, C24.2, D1.A, ESP-12.1 (GND), FTDI1.6, J1.1, LMP8481.4 (GND), LMP8481.7 (REFA), MCP3202.4 (VSS), PCF8523.4 (GND), R3.1, R8.2, R18.2, REG2_3.3.1 (GND)
GPIO0: ESP-12.4 (GPIO0), J1.2
GPIO2: ESP-12.3 (GPIO2), MCP3202.1 (CS*/SHDN), R6.1
GPIO4: ESP-12.6 (GPIO4)
GPIO5: MCP3202.5 (DIN)
GPIO12: ESP-12.14 (GPIO12), R5.1, R8.1
GPIO12A: MCP3202.6 (DOUT), R5.2
GPIO13: ESP-12.15 (GPIO13)
GPIO14: ESP-12.13 (GPIO14), MCP3202.7 (CLK)
LOAD-: C3.1, LMP8481.8 (RSN), R2.2, U$1.P$1
unnamed: FTDI1.3, R17.1
unnamed: PCF8523.2 (OSCO), Y1.P$4 (2)
unnamed: PCF8523.1 (OSCI), Y1.P$1 (1)
RESTESP: C21.1, ESP-12.9 (REST), R19.1
RST: C21.2, FTDI1.1
SCL: PCF8523.6 (SCL)
SDA: PCF8523.5 (SDA)
SOURCE+: C5.1, LMP8481.1 (RSP), LMP8481.2 (VCC), R4.2, U$1.P$2

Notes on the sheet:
emonDCmini v0.8 OpenEnergyMonitor.org
Daniel Bates June 2019
Design is provided "AS IS" and "WITH ALL FAULTS. OpenEnergyMonitor DISCLAIMS ALL OTHER WARRANTIES, EXPRESS OR IMPLIED,
Hardware design files are licensed under the Creative Commons Attribution-ShareAlike 3.0 Unported License
LMP8481
ESP-12
PINS FREE 15 5 16
MCP3202
FTDI / UART
PCF8523

Board: 2 copper layers, 29 parts (9 on the bottom side), 22 nets, no tracks yet.

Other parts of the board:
U$3: DRAGON_LOGO_NOTEXT

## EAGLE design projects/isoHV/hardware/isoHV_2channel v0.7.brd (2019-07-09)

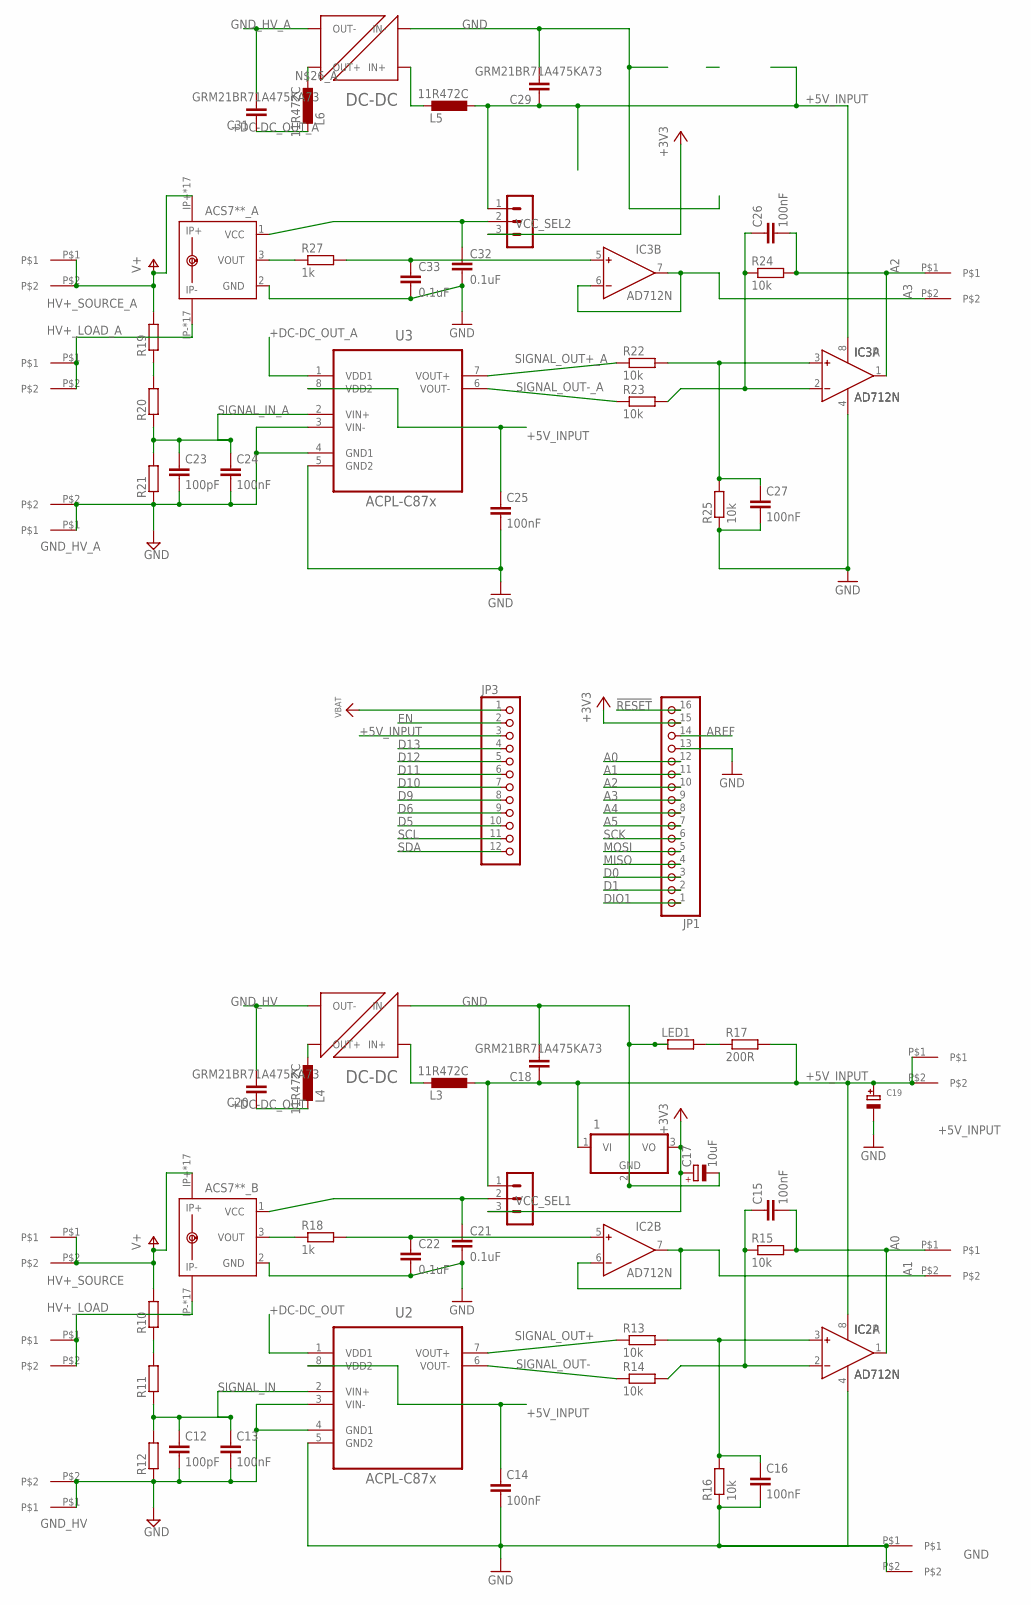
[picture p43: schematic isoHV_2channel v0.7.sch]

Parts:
1: 7805TV; TO220V
ACS7**_A, ACS7**_B: ACS758KCB-150B-PFF-T; CB-PFF; MPN ACS7**
C12, C23: 100pF; C025-025X050
C13, C14, C15, C16, C24, C25, C26, C27: 100nF; C025-025X050
C17: 10uF; B45181A
C18, C29: GRM21BR71A475KA73; C025-025X050
C19: CAP_ELECTROLYTICPTH_3.5MMGRID_10MMDIA; CELEC_3.5MM_10MM
C20, C31: GRM21BR71A475KA73; C025-050X050
C21, C22, C32, C33: 0.1uF; C025-025X050
IC2, IC3: AD712N; DIL08
JP1: HEADER-1X16ROUND; 1X16_ROUND
JP3: HEADER-1X12; 1X12_ROUND
L3, L4, L5, L6: 11R472C; 0204V
LED1: R-EU_0204/2V; 0204V
R10, R11, R12, R19, R20, R21: R-EU_0411/15; 0411/15
R13, R14, R15, R16, R22, R23, R24, R25: 10k; 0204/7
R17: 200R; 0204V
R18, R27: 1k; 0204/7
U2, U3: ACPL-C87x; SOIC127P1150X330-8N
U$8, U$9, U$10, U$14, U$15, U$16, U$21, U$22, U$25, U$26: 7.62MM_TERMINAL_BLOCK; 7.62MM
U$17, U$27: NXF1
VCC_SEL1, VCC_SEL2: MA03-1

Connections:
!RESET: JP1.16
+3V3: 1.3 (VO), C17.+, JP1.15, VCC_SEL1.3, VCC_SEL2.3
+5V_INPUT: 1.1 (VI), C14.1, C18.1, C19.+, C25.1, C29.1, IC2.8 (V+), IC3.8 (V+), JP3.3, L3.2, L5.2, R17.2, U2.8 (VDD2), U3.8 (VDD2), U$10.P$1, U$10.P$2, VCC_SEL1.1, VCC_SEL2.1
+DC-DC_OUT: C20.1, L4.1, U2.1 (VDD1)
+DC-DC_OUT_A: C31.1, L6.1, U3.1 (VDD1)
A0: C15.2, IC2.1 (OUT), JP1.12, R15.2, U$15.P$1
A1: IC2.6 (IN-), IC2.7 (OUT), JP1.11, U$15.P$2
A2: C26.2, IC3.1 (OUT), JP1.10, R24.2, U$25.P$1
A3: IC3.6 (IN-), IC3.7 (OUT), JP1.9, U$25.P$2
A4: JP1.8
A5: JP1.7
AREF: JP1.14
D0: JP1.3
D1: JP1.2
D5: JP3.10
D6: JP3.9
D9: JP3.8
D10: JP3.7
D11: JP3.6
D12: JP3.5
D13: JP3.4
DIO1: JP1.1
EN: JP3.2
GND: 1.2 (GND), ACS7**_A.2 (GND), ACS7**_B.2 (GND), C14.2, C16.2, C17.-, C18.2, C19.-, C21.2, C22.2, C25.2, C27.2, C29.2, C32.2, C33.2, IC2.4 (V-), IC3.4 (V-), JP1.13, LED1.1, R16.1, R25.1, U2.5 (GND2), U3.5 (GND2), U$14.P$1, U$14.P$2, U$17.P$1 (IN-), U$27.P$1 (IN-)
GND_HV: C12.2, C13.2, C20.2, R12.1, U2.3 (VIN-), U2.4 (GND1), U$9.P$1, U$9.P$2, U$17.P$7 (OUT-)
GND_HV_A: C23.2, C24.2, C31.2, R21.1, U3.3 (VIN-), U3.4 (GND1), U$22.P$1, U$22.P$2, U$27.P$7 (OUT-)
HV+_LOAD: ACS7**_B.IP-, ACS7**_B.IP-@2 (IP-), ACS7**_B.IP-@3 (IP-), ACS7**_B.IP-@4 (IP-), ACS7**_B.IP-@5 (IP-), ACS7**_B.IP-@6 (IP-), ACS7**_B.IP-@7 (IP-), ACS7**_B.IP-@8 (IP-), ACS7**_B.IP-@9 (IP-), ACS7**_B.IP-@10 (IP-), ACS7**_B.IP-@11 (IP-), ACS7**_B.IP-@12 (IP-), ACS7**_B.IP-@13 (IP-), ACS7**_B.IP-@14 (IP-), ACS7**_B.IP-@15 (IP-), ACS7**_B.IP-@16 (IP-), ACS7**_B.IP-@17 (IP-), U$16.P$1, U$16.P$2
HV+_LOAD_A: ACS7**_A.IP-, ACS7**_A.IP-@2 (IP-), ACS7**_A.IP-@3 (IP-), ACS7**_A.IP-@4 (IP-), ACS7**_A.IP-@5 (IP-), ACS7**_A.IP-@6 (IP-), ACS7**_A.IP-@7 (IP-), ACS7**_A.IP-@8 (IP-), ACS7**_A.IP-@9 (IP-), ACS7**_A.IP-@10 (IP-), ACS7**_A.IP-@11 (IP-), ACS7**_A.IP-@12 (IP-), ACS7**_A.IP-@13 (IP-), ACS7**_A.IP-@14 (IP-), ACS7**_A.IP-@15 (IP-), ACS7**_A.IP-@16 (IP-), ACS7**_A.IP-@17 (IP-), U$26.P$1, U$26.P$2
HV+_SOURCE: ACS7**_B.IP+, ACS7**_B.IP+@2 (IP+), ACS7**_B.IP+@3 (IP+), ACS7**_B.IP+@4 (IP+), ACS7**_B.IP+@5 (IP+), ACS7**_B.IP+@6 (IP+), ACS7**_B.IP+@7 (IP+), ACS7**_B.IP+@8 (IP+), ACS7**_B.IP+@9 (IP+), ACS7**_B.IP+@10 (IP+), ACS7**_B.IP+@11 (IP+), ACS7**_B.IP+@12 (IP+), ACS7**_B.IP+@13 (IP+), ACS7**_B.IP+@14 (IP+), ACS7**_B.IP+@15 (IP+), ACS7**_B.IP+@16 (IP+), ACS7**_B.IP+@17 (IP+), R10.2, U$8.P$1, U$8.P$2
HV+_SOURCE_A: ACS7**_A.IP+, ACS7**_A.IP+@2 (IP+), ACS7**_A.IP+@3 (IP+), ACS7**_A.IP+@4 (IP+), ACS7**_A.IP+@5 (IP+), ACS7**_A.IP+@6 (IP+), ACS7**_A.IP+@7 (IP+), ACS7**_A.IP+@8 (IP+), ACS7**_A.IP+@9 (IP+), ACS7**_A.IP+@10 (IP+), ACS7**_A.IP+@11 (IP+), ACS7**_A.IP+@12 (IP+), ACS7**_A.IP+@13 (IP+), ACS7**_A.IP+@14 (IP+), ACS7**_A.IP+@15 (IP+), ACS7**_A.IP+@16 (IP+), ACS7**_A.IP+@17 (IP+), R19.2, U$21.P$1, U$21.P$2
MISO: JP1.4
MOSI: JP1.5
unnamed: R10.1, R11.2
unnamed: C16.1, IC2.3 (IN+), R13.2, R16.2
unnamed: C15.1, IC2.2 (IN-), R14.2, R15.1
unnamed: ACS7**_B.1 (VCC), C21.1, VCC_SEL1.2
unnamed: C22.1, IC2.5 (IN+), R18.2
unnamed: LED1.2, R17.1
unnamed: L3.1, U$17.P$3 (IN+)
unnamed: L4.2, U$17.P$8 (OUT+)
unnamed: ACS7**_B.3 (VOUT), R18.1
unnamed: R19.1, R20.2
unnamed: C27.1, IC3.3 (IN+), R22.2, R25.2
unnamed: C26.1, IC3.2 (IN-), R23.2, R24.1
unnamed: ACS7**_A.1 (VCC), C32.1, VCC_SEL2.2
unnamed: C33.1, IC3.5 (IN+), R27.2
unnamed: L5.1, U$27.P$3 (IN+)
unnamed: L6.2, U$27.P$8 (OUT+)
unnamed: ACS7**_A.3 (VOUT), R27.1
SCK: JP1.6
SCL: JP3.11
SDA: JP3.12
SIGNAL_IN: C12.1, C13.1, R11.1, R12.2, U2.2 (VIN+)
SIGNAL_IN_A: C23.1, C24.1, R20.1, R21.2, U3.2 (VIN+)
SIGNAL_OUT+: R13.1, U2.7 (VOUT+)
SIGNAL_OUT+_A: R22.1, U3.7 (VOUT+)
SIGNAL_OUT-: R14.1, U2.6 (VOUT-)
SIGNAL_OUT-_A: R23.1, U3.6 (VOUT-)
VBAT: JP3.1

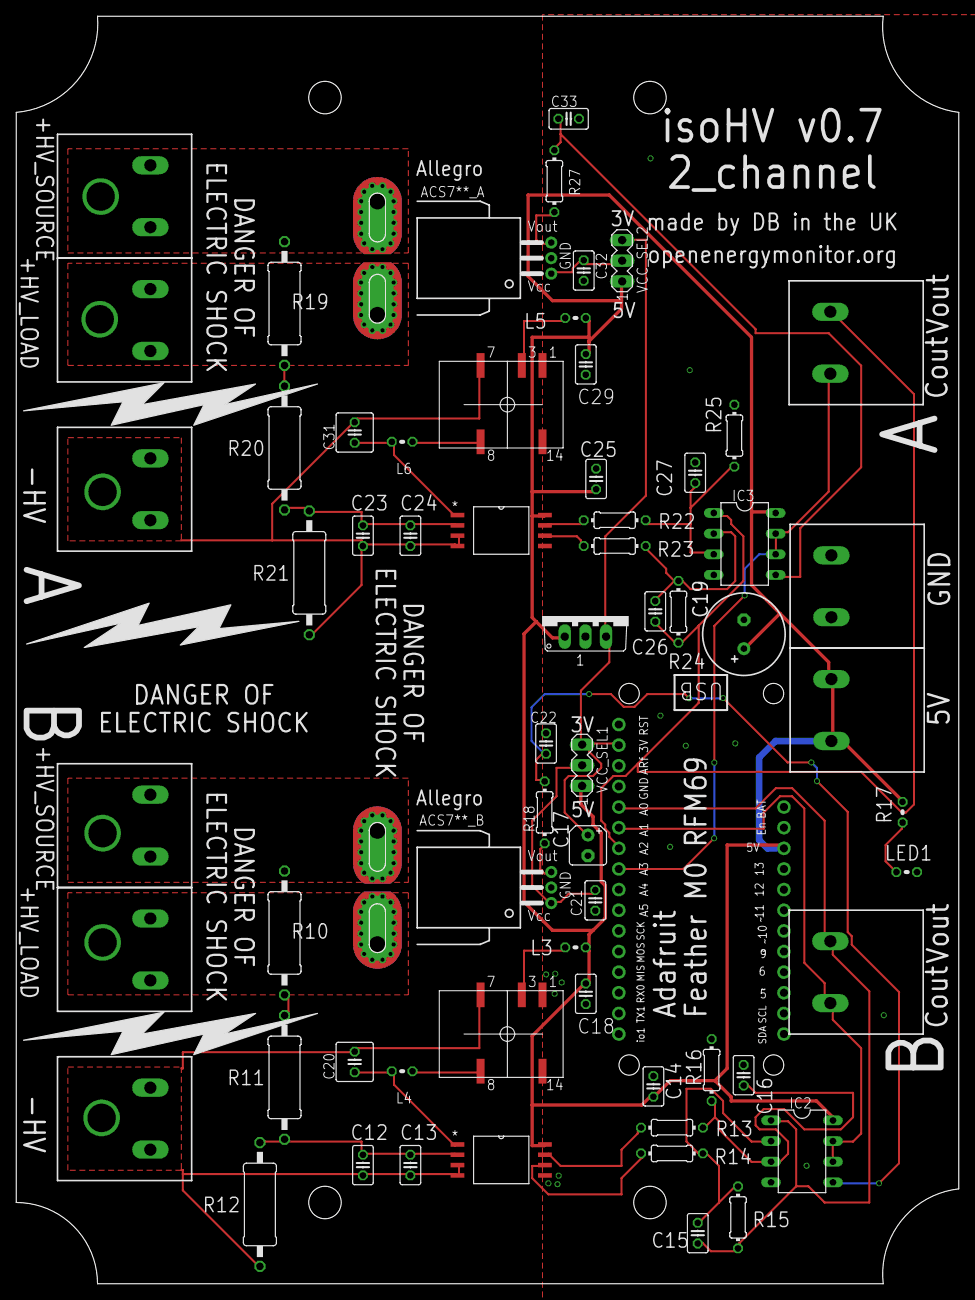
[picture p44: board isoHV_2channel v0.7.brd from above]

Board: 2 copper layers, 116.0 x 156.0 mm, 65 parts (0 on the bottom side), 38 nets.

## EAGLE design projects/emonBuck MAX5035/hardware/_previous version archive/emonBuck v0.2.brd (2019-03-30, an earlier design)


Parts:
C1: 100uF 80V; CAPAE1350X1400N
C2: 470uF 16V; CAPAE830X1050N
C3, C4, C5, C6, C7: 0.1uF 100V; C0603
D1: MBRS1100T3G; SMB_1; MPN MBRS1100T3G
L1: SRR1208; SSR1208; MPN SRR1208-151YL
LOGO1: OSHW_LOGO_6MILX0200-NT; OSHW_6X200_NOTEXT
MAX5035: MAX5035; 21-0111D_SBE-14; MPN MAX5035EASA+
R1: 700K; R0603
R2, R3: 200k; B64W
R4: 10k; R0603
U$1, U$2, U$3, U$4: TP0.8MM; TP0.8

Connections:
BST: C4.1, MAX5035.1 (BST)
GND: C1.2, C2.2, C3.2, C5.2, C6.2, C7.2, D1.A, MAX5035.3 (SGND), MAX5035.6 (GND), R2.A, R4.1, U$2.P$1, U$4.P$1
LX: C4.2, D1.C, L1.1, MAX5035.8 (LX/OUT)
unnamed: MAX5035.4 (FB), R3.S, R4.2
unnamed: C7.1, MAX5035.5 (ON/OFF), R2.S
unnamed: R1.1, R2.E
PRE_6.5V: C2.1, C6.1, L1.2, R3.A, U$3.P$1
VD: C5.1, MAX5035.2 (VD)
V_IN_POSTFUSE: C1.1, C3.1, MAX5035.7 (V_IN), R1.2, U$1.P$1



Board: 2 copper layers, 54.3 x 21.6 mm, 19 parts (2 on the bottom side), 9 nets.

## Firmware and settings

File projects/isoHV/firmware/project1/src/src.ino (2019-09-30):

#include <SPI.h>
#include <RH_RF69.h>

/************ Radio Setup ***************/

// Change to 434.0 or other frequency, must match RX's freq!
#define RF69_FREQ 433.0

#if defined(ADAFRUIT_FEATHER_M0) // Feather M0 w/Radio
#define RFM69_CS      8
#define RFM69_INT     3
#define RFM69_RST     4
#define LED           13
#endif

RH_RF69 rf69(RFM69_CS, RFM69_INT);

int16_t packetnum = 0;  // packet counter, we increment per xmission

/************ Other Setup ***************/


unsigned long numberofsamples = 0;

const long interval = 10000; // ms

unsigned long previousMillis = 0;

float CH_A_CURRENT_AVERAGED;
float CH_A_VOLTAGE_AVERAGED;
float CH_B_CURRENT_AVERAGED;
float CH_B_VOLTAGE_AVERAGED;
float Voltage_A;
float Current_A;
float Voltage_B;
float Current_B;
float Wh_chA = 0.0;
float Wh_chB = 0.0;
unsigned long CH_A_CURRENT_ACCUMULATOR = 0;
unsigned long CH_A_VOLTAGE_ACCUMULATOR = 0;
unsigned long CH_B_CURRENT_ACCUMULATOR = 0;
unsigned long CH_B_VOLTAGE_ACCUMULATOR = 0;

String ADC_KeyValue_String = "Hellow";

void setup()
{
  delay(2000);
  Serial.begin(115200);
  pinMode(LED, OUTPUT);
  pinMode(RFM69_RST, OUTPUT);
  digitalWrite(RFM69_RST, LOW);

  Serial.println();

  // manual reset
  digitalWrite(RFM69_RST, HIGH);
  delay(10);
  digitalWrite(RFM69_RST, LOW);
  delay(10);

  if (!rf69.init()) {
    Serial.println("RFM69 radio init failed");
    while (1);
  }
  Serial.println("RFM69 radio init OK!");
  // Defaults after init are 434.0MHz, modulation GFSK_Rb250Fd250, +13dbM (for low power module)
  // No encryption
  if (!rf69.setFrequency(RF69_FREQ)) {
    Serial.println("setFrequency failed");
  }

  // If you are using a high power RF69 eg RFM69HW, you *must* set a Tx power with the
  // ishighpowermodule flag set like this:
  rf69.setTxPower(14, true);  // range from 14-20 for power, 2nd arg must be true for 69HCW

  // The encryption key has to be the same as the one in the server
  uint8_t key[] = { 0x01, 0x02, 0x03, 0x04, 0x05, 0x06, 0x07, 0x08,
                    0x01, 0x02, 0x03, 0x04, 0x05, 0x06, 0x07, 0x08
                  };
  //rf69.setEncryptionKey(key);

  pinMode(LED, OUTPUT);

  Serial.print("RFM69 radio @");  Serial.print((int)RF69_FREQ);  Serial.println(" MHz");

  analogReadResolution(12);
}



void loop() {

  int sensor_Volts_B = analogRead(A0);
  int sensor_Amps_B = analogRead(A1);
  int sensor_Volts_A = analogRead(A2);
  int sensor_Amps_A = analogRead(A3);
  CH_A_CURRENT_ACCUMULATOR = CH_A_CURRENT_ACCUMULATOR + sensor_Amps_A;
  CH_A_VOLTAGE_ACCUMULATOR = CH_A_VOLTAGE_ACCUMULATOR + sensor_Volts_A;
  CH_B_CURRENT_ACCUMULATOR = CH_B_CURRENT_ACCUMULATOR + sensor_Amps_B;
  CH_B_VOLTAGE_ACCUMULATOR = CH_B_VOLTAGE_ACCUMULATOR + sensor_Volts_B;
  numberofsamples ++;

  unsigned long currentMillis = millis();
  if (currentMillis - previousMillis >= interval) {
    previousMillis = currentMillis;

    CH_A_CURRENT_AVERAGED = CH_A_CURRENT_ACCUMULATOR / numberofsamples;
    CH_A_VOLTAGE_AVERAGED = CH_A_VOLTAGE_ACCUMULATOR / numberofsamples;
    CH_B_CURRENT_AVERAGED = CH_B_CURRENT_ACCUMULATOR / numberofsamples;
    CH_B_VOLTAGE_AVERAGED = CH_B_VOLTAGE_ACCUMULATOR / numberofsamples;

    CH_A_CURRENT_ACCUMULATOR = 0;
    CH_A_VOLTAGE_ACCUMULATOR = 0;
    CH_B_CURRENT_ACCUMULATOR = 0;
    CH_B_VOLTAGE_ACCUMULATOR = 0;
    numberofsamples = 0;

    ADC_KeyValue_String = "V_A:";
    ADC_KeyValue_String = ADC_KeyValue_String + CH_A_VOLTAGE_AVERAGED;
    ADC_KeyValue_String = ADC_KeyValue_String + ",";
    ADC_KeyValue_String = ADC_KeyValue_String + "C_A:";
    ADC_KeyValue_String = ADC_KeyValue_String + CH_A_CURRENT_AVERAGED;
    ADC_KeyValue_String = ADC_KeyValue_String + ",";
    ADC_KeyValue_String = ADC_KeyValue_String + "V_B:";
    ADC_KeyValue_String = ADC_KeyValue_String + CH_B_VOLTAGE_AVERAGED;
    ADC_KeyValue_String = ADC_KeyValue_String + ",";
    ADC_KeyValue_String = ADC_KeyValue_String + "C_B:";
    ADC_KeyValue_String = ADC_KeyValue_String + CH_B_CURRENT_AVERAGED;

 
    char radiopacket[60] = "hellow"; // to init
    //itoa(packetnum++, radiopacket + 13, 10);
    strcpy(radiopacket, ADC_KeyValue_String.c_str());
    Serial.print("Sending \"");
    Serial.print(radiopacket);
    Serial.println("\"");

    // Send a message!
    Blink(LED, 10, 1);
    rf69.send((uint8_t *)radiopacket, strlen(radiopacket));
    rf69.waitPacketSent();
  }
}

void Blink(byte PIN, byte DELAY_MS, byte loops) {
  for (byte i = 0; i < loops; i++)  {
    digitalWrite(PIN, HIGH);
    delay(DELAY_MS);
    digitalWrite(PIN, LOW);
    delay(DELAY_MS);
  }
}

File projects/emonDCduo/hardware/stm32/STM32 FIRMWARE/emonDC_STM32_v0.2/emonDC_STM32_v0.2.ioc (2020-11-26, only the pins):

Mcu.UserName=STM32F303CBTx
PA0.GPIO_Label=VSENSE_A
PA0.Signal=ADC1_IN1
PA1.GPIO_Label=VSENSE_B
PA1.Signal=ADC1_IN2
PA10.Signal=USART1_RX
PA13.GPIO_Label=spi_cs
PA13.Signal=GPIO_Input
PA14.Signal=USART2_TX
PA15.Signal=USART2_RX
PA4.GPIO_Label=CURRENT_A
PA4.Signal=ADC2_IN1
PA5.GPIO_Label=CURRENT_B
PA5.Signal=ADC2_IN2
PA8.GPIO_Label=LED1
PA8.Signal=GPIO_Output
PA9.Signal=USART1_TX
PB0.GPIO_Label=REFERENCE_A
PB0.Signal=ADC3_IN12
PB1.GPIO_Label=REFERENCE_B
PB1.Signal=ADC3_IN1
PB10.GPIO_Label=DS18B20
PB10.Signal=USART3_TX
PB12.GPIO_Label=REF_OUT
PB12.Signal=OPAMP4_VOUT
PB13.GPIO_Label=REF_IN
PB13.Signal=OPAMP4_VINP
PB14.GPIO_Label=THERM
PB14.Signal=ADC4_IN4
PB3.Signal=SPI1_SCK
PB4.Signal=SPI1_MISO
PB5.Signal=SPI1_MOSI
PB6.Signal=I2C1_SCL
PB7.Signal=I2C1_SDA
PB8.Signal=S_TIM8_CH2
PC14-OSC32_IN.Signal=RCC_OSC32_IN
PC15-OSC32_OUT.Signal=RCC_OSC32_OUT

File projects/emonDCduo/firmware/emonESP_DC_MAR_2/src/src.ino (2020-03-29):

/*
   -------------------------------------------------------------------
   EmonESP Serial to Emoncms gateway
   -------------------------------------------------------------------
   Adaptation of Chris Howells OpenEVSE ESP Wifi
   by Trystan Lea, Glyn Hudson, OpenEnergyMonitor
   All adaptation GNU General Public License as below.

   Changed for emonDC by Daniel Bates.
   -------------------------------------------------------------------

   This file is part of OpenEnergyMonitor.org project.
   EmonESP is free software; you can redistribute it and/or modify
   it under the terms of the GNU General Public License as published by
   the Free Software Foundation; either version 3, or (at your option)
   any later version.
   EmonESP is distributed in the hope that it will be useful,
   but WITHOUT ANY WARRANTY; without even the implied warranty of
   MERCHANTABILITY or FITNESS FOR A PARTICULAR PURPOSE.  See the
   GNU General Public License for more details.
   You should have received a copy of the GNU General Public License
   along with EmonESP; see the file COPYING.  If not, write to the
   Free Software Foundation, Inc., 59 Temple Place - Suite 330,
   Boston, MA 02111-1307, USA.
*/

// Working for ESP8266 'Arduino' framework 2.4.2 https://github.com/platformio/platform-espressif8266/releases/tag/v1.8.0
// NTC library: https://github.com/arduino-libraries/NTPClient
// RTC library: https://github.com/adafruit/RTClib
// PubSubClient library: https://github.com/knolleary/pubsubclient
// AsyncWebServer library: https://github.com/me-no-dev/ESPAsyncWebServer

#include "emonesp.h"
#include "config.h"
#include <WiFi.h>
#include "wifi.h"
#include "web_server.h"
#include "ota.h"
#include "input.h"
#include "emoncms.h"
#include "mqtt.h"
#include "emondc.h" // emonDC additions.
#include "gpio0.h" // button pressing.
#include "sleep.h" // deep-sleep mode management.


// -------------------------------------------------------------------
// SETUP
// -------------------------------------------------------------------
void setup() {
  Serial.begin(460800); // boom!

  DEBUG.println();
  DEBUG.print("EmonESP ");
  DEBUG.println(ESP.getChipId());

  DEBUG.println("Firmware: " + currentfirmware);

  DEBUG.print("Reset cause: ");
  DEBUG.println(ESP.getResetReason());

  // Deep sleep wake-up routine (for a low-power-mode idea).
  if (ESP.getResetReason() == "Deep-Sleep Wake") {
    // wake_from_sleep();
  }
  else {
    // Read saved settings from the config
    config_load_settings();
    // Read emonDC settings from JSON file.
    config_load_settings_spiffs();
    // Initialise the WiFi
    wifi_setup();
    // Bring up the web server
    web_server_setup();
    // Start the OTA update systems
    ota_setup();
    // emonDC related inits - SD card, RTC etc.
    emondc_setup();

    DEBUG.println("Server started");
  }
} // end setup


// -------------------------------------------------------------------
// LOOP
// -------------------------------------------------------------------
void loop() {
  //ESP.deepSleep(2000000, WAKE_RF_DEFAULT);
  //Serial.println(millis());
  //sleep_check();

  ota_loop();
  web_server_loop();
  wifi_loop();
  emondc_loop();
  gpio0_loop();
  
  
  String input = "";
  boolean gotInput = input_get(input);

  if (wifi_mode == WIFI_MODE_STA || wifi_mode == WIFI_MODE_AP_AND_STA) {
    if (emoncms_apikey != 0 && gotInput) {
      emoncms_publish(input);
    }
    if (mqtt_server != 0)
    {
      mqtt_loop();
      if (gotInput) {
        mqtt_publish(input);
      }
    }
  }
  yield();
}

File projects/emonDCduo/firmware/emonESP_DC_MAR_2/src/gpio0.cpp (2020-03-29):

#include "emonesp.h"
#include "wifi.h"
#include "config.h"
#include "mqtt.h"
#include "gpio0.h"

int LEDpin = LED_BUILTIN;
unsigned long TimeButtonPressed;
unsigned long button_delay_AP = 6000; // ms for AP mode.
unsigned long button_delay_RST = 11000; // ms for factory reset.
bool buttonISRflag = false;
bool _button_flag_one = false;
bool _button_flag_two = false;

void gpio0_setup() {
  pinMode(0, INPUT);
  attachInterrupt(digitalPinToInterrupt(0), gpio0_isr, FALLING);
}

void ICACHE_RAM_ATTR gpio0_isr() { // ISR
  buttonISRflag = true;
}

void gpio0_loop() { // check the buttonflag and perform action
  // if button released, clear the flags.
  if (buttonISRflag && digitalRead(0)) { 
    Serial.println("Button Released");
    buttonISRflag = false;
    _button_flag_one = false;
    _button_flag_two = false;
    TimeButtonPressed = 0;
  }
  else if (buttonISRflag && TimeButtonPressed == 0) {
    TimeButtonPressed = millis();
  }
  else if (buttonISRflag) {
    if (!_button_flag_one) {
      Serial.println("Button pressed!");
      _button_flag_one = true;
    }
    else if (!_button_flag_two && TimeButtonPressed + button_delay_AP <= millis()) {
      Serial.println("Button held, AP mode!");
      led_flash(300, 300);
      led_flash(300, 300);
      Serial.println("AP mode starting..");
      wifi_mode = WIFI_MODE_AP_ONLY;
      startAP();
      _button_flag_two = true;
    }
    else if (TimeButtonPressed + button_delay_RST <= millis()) {
      Serial.println("Button held, Factor Reset!");
      led_flash(800, 800);
      Serial.println("Commencing factory reset.");
      delay(500);
      config_reset();
      Serial.println("Factory reset complete! Resetting...");
      led_flash(800, 800);
      led_flash(800, 800);
      led_flash(800, 800);
      ESP.restart();
    }
  } //buttonflag
} // end GPIO0 button.

void led_flash(int ton, int toff) {
  digitalWrite(LEDpin,LOW); delay(ton); digitalWrite(LEDpin,HIGH); delay(toff);
}

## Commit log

2016-12-15 emonDCuno
    unidirectional single input high voltage emonDC
    [emonDC BOM v0.1.xls, emonDC v0.2a.brd, emonDC v0.2a.sch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]
2016-12-15 folder update
    [emonDC BOM v0.1.xls, emonDC v0.2a.brd, emonDC v0.2a.sch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]
2016-12-23 ESP addition and dual shunt monitors
    [emonDC v0.3a.brd, emonDC v0.3a.sch, emonDCduo-ESP v0.3.brd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]
2016-12-26 SD CARD TO DUO
    [emonDC v0.2.brd, emonDC v0.2.sch, emonDCduo-ESP v0.3.brd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]
2016-12-26 short write protect pins
    [emonDCduo-ESP v0.3.brd, emonDCduo-ESP v0.3.sch]
2016-12-27 micro sd card library
    pinout in schematic TBD
    [emonDCduo-ESP v0.3.brd, emonDCduo-ESP v0.3.sch]
2017-01-03 board layout changes
    [emonDCduo-ESP+RF v0.3.brd, emonDCduo-ESP+RF v0.3.sch]
2017-01-03 images attached
    [emonDCduo-ESP+RF v0.3.brd, emonDCduo-ESP+RF v0.3.sch]
2017-01-05 RFM69 onto board
    [emonDC v0.2.sch, emonDC v0.3a.brd, emonDC v0.3a.sch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]
2017-01-06 layout changes
    [emonDCduo-ESP v0.4.brd]
2017-01-07 DRC edited
    [emonDCduo-ESP v0.4.brd, emonDCduo-ESP v0.4.sch]
2017-01-08 antenna caps removed. camexport
    [emonDCduo-ESP v0.4.brd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]
2017-01-28 emonDCbike design first draft
    [emonBike.brd, emonBike.sch, emonDCbike.brd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]
2017-02-16 updating v1.0
    [emonBike v0.1.brd, emonBike v0.1.sch, emonBike v0.2.brd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]
2017-03-18 added DIP switch to ESP RX/TX
    [emonDCduo-ESP v1.0.brd, emonDCduo-ESP v1.0.sch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]
2017-03-29 emonBIKE v0.2 camexport
    [emonBike v0.2.brd, emonBike v0.2.sch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]
2017-04-05 emonBike v0.3
    [emonBike v0.3.brd, emonBike v0.3.sch]
2017-05-23 src commit
    [emonBike v0.1.brd, emonBike v0.1.sch, emonBike v0.2.brd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]
2017-06-14 emonDCmini v0.4 sent to ragworm
    [emonDCmini v0.4.brd, emonDCmini v0.4.sch]
2017-06-17 update
    chip select set to GPIO4 for both mini and duo.
    mini updated, various minor changes for v0.5.
    molex micro sd card library improved
    [emonDCduo-ESP v1.0.brd, emonDCduo-ESP v1.0.sch, emonDCmini v0.5.brd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]
2017-07-28 v0.6 camexport and prototype sent
    [emonDCmini v0.7 RTC.brd, emonDCmini v0.7 RTC.sch]
2017-07-30 v1.0 duo camexport and prototype
    [emonDCduo-ESP v1.0.brd, emonDCduo-ESP v1.0.sch]
2017-10-09 new boards and library files
    [EmonDCShieldv0.1.brd, EmonDCShieldv0.1.sch, ISO-UART v0.1.brd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]
2017-10-09 deleted libs
    [emonDCmini v0.5.brd, emonDCmini v0.5.sch, emonDCmini v0.6a.brd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]
2017-12-13 commit v1.3c
    [EmonDCShieldv0.1.brd, EmonDCShieldv0.1.sch, ISO-UART v0.1.brd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]
2017-12-14 commit v1.3c update
    [emonDCduo-ESP v1.1c.brd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]
2017-12-14 commit v1.1c update
    [emonDCduo-ESP v1.1c.brd]
2018-03-27 reorder files, deletion and archive
    [BOM emonDCduo-ESP v1.3.ods, BOM emonDCduo-ESP v1.3.xls, INDUCTANCE CALC.ods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]
2018-03-28 unzip firmware
    [BOM emonDCduo-ESP v1.3.ods, Resistor Divider.ods, Resistor divider for MAX5035EASA.ods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]
2018-03-30 v1.4 changes. firmware dev.
    [BOM emonDCduo-ESP v1.3.ods, emonDCduo-ESP v1.3.1.brd, emonDCduo-ESP v1.3.1.sch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]
2018-04-06 readme updated
    [BOM emonDCduo-ESP v1.3.ods, Resistor Divider.ods, emonDCduo-ESP v1.3.brd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]
2018-10-24 commit v3.0 WIP
    [emonDCduo-ESP v1.3.brd, emonDCduo-ESP v1.3.sch, emonDCduo-ESP v2.3_consistency_error.brd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]
2018-11-09 starting v3.0 and ASC770 breakout
    [ACS770 breakout v0.1.brd, ACS770 breakout v0.1.sch, ACS770 breakout v0.2.brd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]
2018-11-15 commit v3.0
    [ACS770 breakout v0.1.brd, ACS770 breakout v0.1.sch, ACS770 breakout v0.2.brd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]
2018-11-16 commit v3.1
    [emonDCduo-ESP v1.3.sch, emonDCduo-ESP v2.0 eaglev7.brd, emonDCduo-ESP v2.0 eaglev7.sch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]
2018-11-28 commit v3.2
    [Inductor Calculator for MAX5035.ods, MAX5035 UVLO Calculator.ods, Resistor Divider Temperature.ods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]
2018-12-06 commit v3.3
    added temp sensor
    [emonDCduo-ESP v3.2.brd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]
2018-12-06 commit v3.4
    curvy corners!
    [drills_1_16.xln, emonDCduo-ESP v3.3.GBL, emonDCduo-ESP v3.3.GBO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]
2018-12-06 commit v3.4
    [BOM emonDCduo-ESP v1.3.ods, BOM emonDCduo-ESP v1.4.ods, BoM for quote SMT only.xls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]
2018-12-09 commit v3.5 & 3dprintable case
    [BUCK REG.GBL, BUCK REG.GBO, BUCK REG.GBS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]
2018-12-12 commit v3.5
    [BUCK REG.GBL, BUCK REG.GBO, BUCK REG.GBS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]
2019-02-19 commit v3.7
    [emonDCduo-ESP v3.7.brd, emonDCduo-ESP v3.7.sch, emondcduo_case1d.stl]
2019-03-30 acs7** addition, emonBuck update
    [ACS770 breakout v0.1.brd, ACS770 breakout v0.1.sch, ACS770 breakout v0.2.brd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]
2019-04-13 commit v4.0
    [emonDCduo-ESP v3.5.brd, emonDCduo-ESP v3.5.sch, emonDCduo-ESP v3.7 BoM.xls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]
2019-04-23 commit v4.1
    [drills_1_16.xln, emonDCduo-ESP v3.5.GBL, emonDCduo-ESP v3.5.GBO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]
2019-04-27 commit v4.1
    HV isolation improvements
    [emonDCduo-ESP v4.1.brd, emonDCduo-ESP v4.1.sch]
2019-07-09 isoHV and emonDCmini added
    [2 module sketch.skp, Adafruit Feather M0 RFMxx copy headers.brd, Adafruit Feather M0 RFMxx copy headers.sch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]
2019-09-30 isoHV firmware update
    [Adafruit Feather M0 RFMxx copy headers.brd, Adafruit Feather M0 RFMxx copy headers.sch, Adafruit Feather M0 RFMxx.brd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]
2020-02-29 minor fix, notes added
    [emondc.cpp, wifi.cpp]
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2020-03-06 amplifier offset correction values added
    [emondc.cpp, src.ino]
2020-03-29 update
    maaaany fixes.
    State of Charge battery monitoring first draft.
    [emondc.cpp, gpio0.cpp, src.ino]
2020-06-10 report min and max voltage and current each reporting interval
    [Resistor Divider Temperature.ods]
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

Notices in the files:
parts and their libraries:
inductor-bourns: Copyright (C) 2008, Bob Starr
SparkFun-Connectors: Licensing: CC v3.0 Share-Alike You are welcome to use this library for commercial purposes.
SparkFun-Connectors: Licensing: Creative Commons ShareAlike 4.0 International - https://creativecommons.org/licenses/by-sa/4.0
